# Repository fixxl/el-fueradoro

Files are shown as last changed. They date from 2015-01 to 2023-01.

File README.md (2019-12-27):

# el-fueradoro

This project contains a remotely controlled ignition system for audio-fireworks based on ATmega328P and RFM69CW.
Further information (in German) is given in [the user manual](https://cdn.jsdelivr.net/gh/fixxl/el-fueradoro@master/Manual/fueradoro.pdf).

What the system is capable of doing can be seen in our [new year's fireworks 2015](https://vimeo.com/116115628), [new year's fireworks 2016](https://vimeo.com/150594996), [new year's fireworks 2017](https://www.youtube.com/watch?v=Rc5oZRx3s50), [new year's fireworks 2018](https://www.youtube.com/watch?v=unH9tJSg1mw), and [new year's fireworks 2019](https://www.youtube.com/watch?v=GiKSdqZKpVQ).

Copyright:

All parts of the project are licensed under: https://creativecommons.org/licenses/by-nc/3.0/de/

Usage to perform commercial firework shows is explicitly granted.
Selling hard- and software derived from this project and usage within commercial systems is prohibited.

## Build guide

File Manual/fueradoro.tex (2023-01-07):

\documentclass[paper=a4, parskip, numbers=noenddot, toc=listof, headsepline]{scrbook}

\usepackage[hang]{caption}
\usepackage{subcaption}
\usepackage{microtype, textcomp}
\usepackage{longtable, xltabular}
\usepackage[intlimits]{mathtools}
\usepackage{amsfonts, amssymb, array, scrlayer-scrpage, multirow}
\usepackage{fontspec}
\usepackage{unicode-math, icomma}
\usepackage{polyglossia}
\setdefaultlanguage[spelling=new]{german}
\usepackage[autostyle]{csquotes}
\usepackage[per-mode=fraction, locale=DE, detect-all=true, binary-units=true]{siunitx}
\usepackage[scale=.73]{geometry}
\usepackage{graphicx}
\usepackage{datetime}
\usepackage[backend=biber, isbn=false, doi=false, eprint=false, url=true, safeinputenc, defernumbers=false]{biblatex}
\usepackage[unicode=true, colorlinks=false, breaklinks=true, pdfborder={0 0 0}]{hyperref}
\usepackage{bookmark}

\newcommand{\origttfamily}{}
\let\origttfamily=\ttfamily
\renewcommand{\ttfamily}{\origttfamily \hyphenchar\font=`\-}
\defaultfontfeatures{Ligatures=TeX}
\renewcommand{\dateseparator}{.}
\newcolumntype{C}{>{\centering\arraybackslash}X}

\setmainfont{Tex Gyre Termes}
\setmathfont{Tex Gyre Termes Math}
\setsansfont{Latin Modern Sans}[Scale=MatchLowercase]
\setmonofont{LMMonoLt10-Bold}[Scale=MatchLowercase]

\newfontfamily\Driftwood{Drift Wood}

\newcommand{\pic}{\emph{Pyro Ignition Control}}
\newcommand{\anlage}{\emph{El Fueradoro}}
\newcommand{\REF}{\emph{raspEasyFire}}
\newcommand{\myangle}{\ifthispageodd{angle=-90}{angle=90}}

\newdateformat{mmyyyydate}{\twodigit{\THEMONTH}-{\THEYEAR}}

%% Seitenstil-Einstellung
\renewcommand{\chapterpagestyle}{plain}
\pagestyle{scrheadings}
\renewcommand*{\partmarkformat}{}
\automark[part]{part}
\clearpairofpagestyles
\ohead[\pagemark]{\pagemark}
\lohead[]{\textnormal\headmark}
\rehead[]{\anlage}

\hyphenation{Putty-tel, Fuera-doro}

\setuptoc{toc}{totoc}

\hypersetup{pdfinfo={
		Title=\anlage + \REF,
		Author=Felix Pflaum,
		Subject={User manual for remotely controlled firework ignition system},
		Keywords={}}
}

\makeatletter
\@removefromreset{footnote}{part}
\@removefromreset{footnote}{chapter}
\makeatother

\DeclareSIUnit{\dBm}{dBm}

\begin{document}
\begin{titlepage}
	\thispagestyle{empty}
	{\sffamily\LARGE Benutzerhandbuch{\hfill}Dokumentation{\hfill}Aufbauanleitung}\\ \hrule \vspace*{\fill}
    \begin{center}
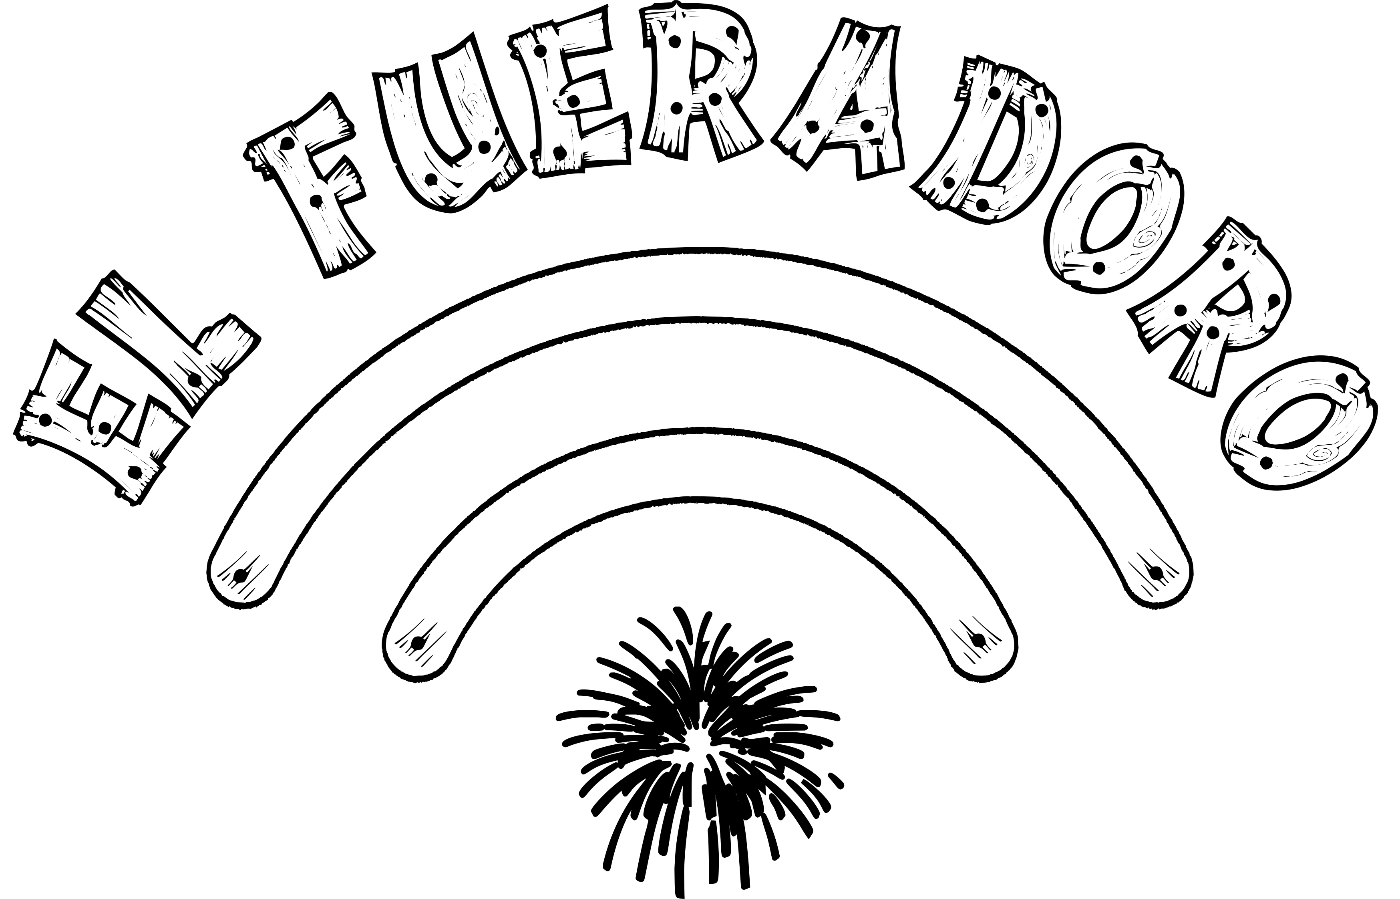
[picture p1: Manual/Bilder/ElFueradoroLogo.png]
    	 \\ \vspace*{\fill}
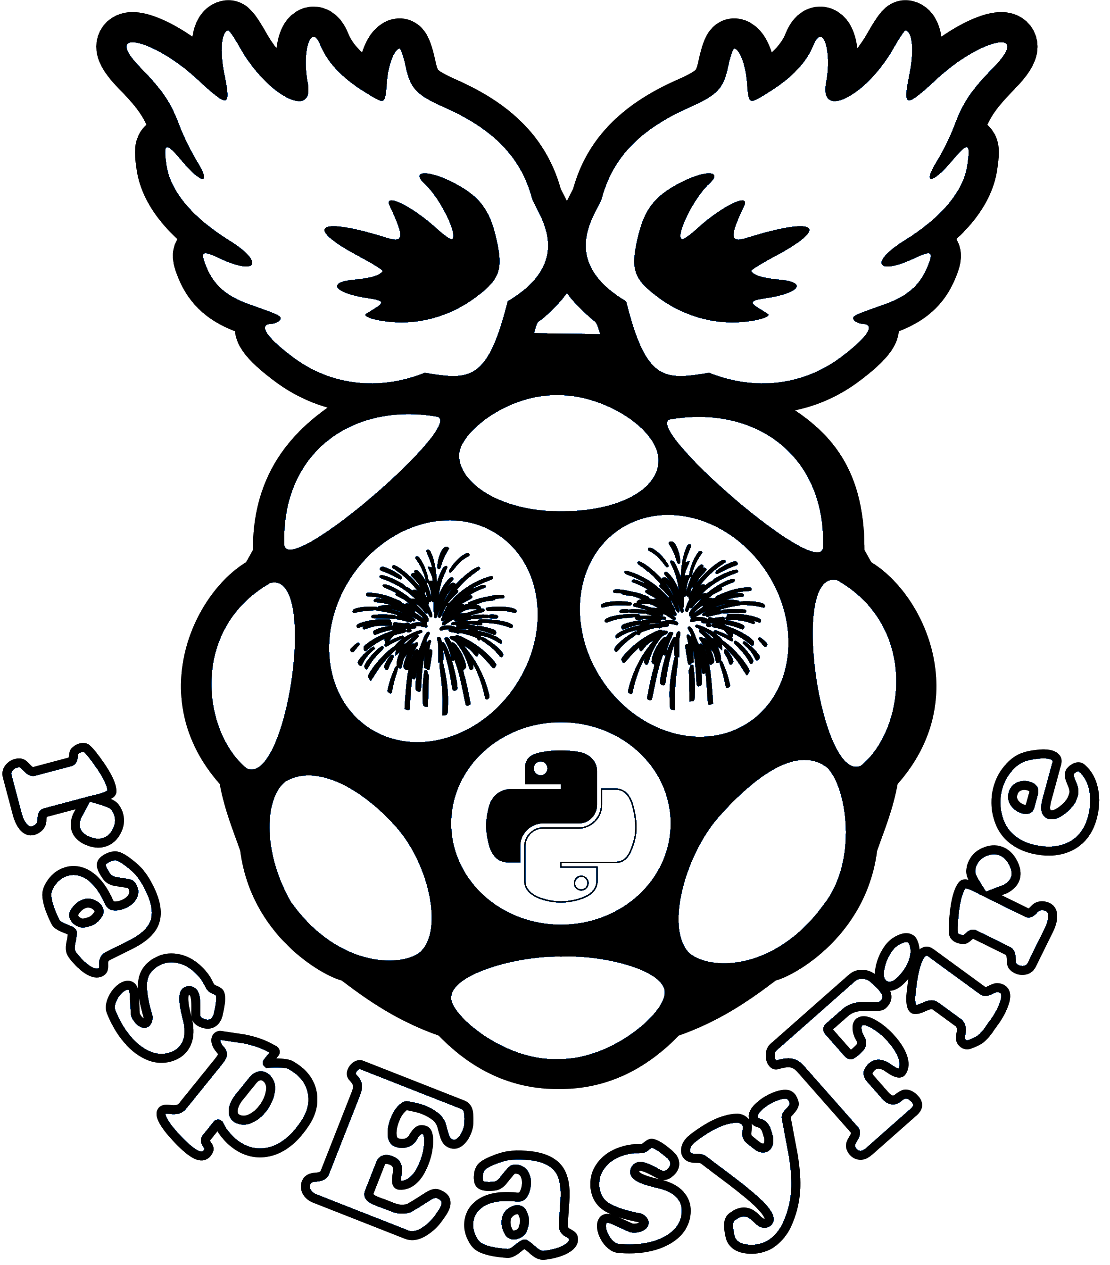
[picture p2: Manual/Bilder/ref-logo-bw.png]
		   \\ \vspace*{\fill}
		{\LARGE \sffamily Funkgesteuertes Zündsystem für Feuerwerke}
	\end{center}
	\vspace*{\fill}
	\hrule
	\begin{center}
		\sffamily\Large Felix Pflaum (\href{mailto:f.pflaum@gmail.com}{f.pflaum@gmail.com})\\
		\normalsize \ddmmyyyydate\today, \currenttime
	\end{center}
\end{titlepage}
%
\chapter*{Wichtige Hinweise}
	\addcontentsline{toc}{chapter}{Wichtige Hinweise}

	Vor Inbetriebnahme sollte in jedem Fall diese Anleitung gelesen und verstanden werden! Speziell die folgenden, weiter hinten in der Anleitung detaillierter ausgeführten Hinweise müssen beachtet werden, um Personenschäden oder Beschädigungen an den Geräten zu vermeiden:

	{\bfseries
	\begin{enumerate}
		\item
		      Bei den Zündboxen der ersten Generation liegt das Metallgehäuse des SMA-Antennen\-anschlusses an der Oberseite der Zündbox auf Massepotential, die roten Anschlussklemmen nach dem Einschalten und unter Umständen auch noch Minuten nach dem Ausschalten bei \SI{22,5}{\volt}. Ein Kurzschluss zwischen diesen beiden Punkten ist daher unbedingt zu vermeiden, um Schäden an der Schaltung und ungewollte Zündungen zu verhindern. Daher, sofern der Antennenanschluss nicht isoliert ist, beim Anschließen die Anzünder immer zuerst mit der schwarzen Klemme, danach mit der roten verbinden, beim Abklemmen zuerst das Kabel an der roten, dann das an der schwarzen Klemme lösen. Weiterhin sollte man die Zündbox erst in ihrer endgültigen Position einschalten, so dass ein unbeabsichtigtes Herausziehen der Kabel tunlichst ausgeschlossen ist. Sicherheitshalber kann auch der SMA-Stecker nach dem Anschrauben mit Klebeband isoliert werden. Bei den Zündboxen ab der zweiten Generation sind schaltungstechnische Maßnahmen getroffen, um den Strom im Kurzschlussfall zu begrenzen und ein Auslösen der Anzünder bei Verbindung zwischen roter Klemme und Antennenanschluss im nicht-scharfgeschalteten Zustand auszuschließen.
		\item
		      Devices niemals ohne angeschlossene Antenne einschalten, um Rückreflexionen an offenen Steckern/Buchsen zu vermeiden, welche die Sendeendstufe zerstören könnten.
		\item
		      Keine Softwareupdates an Zündboxen durchführen, solange Anzünder angeschlossen sind, da das Verhalten nach einem fehlgeschlagenen Update unvorhersehbar ist.
	\end{enumerate}
	}

	Trotz aller Sorgfalt bei der Entwicklung von Hard- und Software sowie ausgiebigen Tests seitens der Entwickler kann~-- auch aufgrund nicht vorhandener Kontrollmöglichkeiten über die Qualität der letztlich verbauten Komponenten und der handwerklichen Durchführung~-- keinerlei Garantie für Sicherheit und Funktionalität von {\anlage} und {\REF} sowie keine Haftung für Sach- und Personenschäden, welche sich direkt oder indirekt aus dem Einsatz von {\anlage} und {\REF} ergeben, übernommen werden.

	Es werden mit {\anlage} dem Anwender lediglich Schaltpläne, Layouts und Programmcode sowie Hinweise zu Aufbau und Verwendung einer elektronischen Funkzündanlage, welche er frei weiter verbreiten und~-- selbstverständlich auf eigene Gefahr~-- verändern darf, zur Verfügung gestellt. {\anlage} und {\REF} sind und bleiben Hobby-Bastelprojekte, keine geprüften oder in irgendeiner Form zertifizierten Produkte!

	Der Umgang mit Feuerwerkskörpern und explosivem Material unterliegt in Deutschland und der EU harmonisierten wie auch nationalen gesetzlichen Restriktionen, deren Einhaltung im Verantwortungsbereich des Anwenders liegt. Insbesondere auf Sicherheitsabstände und persönliche Schutzausrüstung ist zu achten. {\anlage} und {\REF} dürfen nicht von Personen unter 18 Jahren bedient werden.
	%

	\tableofcontents
	%
\part{Benutzerhandbuch}

	\chapter{Das System}

		\anlage{} ist eine Eigenentwicklung zur automatisierten Zündung von Feuer\-werks\-choreo\-gra\-phien per Computer und Funk, der Name {\anlage} leitet sich als Kofferwort aus den spanischen Wörtern \emph{fuego}, \emph{radio} und \emph{oro} her und bedeutet frei übersetzt daher so etwas wie \enquote{Goldenes Funkfeuer}. Sie wurde zur Verwendung mit der frei verfügbaren Software {\pic} von Yannic Wilkening (Version 1.4.5 und später) geplant.

		Das ursprüngliche System bestand aus einer mit einem PC verbundenen Transmitterbox, welche die von {\pic} generierten Zündbefehle per Funk an die Zündboxen weitergibt, und einer oder mehreren Zündboxen mit je 16 oder 32 Kanälen zur elektrischen Zündung. Dieser klassische Aufbau des Systems ist schematisch in Abbildung~\ref{fig:system} gezeigt. Die reine Transmitterbox wird nicht zwingend benötigt; es kann alternativ auch eine Zündbox per Kabel mit dem PC verbunden werden und neben ihrer originären Aufgabe auch die Transmitteraufgaben bewältigen.

		Mittlerweile hat sich als Standalone-Lösung, also als Ersatz für Transmitterbox und PC, der Raspberry-Pi-Transmitter \emph{raspEasyFire} etabliert, welcher einen deutlich größeren Funktionsumfang bietet als die ursprüngliche Variante.

		\begin{figure}
			\centering
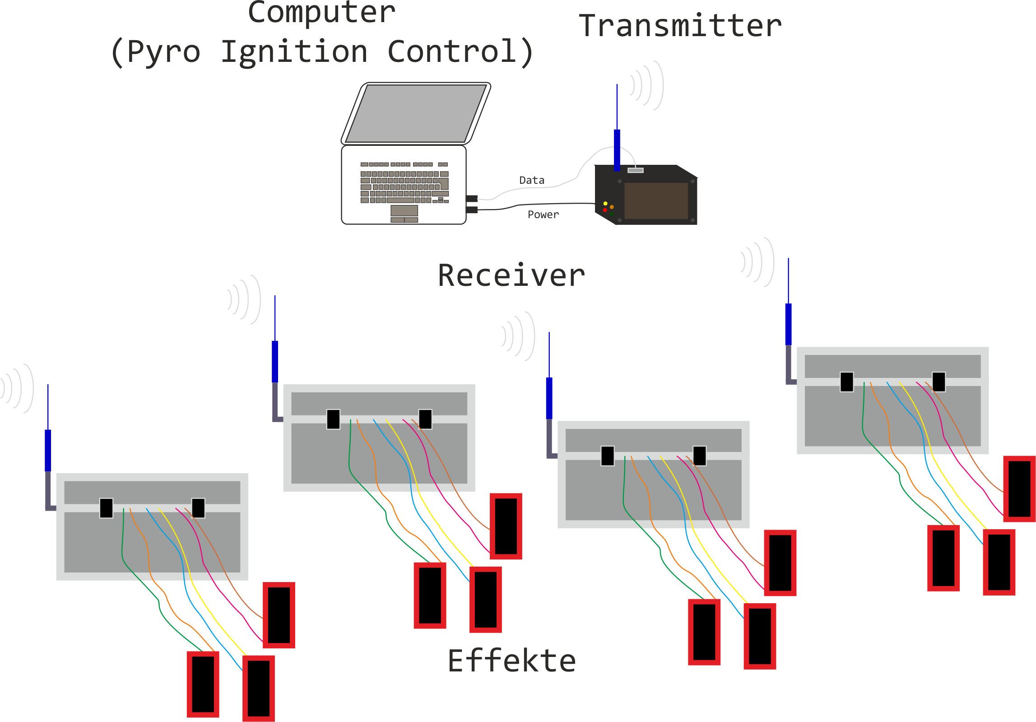
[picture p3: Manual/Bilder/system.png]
			
			\caption{Systemübersicht \anlage}
			\label{fig:system}
		\end{figure}

		Um möglichst große Flexibilität bei der Gestaltung eines Feuerwerks mit {\anlage} zu gewährleisten, was z.\,B. die Anzahl der verwendeten Zündboxen oder auch die Tatsache angeht, dass man identische Effekte gerne zeitgleich an zwei weiter voneinander entfernten Orten zünden möchte, können den Boxen per Software zwei Kennnummern (Unique-ID und Slave-ID) zugewiesen werden. Genaueres dazu findet sich im Abschnitt~\ref{ch:kommunikationpc}.

		Transmitterbox und Zündbox sind in Abbildung~\ref{fig:transmitter} bzw.~\ref{fig:zuendbox} mit ihren wesentlichen Bestandteilen gezeigt. Sie werden im weiteren Text unter dem Begriff \enquote{Devices} zusammengefasst, falls sich Aussagen auf beide Teile beziehen, und in den folgenden Kapiteln näher beschrieben.

		Um den Raspberry-Pi-basierten Transmitter \emph{raspEasyFire} geht es in Abschnitt~\ref{ch:raspeasyfire} ab Seite~\pageref{ch:raspeasyfire}.

		\section{Aufbau}

			Detailliertere Infos zum Aufbau erhalten interessierte Leser in den nächsten Teilen dieses Dokuments ab Seite~\pageref{part:dokumentation}. An dieser Stelle soll nur kurz auf die Funktionalität eingegangen werden. Herzstück aller Devices ist der 8-bit-Mikrocontroller \texttt{ATmega328P} von Atmel, welcher die verschiedenen Peripheriebausteine kontrolliert. In jedem Device befinden sich ein Funkmodul \texttt{RFM69CW} oder \texttt{RFM69HCW} von HopeRF, welches die drahtlose Kommunikation zwischen den einzelnen Devices übernimmt, ein RS232-Treiberbaustein \texttt{MAX202} mit an die Gehäuseaußenseite geführter Sub-D-Buchse bzw. ab der dritten Generation ein USB-UART-Transceiver \texttt{MCP2221} mit USB-Buchse zur Kommunikation zwischen Mikrocontroller und PC sowie vier Status-LEDs.

			Die Transmitterbox ist mit einem LC-Display mit 20 Spalten und 4 Zeilen ausgestattet.

			In den Zündboxen befinden sich zwei vom Mikrocontroller gesteuerte kaskadierte Schieberegister \texttt{74HC595}, welche mit ihren insgesamt 16 bzw. 32 Ausgängen 16 bzw. 32 Feldeffekttransistoren vom Typ \texttt{IRF3708} für die Zündung ansteuern, außerdem ist auf der Platine mit dem \texttt{MC33063} bzw. einem fertigen Modul mit dem \texttt{XL6009} ein Hochsetzsteller zur Erzeugung einer höheren Zündspannung integriert sowie ein Schlüsselschalter zum Scharfschalten der Boxen. Bei den ersten beiden Generationen liegt parallel zur Drain-Source-Strecke jedes Feldeffekttransistors eine LED mit Vorwiderstand, um zu signalisieren, an welchen Kanälen Anzünder angeschlossen sind. Ab der dritten Generation werden diese Kanal-LEDs über LED-Treiber \texttt{DM13A} angesteuert, um genauere Informationen über den Kanalzustand und weitere Funktionen darstellen zu können.

		\section{Transmitter und Zündboxen}

			\begin{figure}
				\centering
				\begin{subfigure}[t]{0.405\textwidth}
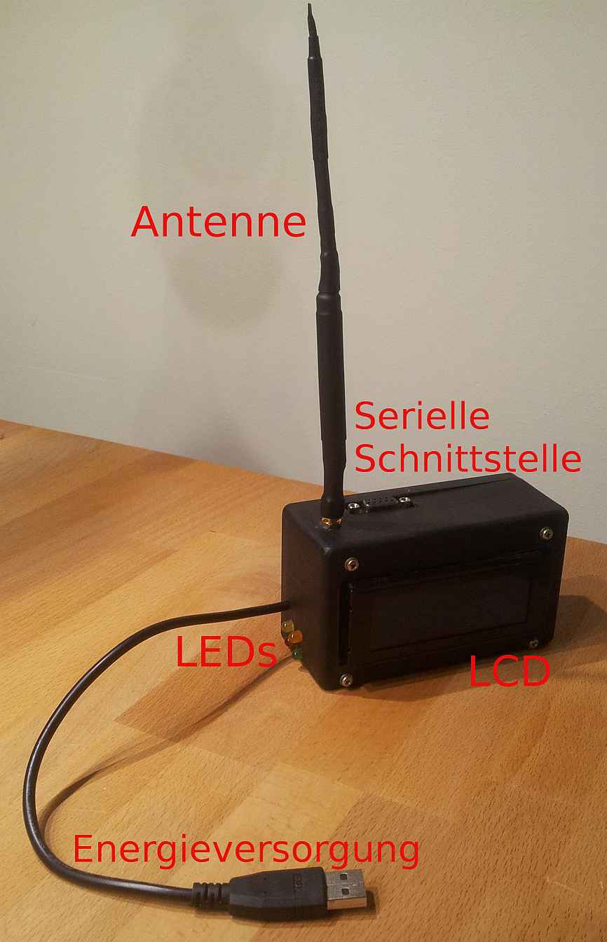
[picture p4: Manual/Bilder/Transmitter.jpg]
					
					\caption{Transmitter}
					\label{fig:transmitter}
				\end{subfigure}
				\begin{subfigure}[t]{0.55\textwidth}
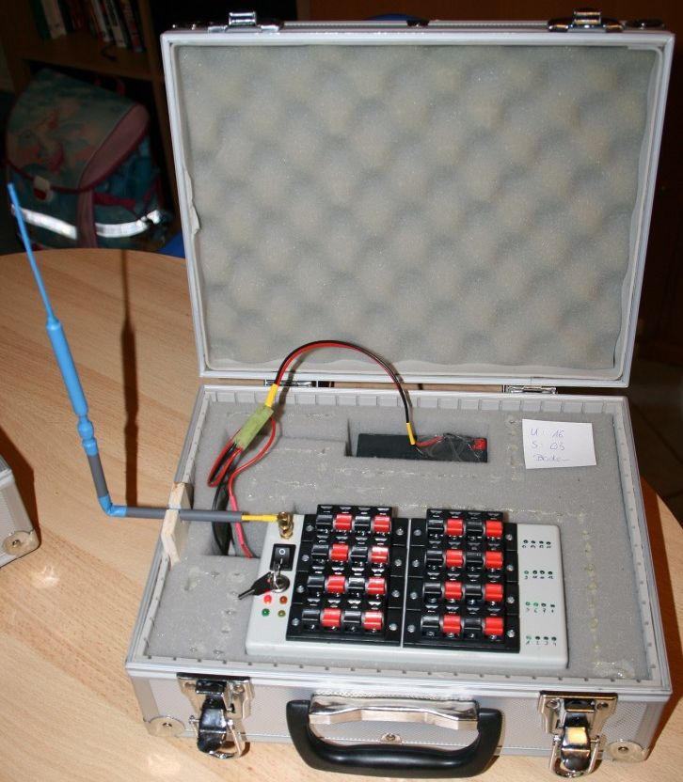
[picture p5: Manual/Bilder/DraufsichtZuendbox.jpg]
					
					\caption{Zündbox von oben, eingebettet in Koffer}
					\label{fig:zuendbox}
				\end{subfigure}
				%
				\caption{Die Devices von {\anlage}}
			\end{figure}

			Die in Abbildung~\ref{fig:transmitter} gezeigte Transmitterbox dient dazu, die Zündbefehle des PCs per Funk an die über das Gelände verteilt stehenden Zündboxen weiterzuleiten sowie das komplette Funksystem zu überwachen. Hierzu ist im Inneren der Transmitterbox sowie der Zündboxen ein Funkmodul für das~-- im Rahmen der Vorschriften der jeweiligen nationalen Aufsichtsbehörde, in Deutschland der Bundesnetzagentur~-- frei nutzbare Frequenzband um $\SI{868}{\mega\hertz}$ verbaut, das ISM-Band um $\SI{433}{\mega\hertz}$ kann ebenfalls genutzt werden. Die Datenübertragung vom PC geschieht über eine serielle Schnittstelle.

			Die Zündboxen, in Abbildung~\ref{fig:zuendbox} dargestellt, empfangen die Anweisungen und zünden die einzelnen Kanäle. Die hier gezeigte Variante der Zündbox enthält 16 einzeln ansteuerbare Zündkanäle. Jeweils eine rote und eine schwarze Klemme bilden zusammen einen Zündkanal, die Nummerierung beginnt links unten mit Kanal 1 und endet rechts oben mit Kanal 16. Alle roten Klemmen sind nach dem Einschalten unmittelbar mit einer Gleichspannung von $\SI{22,5}{\volt}$ verbunden, die schwarzen Klemmen mit dem Drain-Anschluss eines von 16~n-Kanal-MOSFETs.

			Welches der beiden Kabel an welcher Klemme des Zündkanals angeschlossen wird, spielt keine Rolle, da es sich bei den Anzündern um passive elektrische Bauelemente handelt, die in beiden Richtungen gleichermaßen von Strom durchflossen werden können. Die Verdrahtung sollte aber stets im ausgeschalteten Zustand der Boxen erfolgen und aus Sicherheitsgründen immer in folgender Reihenfolge:
			\begin{itemize}
				\item
				      Beim Anklemmen der Kabel zuerst ein Kabel an der schwarzen Klemme befestigen, anschließend das andere an der roten!
				\item
				      Beim Lösen der Kabel zuerst das Kabel von der roten Klemme lösen, anschließend das von der schwarzen!
			\end{itemize}
			Dies ist der Tatsache geschuldet, dass bei der ersten Generation der Zündboxen, wenn eine Seite des Zündkanals fest mit der Zündspannung, d.\,h. einer roten Klemme verbunden ist, ein frei baumelndes zweites Kabel durch Berührung eines Bauteils auf Massepotential, z.\,B. der Antennenbuchse oder der Überwurfmutter des gewinkelten SMA-Steckers, einen Kurzschluss und somit eine Zündung auslösen würde~-- selbst dann, wenn die Box nicht scharf geschaltet ist! Ab der zweiten Generation der Zündboxen ist dieses Manko behoben.

			Bei den Zündboxen der ersten und zweiten Generation ist parallel zur üblicherweise sperrenden Drain-Source-Strecke jedes MOSFETs ist eine grüne LED mit Vorwiderstand geschaltet, welcher den Strom durch den LED-Zweig auf unter \SI{5}{\milli\ampere} begrenzt, so dass ein Zünden über die LED ausgeschlossen ist. Sobald die zugehörige schwarze Klemme mit einer roten Klemme~-- die Zuordnung kann beliebig erfolgen, obwohl zwecks Übersichtlichkeit natürlich ratsam ist, die nebeneinander liegenden Klemmen zu nutzen~-- verbunden ist, also ein geschlossener Strompfad von $\SI{22,5}{\volt}$ zur Schaltungsmasse besteht, wird dies durch Leuchten der zur schwarzen Klemme gehörigen grünen LED signalisiert. Ein Leuchten der grünen LED ist dabei lediglich ein Indikator, dass \enquote{etwas} am jeweiligen Kanal angeschlossen ist, eine Aussage, ob der Widerstand des angeschlossenen Anzündernetzwerks gering genug ist, um eine Zündung auszulösen, wird durch die LED ausdrücklich nicht getroffen.

			Anders verhält sich dies bei den Zündboxen der dritten Generation: Hier werden die Widerstände der einzelnen Kanäle periodisch bestimmt und die zugehörige grüne LED nur dann aktiviert, wenn der Kanalwiderstand ausreichend gering ist.

		\section{Energieversorgung}

			Die in unmittelbarer Nähe des zu steuernden PCs platzierte Transmitterbox bezieht ihre nötige elektrische Energie aus dem USB-Port eines PCs. Das fest mit der Transmitterbox verbundene USB-Kabel dient ausschließlich diesem Zweck. Sie verfügt über keinen Ein/Aus-Schalter, sondern ist eingeschaltet, solange sie mit dem USB-Port verbunden und der PC eingeschaltet ist. Da der USB-Port \enquote{angezapft} wird, ohne in der sonst üblichen Weise mit dem Controller zu kommunizieren, empfiehlt sich, die USB-Verbindung erst nach komplett abgeschlossenem Bootvorgang herzustellen und vor dem Herunterfahren des Rechners wieder zu trennen.

			Aufgrund der anzunehmenden Platzierung der Zündboxen im freien Feld, abseits von Steckdosen und anderen Energiequellen werden sie über eine Batterie versorgt. \textbf{Um ordnungsgemäße Funktionalität zu garantieren und Schäden an der Schaltung zu vermeiden, muss die Batteriespannung zwischen \SI{8}{\volt} und \SI{15}{\volt} liegen!} Empfohlen wird die Verwendung eines Blei-Vlies-Akkus mit Nennspannung \SI{12}{\volt}, wie er auch in Abbildung~\ref{fig:zuendbox} über der Zündbox zu erahnen ist.

		\section{Die Status-LEDs}
			\label{ch:leds}

			Alle Devices verfügen über vier Status-LEDs. Bei den Transmitterboxen liegen sie direkt neben dem Kabel für die Energieversorgung auf der Seite, bei den Zündboxen auf der Oberseite. Diese sind mit ihrer Bedeutung in Tabelle~\ref{tab:statusleds} aufgeführt und leuchten, wenn das jeweilige Device die mit der LED verknüpfte Tätigkeit ausführt.

			\begin{table}
				\centering
				\begin{xltabular}{.8\textwidth}[c]{lXl}
					\hline\hline
					\textbf{Farbe} & \textbf{Funktion}                           & \textbf{Startup-Faktor} \\ \hline
					orange         & Funkmodul empfängt                          & 4                       \\
					grün           & Funkmodul sendet                            & 2                       \\
					gelb           & Daten kommen über serielle Schnittstelle an & 1                       \\
					rot            & Device ist scharf geschaltet                & 8                       \\ \hline\hline
				\end{xltabular}
				\caption{Farben und Funktionen der Status-LEDs}
				\label{tab:statusleds}
			\end{table}

			Während des Bootvorgangs wird durch die Status-LEDs dem Benutzer die aktuell eingestellte Slave-ID der Box in Binärdarstellung visualisiert. Hierzu gehen zunächst nacheinander schnell die gelbe, grüne, orange und rote LED an, ehe zwei Sekunden lang eine Kombination der Status-LEDs aufleuchtet. Anschließend gehen nacheinander schnell die rote, orange, grüne und gelbe LED an, bevor erneut zwei Sekunden lang eine weitere Kombination der Status-LEDs leuchtet. Der Zahlenwert, welcher durch eine Status-LED repräsentiert wird, ist in Tabelle~\ref{tab:statusleds} aufgeführt. Die eingestellte Slave-ID entspricht der Summe aus dem Wert der ersten Kombination multipliziert mit 16 und der zweiten Kombination.

			Beispiel: Leuchtet nach dem ersten Lauflicht zunächst zwei Sekunden lang nur die gelbe LED und nach der zweiten Lauflichtsequenz leuchten zwei Sekunden die orange und grüne LED zusammen, ergibt sich die Slave-ID zu $16 {\cdot} 1 + 4 + 2 = 22$.

			Ab der dritten Generation werden während dieser Sequenz auch alle Kanal-LEDs eingeschaltet, um defekte LEDs erkennen zu können.

			Das nach kurzer Pause folgende Blinken der grünen LED signalisiert dann die Statusmeldung per Funk an allen anderen Devices.

			Bei einem Zündvorgang leuchten an der Zündbox für die einstellbare Dauer der Zündung~-- näheres hierzu im Abschnitt~\ref{sec:igniter}~-- alle vier LEDs, bei Zündboxen ab der dritten Generation zusätzlich auch die zum gezündeten Kanal zugehörige Kanal-LED.

		\section{Das LCD des Transmitters}

			Aktuelle Statusanzeigen werden beim Transmitter auf dem LC-Display ausgegeben. Ein Beispiel zeigt Abbildung~\ref{fig:senderanzeige}. In Zeile 1 wird hinter der Abkürzung \enquote{Tx} (Transmitted) der letzte gesendete Befehl angezeigt, in Zeile 2~-- im Bild nicht zu sehen~-- ggf. hinter der Abkürzung \enquote{Rx} (Received) die letzte empfangene Rückmeldung (angeforderte Parameter). Die am Ende der zweiten Zeile erscheinende negative Zahl steht für den RSSI-Wert beim Empfang in dBm.

			\begin{figure}
				\centering
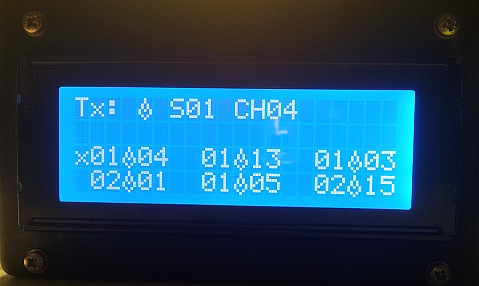
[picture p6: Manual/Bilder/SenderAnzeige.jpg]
				
				\caption{LCD während der Show}
				\label{fig:senderanzeige}
			\end{figure}

			In den Zeilen 3 und 4 werden die letzten sechs gesendeten Kommandos aufgelistet. Zwei zweistellige Zahlen getrennt durch ein Flammensymbol stehen dabei für einen Zündbefehl. Die erste Zahl gibt die Slave-ID, die zweite den zu zündenden Kanal an. Für den Fall, dass eine Aufforderung zur Identifikation gesendet wurde, erscheint \enquote{IDENT}, für eine Aufforderung zur Temperaturmessung \enquote{TEMP}. Das \enquote{x} steht immer vor dem bis dato letzten Befehl, springt also mit jedem neuen Befehl eine Stelle weiter.

			Alle Zeilen werden nach einer bestimmten Zeit automatisch gelöscht.

		\section{Schalter an den Zündboxen}

			Die Zündboxen verfügen, wie in Abbildung~\ref{fig:schalterzuend} zu erkennen, über zwei Schalter, einen schwarzen Wippschalter zum Ein- und Ausschalten der Energieversorgung sowie einen Schlüsselschalter, um die Zündbox \enquote{scharf} zu schalten.

			\begin{figure}[!b]
				\centering
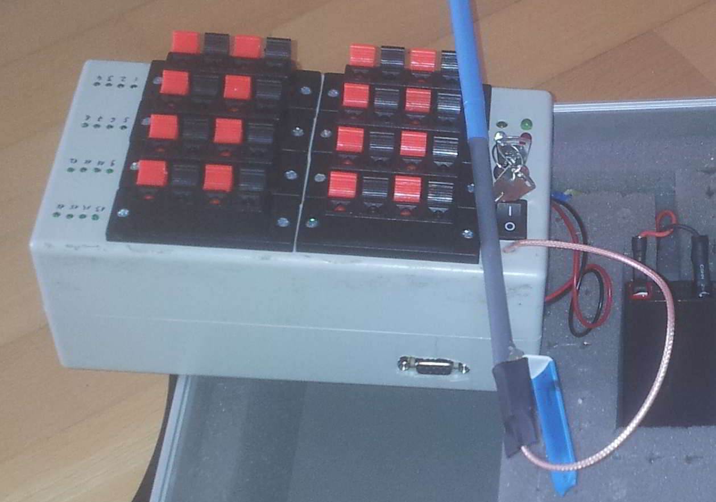
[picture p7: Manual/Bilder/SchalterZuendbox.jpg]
				
				\caption{Schalter und serielle Schnittstelle an der Zündbox}
				\label{fig:schalterzuend}
			\end{figure}

			Die Scharfschaltung durch den Schlüsselschalter geschieht auf die Weise, dass durch eine Zustandsabfrage vor der Zündung letztere nur ausgeführt wird, wenn das Schloss auf den grünen Punkt am Gehäuse zeigt. Befindet sich der Schlüssel in waagrechter Stellung und zeigt auf den roten Punkt, so ist der Schalter geöffnet und Zündbefehle werden von der Box ignoriert. Für das Scharfschalten der Box ist der Anwender selbst verantwortlich.

			Ob Boxen scharf geschaltet sind, ist an der Box~-- wie in Abschnitt~\ref{ch:leds} ausgeführt~-- durch das Dauerleuchten der roten Status-LED erkennbar, kann aber auch durch eine Identifizierungsabfrage ausgelesen werden (siehe Abschnitt~\ref{sec:config}).

	\chapter{Vorbereitung des PCs}

		Zur Kommunikation mit einem Computer verfügen alle Devices über eine serielle Schnittstelle bzw. ab der dritten Generation über einen USB-Anschluss. {\pic} sollte ohnehin auf dem Rechner installiert sein, für die serielle Kommunikation gibt es für Windows zudem zahlreiche Terminalprogramme.

		\section{Installation eines USB-RS232-Adapters}
			\label{sec:usbadapter}

			Zunächst steht man allerdings in der Regel vor dem Problem, dass zwar die Devices eine serielle Schnittstelle besitzen, moderne Rechner aber nicht mehr mit dem früher standardmäßig verbauten 9-poligen Sub-D-Stecker der RS232-Schnittstelle ausgestattet sind. Diese wurden seit dem Ende der 1990er-Jahre von den USB-Schnittstellen verdrängt. Sollte wider Erwarten am einzusetzenden Rechner ein derartiger Anschluss vorhanden sein, können die nächsten Absätze übersprungen und der COM-Port direkt im Gerätemanager anhand von Tabelle~\ref{tab:seriell} konfiguriert werden. Wer nur über USB-Ports verfügt, lese unmittelbar weiter.

			Weil in vielen Bereichen noch immer auf RS232 zurückgegriffen wird, existieren Adapterkabel wie in Abbildung~\ref{fig:transmitter} mit USB-Anschluss für den Rechner und einem 9-poligen RS232-Stecker für den Anschluss an der Peripherie, also die Devices von {\anlage}. In diesen Adapterkabeln ist ein Chip verbaut, um die Signalumsetzung von USB auf RS232 und umgekehrt zu bewerkstelligen. Übliche verwendete Chips sind der CH340\footnote{Treiber CH340/341: \url{http://wch.cn/download/list.asp?id=5}}, welcher sich in vielen über eBay aus China angebotenen Modellen befindet, der Prolific PL2303\footnote{Falls die automatische Treiberinstallation unter Windows fehlschlägt, funktioniert~-- mit zeitweiligen Aussetzern~-- oft der Treiber unter: \url{http://www.cartft.com/support/drivers/TFT/tftdrivers/GPS/PL2303_Prolific_GPS_1013_20090319.zip}} in verschiedenen Versionen oder~-- bei edleren und somit auch teureren Varianten~-- der uneingeschränkt zu empfehlende FTDI232, mit welchem die in den folgenden Abschnitten beschriebenen Probleme nicht auftreten sollten.

			Das Plug-and-Play-Traum\-szenario, dass sich der Adapter bei der Verbindung des USB-Steckers mit dem Rechner automatisch korrekt installiert, tritt gerade bei den günstigen Adaptern leider nur sehr selten ein. Die in den Fußnoten verlinkten Treiber sollten, sofern die automatische Treiberinstallation von Windows versagt, ihren Dienst tun, müssen allerdings teilweise mit sanfter Gewalt installiert werden. Hat man die Installation erfolgreich absolviert, sollte bei angeschlossenem Adapterkabel ein neuer Eintrag in der Art von Abbildung~\ref{fig:geraetemanager} im Gerätemanager auftauchen.

			Weil viele Chips dazu tendieren, sich beim Anschluss an immer wieder andere USB-Ports neu zu installieren bzw. eine andere COM-Port-Nummer anzunehmen, wird empfohlen, für den USB-RS232-Adapter stets denselben USB-Steckplatz zu nutzen.

			\begin{figure}
				\centering
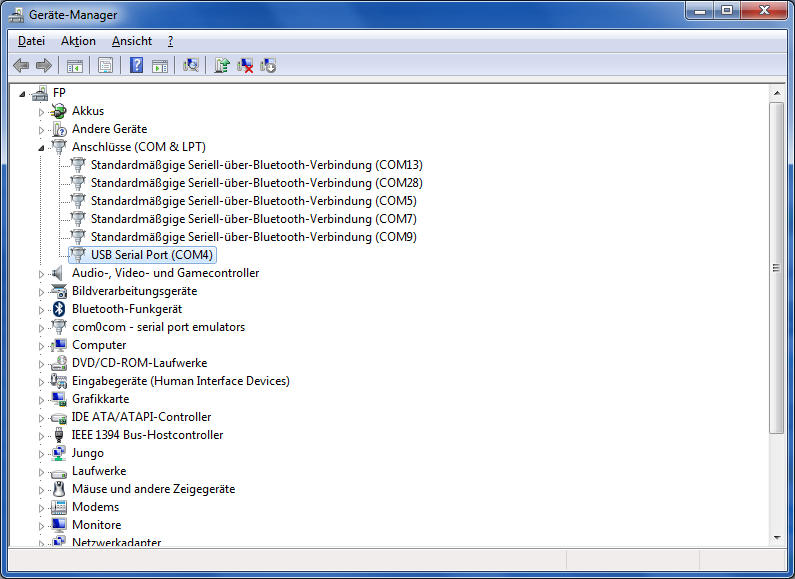
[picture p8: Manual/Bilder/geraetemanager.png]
				
				\caption{Eintrag des USB-RS232-Adapters im Gerätemanager}
				\label{fig:geraetemanager}
			\end{figure}

			Durch Doppelklick auf den Eintrag und den Reiter Anschlusseinstellungen kann die nun vorhandene serielle Schnittstelle unter Windows konfiguriert werden. Um Kompatibilität mit {\pic} zu gewährleisten, ist das Hauptfenster nach Tabelle~\ref{tab:seriell} zu konfigurieren.

			\begin{table}[b]
				\begin{center}
					\begin{xltabular}
						{7cm}[c]{Xl}
						\hline\hline
						Bits pro Sekunde & 9600  \\
						Datenbits        & 8     \\
						Parität          & keine \\
						Stoppbits        & 1     \\
						Flusssteuerung   & keine \\ \hline\hline
					\end{xltabular}
					\caption{Konfiguration der seriellen Schnittstelle}
					\label{tab:seriell}
				\end{center}
			\end{table}

			Unter der Schaltfläche \enquote{Erweitert} kann man zudem die Puffer ausschalten, was aber nicht zwingend notwendig ist und die Funktionsweise normalerweise weder positiv noch negativ beeinflusst, sowie die Portnummer für den neu geschaffenen COM-Port einstellen.

		\section{Einrichtung des Terminalprogramms}

			Hardware- und treiberseitig steht einer erfolgreichen Kommunikation von Rechner und Devices nun nichts mehr im Wege, für eine komfortable Unterhaltung außerhalb von {\pic} fehlt aber noch die entsprechende Software. Empfohlen wird die Verwendung des kostenlosen Programms \emph{Puttytel}\footnote{Herunterzuladen unter: \url{http://www.chiark.greenend.org.uk/~sgtatham/putty/download.html}}, mit welchem auch die im Rahmen dieser Anleitung gezeigten Beispiele durchgeführt werden. Es besteht nur aus einer einzigen ausführbaren Datei.

			\begin{figure}
				\centering
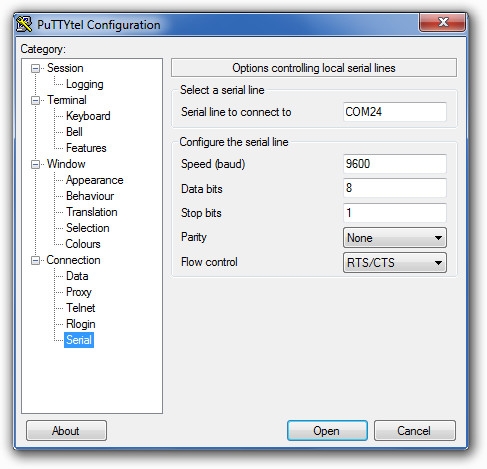
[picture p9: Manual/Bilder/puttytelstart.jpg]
				
				\caption{Einstellungen für \texttt{Puttytel}}
				\label{fig:puttytelstart}
			\end{figure}

			\texttt{Puttytel} kann per Doppelklick gestartet werden, woraufhin man zu einem Startbildschirm, der Kategorie \enquote{Session} gelangt. Man wählt in der linken Spalte unten links \enquote{Serial} und stellt die Parameter~-- analog zur Konfiguration des COM-Ports nach Tabelle~\ref{tab:seriell}~-- wie in Abbildung~\ref{fig:puttytelstart} ein. Anschließend muss man in der linken Spalte zurück auf \enquote{Session} gehen und dort im rechten Teil des Fensters \enquote{Serial} als \enquote{Connection Type} wählen, ehe man die serielle Verbindung per Klick auf \enquote{Open} starten kann. Vor dem Start der Verbindung sollte man zudem das verbundene Device mit Strom versorgen, damit dieses seine Kommunikationsschnittstelle vor Beginn des Datenaustauschs initialisieren kann.

			Um bei \texttt{Puttytel} nicht immer alle Einstellungen per Hand vornehmen zu müssen, bietet sich an, unter Windows eine Verknüpfung auf \texttt{puttytel.exe} zu erstellen und in den Ver\-knüpfungs\-eigen\-schaften als Ziel anzugeben:
			\begin{center}
				\verb|"c:\programme\puttytel\puttytel.exe" -serial com24 -sercfg 9600,8,1,n,R|
			\end{center}

			Die ohne Leerzeichen auf \enquote{com} folgende Zahl ist natürlich entsprechend dem verwendeten seriellen Anschluss (COM5, COM37, \dots) anzupassen.

		\section{Einrichtung von \pic}
			\label{sec:piceinrichtung}

			Um eine reibungslose Kommunikation zwischen {\pic} und {\anlage} sicherzustellen, muss in {\pic} als wesentliche Einstellung unter dem Menüpunkt \enquote{Einstellungen $\rightarrow$ Optionen} im Reiter \enquote{Output}~-- gezeigt in Abbildung~\ref{fig:pic-comport}~-- der richtige COM-Port eingestellt werden. Über \enquote{Einstellungen $\rightarrow$ Connect} wird die serielle Verbindung aufgebaut und in der untersten Leiste anzeigt, ob der Verbindungsaufbau erfolgreich war.

			Zudem sollte im Reiter \enquote{Allgemein} die globale Verzögerung erfahrungsgemäß, wie Abbildung~\ref{fig:pic-delay} zeigt, auf etwa 0,07\,s eingestellt werden. Dies ist die Zeit, die aufgrund von Datenübertragungen und Rechenvorgängen zwischen dem Beginn des Sendens des Befehls vom PC zum Transmitter und dem Zünden des Kanals an der Zündbox vergeht.

			Als minimale Zeitdauer zwischen zwei Zündungen sollte \SI{100}{\milli\second} nicht unterschritten werden, das Scharfschalten vor Beginn der Show ist ebenso nicht zu vergessen wie das Scharfschalten des Transmitters und sämtlicher Zündboxen!

			\textbf{Anmerkung: Eine serielle Verbindung zu einem Device kann immer nur durch einen einzigen Client (\texttt{Putty\-tel}, \texttt{GUI}, \texttt{\pic}, \texttt{Firware-Updater}) bestehen. Man muss also immer die bestehende Verbindung trennen, bevor man mit einem anderen Programm eine neue aufbauen kann.}

			\begin{figure}
				\begin{subfigure}[t]{\textwidth}
					\centering
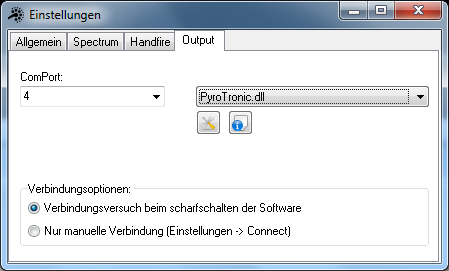
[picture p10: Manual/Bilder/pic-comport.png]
					
					\caption{Einstellung des COM-Ports in {\pic}}
					\label{fig:pic-comport}
				\end{subfigure}
				\\[50pt]
				\begin{subfigure}[t]{\textwidth}
					\centering
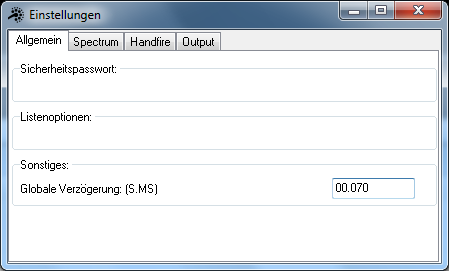
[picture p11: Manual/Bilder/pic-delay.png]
					
					\caption{Einstellung des Global Delay in \pic}
					\label{fig:pic-delay}
				\end{subfigure}
				\caption{Einstellungen in {\pic}}
			\end{figure}

	\chapter{Kommunikation zwischen PC und Devices}
		\label{ch:kommunikationpc}

		In diesem Abschnitt wird die Systemüberwachung bzw. -konfiguration über die serielle Schnittstelle mittels \texttt{Puttytel} oder die {\anlage}-GUI behandelt.

		Auf die Kommunikation zwischen {\pic} und der Transmitterbox wird an dieser Stelle nicht detailliert eingegangen, da hier~-- wenn alle Einstellungen wie in Abschnitt~\ref{sec:piceinrichtung} erläutert getroffen wurden~-- alles quasi-automatisch und ohne Zutun des Benutzers stattfindet. Es muss dafür aber unbedingt sichergestellt sein, dass das von {\pic} angesprochene Device scharfgeschaltet sein muss. Dies geschieht bei Zündboxen via Schlüsselschalter, bei Transmittern über den Terminalbefehl \enquote{arm}.

		Im Abschnitt \ref{ch:firmwareupdate} ab Seite \pageref{ch:firmwareupdate} wird das Aktualisieren der Firmware mittels Firmware-Updater erklärt.

		\section{Puttytel}

			\subsection{Befehlsübersicht}

				Hat man mittels \texttt{Puttytel} eine Verbindung zwischen einem Device und dem PC aufbauen können, sieht man vor sich zunächst nur einen schwarzen Bildschirm. Um nun mit dem Device kommunizieren zu können, existieren einige Befehle gemäß Tabelle~\ref{tab:commands}.

				\begin{table}[bt]
					\begin{center}
						\begin{xltabular}
							{.9\textwidth}{lX}
							\hline\hline
							\textbf{Befehl}                       & \textbf{Wirkung}                                                                                                                                                                                                                   \\ \hline
							arm                                   & Schaltet den Transmitter scharf, um Zündbefehle senden zu können                                                                                                                                                                   \\
							disarm                                & Schaltet den Transmitter unscharf, Zündbefehle werden nicht mehr gesendet                                                                                                                                                          \\ \hline
							\hyperref[subsec:localconf]{conf}     & Startet das Konfigurationsprogramm zur lokalen Zuweisung von Unique- und Slave-ID                                                                                                                                                  \\
							\hyperref[subsec:remoteconf]{remote}  & Startet das Konfigurationsprogramm zur ferngesteuerten Zuweisung von Unique- und Slave-ID                                                                                                                                          \\
							\hyperref[sec:list]{list}             & Zeigt die Systemübersicht (Zuweisung Unique- und Slave-ID, Batteriespannung jeder Box, Scharfschaltungsstatus Temperatur, RSSI, Anzahl Boxen je Slave-ID)                                                                          \\ \hline
							\hyperref[sec:manuellessenden]{send}  & Startet das Menü zur manuellen Eingabe einer Anweisung ans Funkmodul (Zündbefehl, Identifizierungsaufforderung oder Temperaturmessung)                                                                                             \\
							\hyperref[sec:manuellessenden]{fire}  & Führt zu einer Eingabemaske, in die Slave-ID und Kanal für die Zündung einzugeben sind                                                                                                                                             \\
							\hyperref[sec:manuellessenden]{ident} & Sendet eine Identifizierungsaufforderung an alle anderen Devices                                                                                                                                                                   \\
							\hyperref[sec:manuellessenden]{temp}  & Gibt über die serielle Schnittstelle die Temperatur aus und fordert alle anderen Devices ebenfalls zur Temperaturmessung auf. Zum Auslesen der neu gemessenen Temperaturen muss dann eine Identifizierungsanfrage geschickt werden \\ \hline
							\hyperref[sec:rfmzugriff]{rfm}        & Erlaubt unmittelbaren Zugriff auf das Funkmodul durch Eingabe einer 16-Bit-Hexadezimalzahl, um Registerwerte auszulesen oder neu zu setzen                                                                                         \\
							\hyperref[sec:encryption]{aeskey}     & Schlüssel für die Funkübertragung auslesen und neu setzen                                                                                                                                                                          \\ \hline
							\hyperref[sec:igniter]{igniter}       & Verwendeten Anzündertyp und somit Öffnungszeit der Zündkanäle setzen                                                                                                                                                               \\ \hline
							orders                                & Gibt letztes gesendetes und empfangenes Pattern auf LCD aus                                                                                                                                                                        \\ \hline
							cls                                   & Löscht den Terminal-Bildschirm                                                                                                                                                                                                     \\
							kill                                  & Löst einen Neustart des Device aus                                                                                                                                                                                                 \\ \hline\hline
						\end{xltabular}
						\caption{Kommandos zur Konfiguration über die serielle Schnittstelle}
						\label{tab:commands}
					\end{center}
				\end{table}

				Diese können, sofern \texttt{Puttytel} die aktive Anwendung ist, direkt über die PC-Tastatur eingegeben werden und sollten zur unmittelbaren Ausführung mit Druck auf die Taste \emph{ENTER} abgeschlossen werden. Sobald das erste Zeichen eingegeben wurde, leuchtet die gelbe Status-LED am Device. Unbekannte Befehle werden ignoriert, sämtliche Buchstaben als Kleinbuchstaben interpretiert. Korrekturen sind unter Verwendung der \emph{BACKSPACE}-Taste möglich.

				Aufgrund der eingebauten Timeout-Funktion, welche ein Hängenbleiben des Programms während einer Show verhindern soll, bricht die Firmware die Eingabe ab, wenn zwischen der Eingabe der einzelnen Buchstaben mehr als $\SI{3}{\second}$ vergehen. Lässt man diese Zeit verstreichen, wird automatisch ein Drücken der \emph{ENTER}-Taste übermittelt, die Befehlseingabe also abgeschlossen und das Device ist unmittelbar bereit, einen neuen Befehl aufzunehmen. Wird also nach Eingabe eines gültigen Befehls die \emph{ENTER}-Taste nicht gedrückt, wird der Befehl durch den Timeout dennoch ausgelöst. Möchte man dies vermeiden, sollte man den Befehl vor Ausführung durch Eingabe weiterer Zeichen ungültig machen oder durch Entfernen aller Zeichen mittels \emph{BACKSPACE} löschen.

				Von den in Tabelle~\ref{tab:commands} aufgeführten Befehlen funktioniert lediglich \enquote{orders} nicht bei allen Devices, sondern setzt voraus, dass das angeschlossene Device ein Transmitter ist.

			\subsection{Konfiguration}
				\label{sec:config}

				\subsubsection{Lokal}
					\label{subsec:localconf}

					Mit \enquote{conf} gelangt man ins Konfigurationsmenü für die lokale Konfiguration der IDs, dessen Ablauf beispielhaft in Abbildung~\ref{fig:conf} gezeigt ist. Hier sind die beiden wichtigsten Parameter jeder Zündbox, die Unique-ID und die Slave-ID, aufgeführt, die der Benutzer nach eigenen Bedürfnissen vergeben kann.

					Die \textbf{Unique-ID} dient der Identifikation jeder einzelnen Zündbox im Funksystem. Jeder verwendeten Zündbox muss daher, um die Funktion von {\anlage} gewährleisten zu können, eine andere Unique-ID im Bereich von 01-30 (zweistellige Eingabe!) eineindeutig zugeteilt werden, d.\,h. jede Box hat eine unterschiedliche Unique-ID bzw. jede Unique-ID gehört zu genau einer Zündbox.

					Die \textbf{Slave-ID} entscheidet, auf welche Zündbefehle eine Zündbox reagiert. Sollen also zwei oder mehr Boxen stets zur selben Zeit denselben Kanal zünden, kann ihnen einfach die gleiche Slave-ID zugewiesen werden.

					Die Null als Unique- und Slave-ID identifiziert ein Device als Transmitterbox. Die Software für Transmitter und die ersten beiden Zündboxgenerationen erkennt dabei automatisch, ob es sich beim angeschlossenen Device um einen Transmitter oder eine Zündbox handelt\footnote{Wie diese automatische Erkennung funktioniert, ist im Abschnitt \ref{ch:pinbelegung} ab Seite \pageref{ch:pinbelegung} beschrieben} und weist Transmittern unmittelbar beim Hochfahren \enquote{0} als Unique- und Slave-ID zu. Ein vom Aufbau her als Zündbox ausgeführtes Device muss immer von Null verschiedene IDs besitzen.

					Die Zuweisung von Unique- und Slave-ID vom Startbildschirm des Konfigurationsprogramms aus geschieht, indem man den Anweisungen auf dem Bildschirm folgt. Die Eingabe von \enquote{I} bzw. \enquote{i} (Groß- oder Kleinschreibung spielt keine Rolle) erlaubt eine Änderung von Unique- und Slave-ID einer Zündbox. Die neue Unique- bzw. Slave-ID muss stets zweistellig ohne Bestätigung durch \emph{ENTER} oder eine andere Taste eingegeben werden. Beide IDs können im Bereich von 01-30 liegen.

					\begin{figure}
						\centering
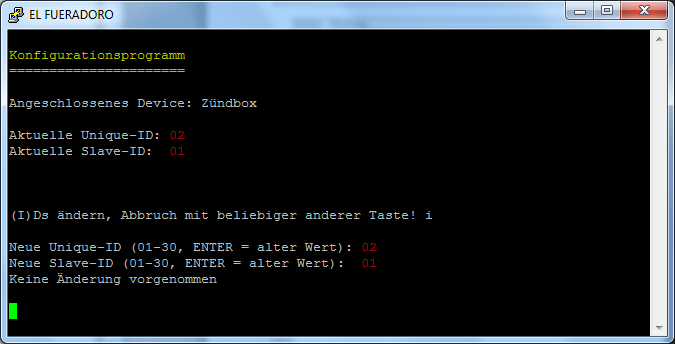
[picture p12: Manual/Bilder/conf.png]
						
						\caption{Ablauf des Konfigurationsprogramms bei Verbindung mit einer Zündbox}
						\label{fig:conf}
					\end{figure}

					Möchte man beispielsweise die Unique-ID 5 und die Slave-ID 12 zuweisen, muss man nach Anzeige des Startbildschirms zunächst \enquote{i} und anschließend \enquote{05} und \enquote{12} eingeben. Will man eine der beiden IDs beibehalten und nur die andere ändern, kann die Änderung durch Drücken von \emph{ENTER} übersprungen werden. Die zugewiesenen IDs werden an drei Stellen im internen Speicher mit Prüfsummen hinterlegt und bleiben sowohl nach dem Ausschalten als auch nach einem Firmwareupdate erhalten. Eine Änderung mindestens einer der IDs führt zu einem sofortigen Neustart der Zündbox.

					Unabhängig davon, dass eine Zündbox nicht als Transmitter konfiguriert werden, also nicht Unique- und Slave-ID  besitzen kann, kann sie theoretisch trotzdem zur Steuerung und Koordinierung eines Netzes und einer Show eingesetzt werden, indem man sie über die serielle Schnittstelle mit dem PC verbindet. Bis auf die Darstellung am LCD erfüllt sie dieselben Aufgaben wie ein Transmitter und kann auch parallel noch als Zündbox fungieren. Auf entsprechenden Sicherheitsabstand zu Lebewesen und sensibler Technik ist dabei selbstverständlich zu achten!

				\subsubsection{Ferngesteuert}
					\label{subsec:remoteconf}

					\begin{figure}
						\centering
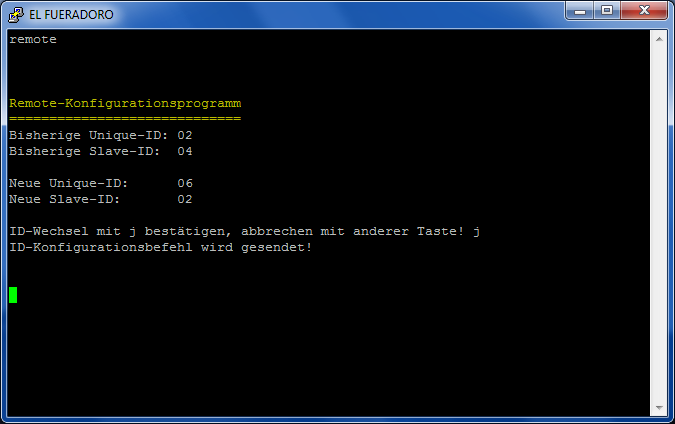
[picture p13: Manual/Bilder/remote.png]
						
						\caption{Beispiel einer ferngesteuerten ID-Zuweisung}
						\label{fig:remote}
					\end{figure}

					Über den Befehl \enquote{remote} gelangt man ins Konfigurationsprogramm zur ferngesteuerten Vergabe von Unique- und Slave-ID. Der Programmablauf ist beispielhaft in Abbildung~\ref{fig:remote} gezeigt: Die Eingabe der alten und neuen IDs erfolgt analog zur Eingabe bei lokaler Konfiguration, am Ende muss die Änderung noch bestätigt werden. Werden als alte Unique- und Slave-ID die Daten der verbundenen Box eingegeben, so werden deren Kennzahlen wie bei einer lokalen Konfiguration geändert und kein weiterer Befehl gesendet.

					Durch \enquote{remote} und die Eingabe von Unique- und Slave-ID einer nicht per Kabel verbundenen Box ist es möglich, die IDs einer eingeschalteten Zündbox per Funk zu ändern. Voraussetzung ist dabei, dass die angesprochene Zündbox nicht scharf geschaltet ist.

					Der Anwender hat selbst darauf zu achten, durch ein ferngesteuertes Update nicht einem Device eine bereits vergebene Unique-ID zuzuweisen! Falls dies dennoch geschieht, ist das weitere Vorgehen davon abhängig, ob die Devices auch die gleiche Slave-ID besitzen oder nicht. Sind die Slave-IDs nicht identisch, so kann durch einen weiteren \enquote{remote}-Befehl die Unique-ID-Zuweisung geändert werden. Bei identischen Slave-IDs funktioniert dies nicht, da stets alle Devices auf den Änderungsbefehl in gleicher Weise reagieren würden. Hier müssen daher alle Devices mit identischen IDs bis auf eines ausgeschaltet werden, dem man dann neue IDs zuweisen kann. Nun kann dann jeweils ein weiteres Device eingeschaltet und seine IDs neu gesetzt werden, bis wieder alle unterschiedliche Unique-IDs besitzen.

			\subsection{Systemübersicht}
				\label{sec:list}

				Mit \enquote{list} ist es möglich, sich die Systemübersicht entsprechend Abbildung~\ref{fig:list} anzeigen zu lassen. Es werden zwei Tabellen ausgegeben, wobei die obere nach Unique-ID geordnet anzeigt:
				\begin{enumerate}
					\item
					      Slave-ID, welcher der Unique-ID zugewiesen ist.
					\item
					      Spannung, welche die Batterie der Box mit der entsprechenden Unique-ID liefert.
					\item
					      Scharfschaltungsstatus der Box mit der jeweiligen Unique-ID: (j)a (=scharf) oder (n)ein (=nicht scharf).
					\item
					      Temperatur im Inneren der Box, sofern die Box über einen eingebauten Temperatursensor verfügt, ansonsten wird \enquote{n.a.}~(not available) angezeigt.
					\item
					      Stärke des von der Box empfangenen Antwortsignals (RSSI = Received Signal Strength Indicator) in dBm. Je größer der Wert ist~-- bei negativen Werten also umso näher er bei 0 liegt, umso besser und umso weniger störanfällig ist die Verbindung zwischen den Devices. Die theoretische Empfangsgrenze liegt bei etwa $\SI{-96}{\dBm}$.
				\end{enumerate}

				Die untere Tabelle listet auf, wie viele Boxen mit der entsprechenden Slave-ID derzeit aktiv sind.

				Zwischen den beiden Tabellen wird die Anzahl der fehlerhaften IDs aufgelistet. Dies kann entweder auf doppelte Zuweisung von Unique-IDs oder Fehler beim Auslesen der IDs (fehlerhafte Prüfsummen) zurückzuführen sein. Für normalen Betrieb sollte dieser Wert stets 0 betragen.

				\begin{figure}
					\centering
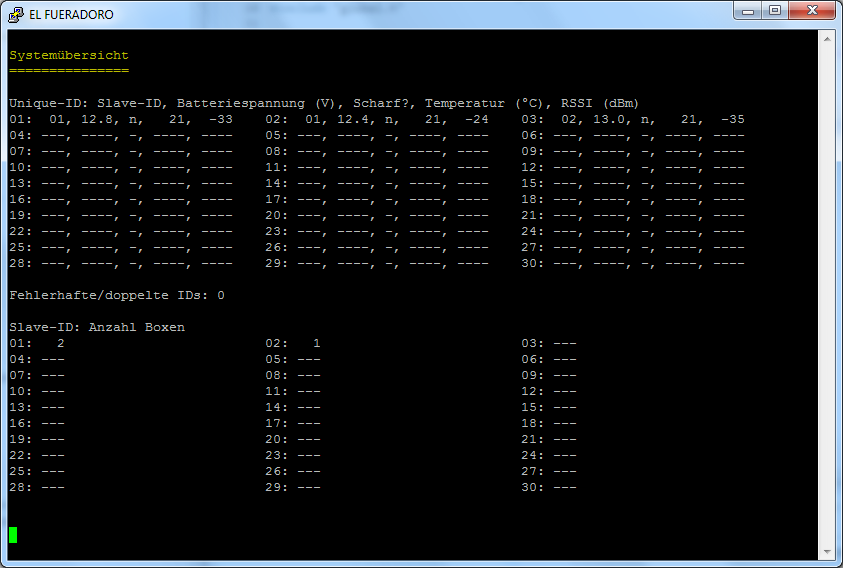
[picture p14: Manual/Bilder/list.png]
					
					\caption{Systemübersicht}
					\label{fig:list}
				\end{figure}

				Der dargestellte Zustand entspricht den empfangenen Parametern nach der letzten Identifikationsaufforderung bzw. nach dem Einschalten der Zündbox. Für eine möglichst aktuelle Liste sollte also vor dem Aufruf von \enquote{list}, wie im Abschnitt~\ref{sec:manuellessenden} beschrieben, eine Identifikationsaufforderung gesendet werden.

			\subsection{Manuelles Senden}
				\label{sec:manuellessenden}

				Zu Testzwecken oder um die Systemübersicht zu aktualisieren, können mittels \enquote{send} Zündbefehle und die Aufforderung zur Identifizierung oder Temperaturmessung manuell versendet werden. Nach Eingabe von \enquote{send} muss dies mit \enquote{f} (=fire), \enquote{i} (=identify) oder \enquote{t} (=temperature) ausgewählt werden. Wählt man \enquote{i} oder \enquote{t} ist keine weitere Eingabe nötig, bei \enquote{f} müssen anschließend noch Slave-ID und Kanal jeweils zweistellig eingegeben werden. Statt \enquote{send} und den entsprechenden Buchstaben anzugeben, können auch die direkten Befehle \mbox{\enquote{fire}}, \mbox{\enquote{ident}} und \mbox{\enquote{temp}} verwendet werden.

				Jede andere Angabe als \enquote{f}, \enquote{i} oder \enquote{t} beendet den Modus ohne irgendetwas zu senden. Denselben Effekt hat die Eingabe einer Slave-ID oder Kanalnummer außerhalb der jeweils zulässigen Zahlenbereiche.

			\subsection{Funkmodul-Zugriff}
				\label{sec:rfmzugriff}

				Die zwingend für den Betrieb von {\anlage} notwendigen Zugriffe auf das Funkmodul werden von der Software automatisch getätigt, so dass diese Funktion in der Regel nicht gebraucht wird. Dennoch ist es möglich das verwendete Funkmodul \texttt{RFM69CW} bzw. \texttt{RFM69HCW\footnote{Link zum Datenblatt auf Seite~\pageref{sec:datasheets}}} unmittelbar über das Terminalprogramm anzusprechen, um Werte aus den Registern zu lesen oder die Register für die aktuelle Sitzung neu zu beschreiben. Beim nächsten Neustart des Devices werden stets die Standardeinstellungen wiederhergestellt.

				Nach Eingabe von \enquote{rfm} und Bestätigung mit \emph{ENTER} erscheint eine Aufforderung zur Befehls\-eingabe. Diese hat im Hexadezimalformat als 16-Bit-Wert zu erfolgen, d.\,h. vierstellig mit den zulässigen Zeichen 0-9 und A-F bzw. a-f. Jedes eingegebene Zeichen symbolisiert dabei vier Bits, die Umrechnung ist in Tabelle~\ref{tab:zahlensysteme} gezeigt.

				\begin{table}
					\begin{center}
						\begin{xltabular}
							{.8\textwidth}{X*{16}c}
							\hline\hline
							Hexadezimal & 0    & 1    & 2    & 3    & 4    & 5    & 6    & 7    \\
							Dezimal     & 0    & 1    & 2    & 3    & 4    & 5    & 6    & 7    \\
							Binär       & 0000 & 0001 & 0010 & 0011 & 0100 & 0101 & 0110 & 0111 \\
							\\
							Hexadezimal & 8    & 9    & A    & B    & C    & D    & E    & F    \\
							Dezimal     & 8    & 9    & 10   & 11   & 12   & 13   & 14   & 15   \\
							Binär       & 1000 & 1001 & 1010 & 1011 & 1100 & 1101 & 1110 & 1111 \\ \hline\hline
						\end{xltabular}
					\end{center}
					\caption{Umrechnung Hexadezimal-, Dezimal- und Binärwerte}
					\label{tab:zahlensysteme}
				\end{table}

				Die Bedeutung der Eingabe für das Funkmodul ist in Tabelle~\ref{tab:rfmcommand} illustriert. Hierbei sollte auch klar werden, wie sich die Werte für die Zeichen 1-4 zusammensetzen. Ist ein Bit gesetzt, muss die entsprechende Zahl (8, 4, 2, 1) zum Zeichenwert addiert werden, so dass sich bei vier gesetzten Bits als Maximalwert 15 ergibt, ist nur das oberste Bit gesetzt, lautet der Wert 8, ist nur das unterste gesetzt 1, sind die beiden mittleren Bits gesetzt 6, usw.

				Es ist zu erkennen, dass das erste einzugebende Zeichen sowohl das Schreiben/Lesen-Bit enthält als auch die obersten drei Bit der Registeradresse. Die acht Datenbits sind lediglich für einen Schreibbefehl relevant, bei einem Lesezugriff kann als drittes und viertes Zeichen ohne Konsequenzen ein beliebiger Hexadezimalwert im Bereich von 0x00 bis 0xFF übertragen werden.

				\begin{table}
					\begin{center}
						\begin{xltabular}
							{.95\textwidth}{Xc|*{7}c|*{8}c}
							\hline\hline
							Bit     & w/$\overline{\mbox{r}}$ & r6 & r5 & r4                      & r3 & r2 & r1 & r0                      & d7 & d6 & d5 & d4                      & d3 & d2 & d1 & d0                    \\
							Wert    & 8                       & 4  & 2  & \multicolumn{1}{c||}{1} & 8  & 4  & 2  & \multicolumn{1}{c||}{1} & 8  & 4  & 2  & \multicolumn{1}{c||}{1} & 8  & 4  & 2  & \multicolumn{1}{c}{1} \\
							Zeichen & \multicolumn{4}{c||}{Zeichen 1}                             & \multicolumn{4}{c||}{Zeichen 2}        & \multicolumn{4}{c||}{Zeichen 3}        & \multicolumn{4}{c}{Zeichen 4}        \\ ~ \\ \hline
						\end{xltabular}
						\begin{xltabular}
							{.95\textwidth}{p{2cm}cXp{2cm}}
							~                                                                                                      \\
							 & w/$\overline{\mbox{r}}$ & Schreib- oder Lesezugriff (0 = lesen, 1 = schreiben)                      \\
							 & r6 {\dots} r0           & Registeradresse                                                           \\
							 & d7 {\dots} d0           & Zu schreibender Registerwert (beliebig falls w/$\overline{\mbox{r}} = 0$) \\ \hline\hline
						\end{xltabular}
					\end{center}
					\caption{Struktur des \texttt{RFM69}-Befehls}
					\label{tab:rfmcommand}
				\end{table}

				\subsubsection{Auslesen der eingestellten Sendeleistung}
					\label{subsec:readpower}

					Zur Veranschaulichung soll hier die Abfrage der aktuell eingestellten Sendeleistung und eine anschließende Änderung derselben mit dem Funkmodul \texttt{RFM69CW} simuliert werden: Aus dem Datenblatt, dem die Bedeutungen aller Registeradressen und ihrer acht Registerbits zu entnehmen sind, kann die Registeradresse 0x11 als diejenige identifiziert werden, in der die Informationen zur Sendeleistung hinterlegt sind. Um nun den aktuellen Wert auszulesen, gibt man~-- wie in Abbildung~\ref{fig:rfmread} gezeigt~-- im Terminalprogramm \enquote{rfm} gefolgt von \emph{ENTER} ein und anschließend die Zeichenfolge \enquote{11FF}, wobei die beiden hinteren Stellen wie erwähnt keine Rolle spielen.

					\begin{figure}
						\centering
						
						\caption{Auslesen der gesetzten Sendeleistung}
						\label{fig:rfmread}
					\end{figure}

					Das Modul antwortet nun mit einem 8-Bit-Wert, z.\,B. mit dem Wert 0x9A, welcher dem Binärwert 10011010 entspricht, dessen Bedeutung dem Datenblatt entnommen werden kann: Das oberste Bit signalisiert, dass die Verstärkerstufe PA0 aktiv ist, die beiden folgenden Bits sind 0, da PA1 und PA2 in der Variante \texttt{RFM69CW} nicht genutzt werden können. Die unteren fünf Bits schließlich stehen für die eingestellte Sendeleistung, wobei man vom aus den fünf Bits berechneten Wert noch 18 abziehen muss, um die Sendeleistung in dBm zu erhalten. Gesetzt sind die Bits 4, 3 und 1, was dem Wert 26 ($= 2^4 + 2^3 + 2^1$) entspricht, daraus resultiert eine eingestellte Sendeleistung von $\SI{8}{\dBm}$.

				\subsubsection{Setzen der Sendeleistung}

					Will man die Sendeleistung nun auf $\SI{6}{\dBm}$ anpassen, muss also ein Wert von 24 für die Aus\-gangs\-lei\-stungs-Bits gesetzt werden, dazu natürlich auch das oberste Bit für den PA0. Als Wert für die Registerbits ergibt sich damit $2^7 + 2^4 + 2^3 = 0x98$. Die Registeradresse bleibt gleich, jedoch muss dem Modul mitgeteilt werden, dass es sich um einen Schreibzugriff handelt, weshalb die erste Stelle um den Wert 8 erhöht werden muss. Um nun den neuen Wert von $\SI{6}{\dBm}$ einzuschreiben, gibt man im Terminalprogramm~-- wie in Abbildung~\ref{fig:rfmwrite} gezeigt~-- \enquote{rfm} gefolgt von \emph{ENTER} ein und anschließend die Zeichenfolge \enquote{9198}.

					\begin{figure}
						\centering
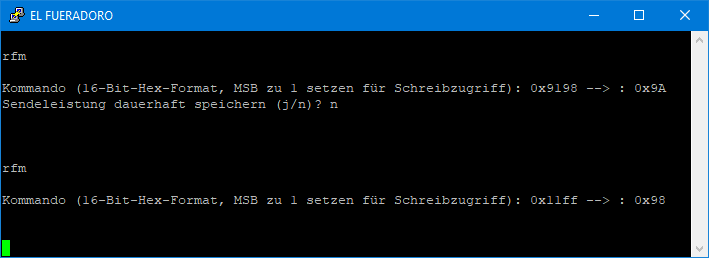
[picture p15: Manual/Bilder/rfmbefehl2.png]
						
						\caption{Setzen der Sendeleistung mit anschließendem Auslesen}
						\label{fig:rfmwrite}
					\end{figure}

					Als Antwort erhält man vom Modul den Registerwert von VOR dem Schreibzugriff, im Beispiel also den Wert 0x9A. Ein nochmaliges Auslesen des Registers, wie im Abschnitt~\ref{subsec:readpower} beschrieben, sollte nun den eben eingeschriebenen Wert 0x98 zurückgeben. Beim nächsten Neustart des Device wird der Standardwert wiederhergestellt.

			\subsection{AES-Verschlüsselung}
				\label{sec:encryption}

				Zum sicheren Betrieb von {\anlage} werden die drahtlos zu übermittelnden Daten zwischen Sender und Empfänger verschlüsselt. Hierfür muss in den am Funkverkehr beteiligten Modulen ein Schlüssel mit einer Länge von 16~Bytes (128~Bit) hinterlegt werden, der für die Ver- und Entschlüsselung der Datenpakete genutzt wird. Dieser Schlüssel ist im internen Speicher des Mikrocontrollers hinterlegt und bleibt auch beim Trennen der Stromversorgung erhalten. Selbstredend muss in allen Controllern derselbe Schlüssel hinterlegt sein, damit diese miteinander kommunizieren können.

				Nach Eingabe von \enquote{aeskey} im Terminalfenster kann der aktuell eingestellte Schlüssel eingesehen werden. Hierzu wird der Schlüssel einmal aus dem Speicher des Controllers ausgelesen und einmal aus den Einstellungen des Funkmoduls. Diese beiden Zeilen sollten identische Werte anzeigen.

				Jede Taste außer \enquote{s} bringt den Benutzer anschließend ins Hauptmenü zurück.

				Möchte man den Schlüssel ändern, muss die Taste \enquote{s} gedrückt und anschließend der komplette neue Schlüssel im hexadezimalen Zahlenformat eingegeben werden, wie beim Funkmodul-Zugriff sind also nur die Zeichen 0-9 und A-F bzw. a-f zulässig. Wurde ein gültiger Schlüssel eingegeben, erfolgt noch eine finale Nachfrage, ob dieser neue Schlüssel gespeichert werden soll, welche man mit \enquote{j} oder \enquote{n} beantworten kann. Abbildung~\ref{fig:aeskey} zeigt das Prozedere im Terminalfenster.

				\begin{figure}[!h]
					\centering
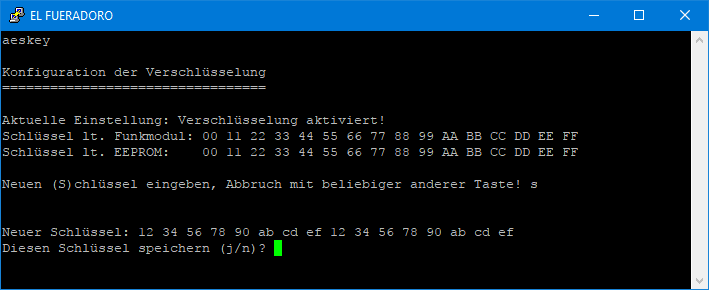
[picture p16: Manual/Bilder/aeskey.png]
					
					\caption{Auslesen und Neusetzen des AES-Schlüssels}
					\label{fig:aeskey}
				\end{figure}

			\subsection{Anzündertyp}
				\label{sec:igniter}

				Um {\anlage} auch mit anderen Anzündertypen als den Standard E-Anzündern wie Talon-Anzündern nutzen zu können oder einen Zündkanal als Trigger für Geräte wie Flamer nutzen zu können, kann die Zünddauer angepasst werden. Es stehen dabei die Optionen:
				\begin{itemize}
					\item E-Anzünder: \SI{20}{\milli\second}
					\item Flamer: \SI{350}{\milli\second}
					\item Talon: \SI{2450}{\milli\second}
				\end{itemize}
				zur Auswahl.

				Nach Eingabe von \enquote{igniter} im Terminalfenster kann die aktuelle Einstellung eingesehen werden, durch Eingabe eines Buchstabens, der den entsprechenden Optionen zugeordnet ist, kann diese Einstellung geändert werden. Eine nicht zugeordnete Taste beendet das Einstellungsmenü ohne Änderung. Die Einstellung bezieht sich dabei immer auf alle Kanäle der Zündbox und bleibt auch nach Neustart und Firmware-Update erhalten.
				\clearpage

		\section{GUI}

			\begin{figure}[!h]%
				\centering
				\begin{subfigure}[t]{0.45\textwidth}
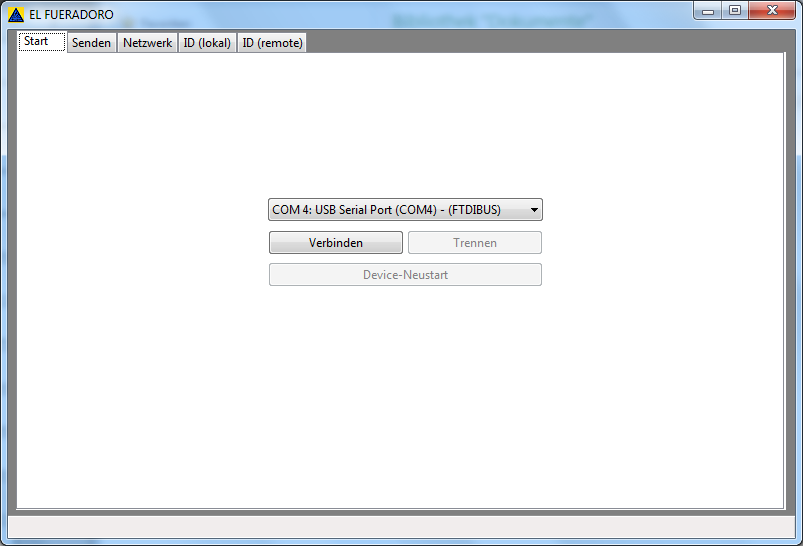
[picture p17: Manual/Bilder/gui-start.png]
					
					\caption{Keine serielle Verbindung}
					\label{fig:gui-unconnected}
				\end{subfigure}
				%
				\begin{subfigure}[t]{0.45\textwidth}
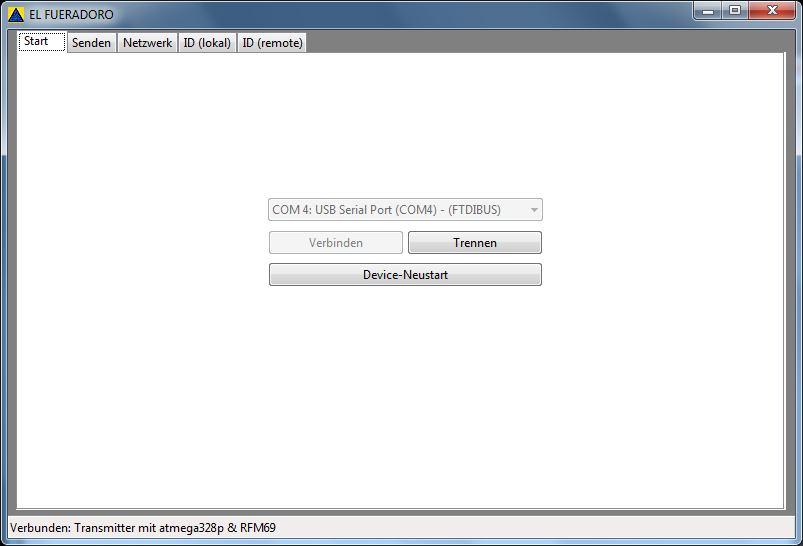
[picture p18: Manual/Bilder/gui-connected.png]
					
					\caption{Verbindung erfolgreich hergestellt}
					\label{fig:gui-connected}
				\end{subfigure}
				%
				\caption{Startbildschirm der GUI}
				\label{fig:gui-start}
			\end{figure}
			%

			Die GUI stellt eine graphische Oberfläche zur Implementierung der \texttt{Puttytel}-Funktionen dar, indem über die serielle Schnittstelle ein- und ausgehende Daten geparst und an den entsprechenden Stellen innerhalb der Oberfläche dargestellt werden. Die Software ist in die fünf Reiter \enquote{Start}, \enquote{Senden}, \enquote{Netzwerk}, \enquote{ID~(lokal)} und \enquote{ID~(remote)} unterteilt, in denen die entsprechenden Funktionen ausgeführt werden können.

			Nach dem Start der Software sind alle Schaltflächen in allen Reitern mit Ausnahme der Auswahl der zur Verfügung stehenden COM-Ports und der Schaltfläche \enquote{Verbinden} im Reiter \enquote{Start} ausgegraut und deaktiviert, was in Abbildung~\ref{fig:gui-unconnected} dargestellt ist. Nach Auswahl des entsprechenden Ports und Klick auf \enquote{Verbinden}, werden diese beiden Schaltflächen ausgegraut und deaktiviert. Im Gegenzug erscheint in der Fußleiste der Devicetyp mit verwendetem Controller und Funkmodul und die Schaltflächen \enquote{Trennen} sowie \enquote{Device-Neustart} werden im aktuellen Reiter aktiv (Abbildung~\ref{fig:gui-connected}).%
			%
			\begin{figure}[!b]
				\centering
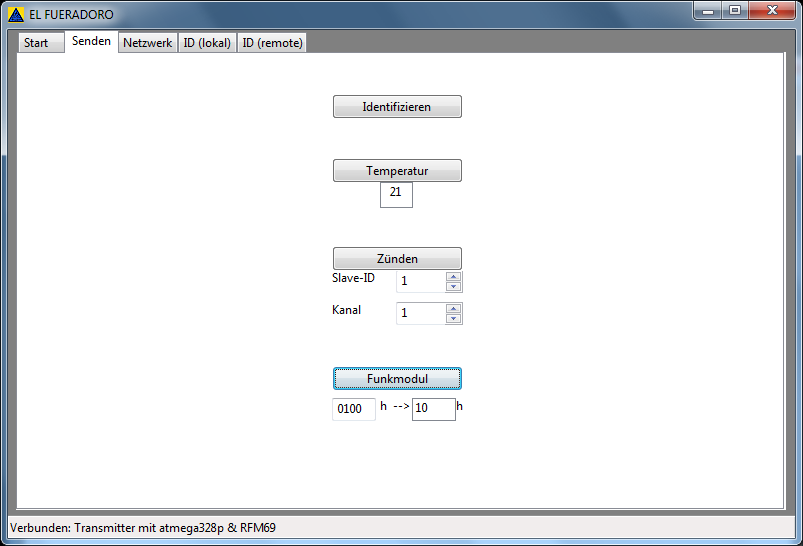
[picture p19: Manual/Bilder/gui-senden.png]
				
				\caption{Sendebildschirm der GUI}
				\label{fig:gui-senden}
			\end{figure}

			Nach Herstellung der Verbindung sind auch die sonstigen Schaltflächen aktiv, Abbildung~\ref{fig:gui-senden} zeigt den Reiter \enquote{Senden} im aktiven Zustand. Hier kann per Klick eine Identifizierungsaufforderung verschickt, eine Temperaturmessung getriggert, ein Zündvorgang ausgelöst oder ein Befehl ans Funkmodul geschickt werden. Bei \enquote{Zünden} und \enquote{Funkmodul} ist darauf zu achten, dass beim Klick auf die Schaltfläche unmittelbar die aktuell in den Eingabefeldern stehenden Werte übertragen werden, man diese also vor dem Klicken anpassen muss. Bei Temperaturanfrage und Funkmodulzugriff wird im entsprechenden Anzeigefeld die Antwort des angeschlossenen Devices~-- also die Temperatur in Grad Celsius oder die Antwort des Funkmoduls auf den aktuellen Registerzugriff als 8-bit-Hexadezimalwert~-- ausgegeben. Das permanente Ändern der Sendeleistung ist in der GUI noch nicht implementiert.

			Der Reiter \enquote{Netzwerk} (Abbildung~\ref{fig:gui-netzwerk}) dient einzig und allein der Darstellung der aktuell im System befindlichen Zündboxen mit ihren Parametern Unique-ID, Slave-ID, Batteriespannung, Scharf\-schaltungs-Status, Temperatur und gemessenem RSSI-Wert beim Empfang der Parameter.

			\begin{figure}[!t]
				\centering
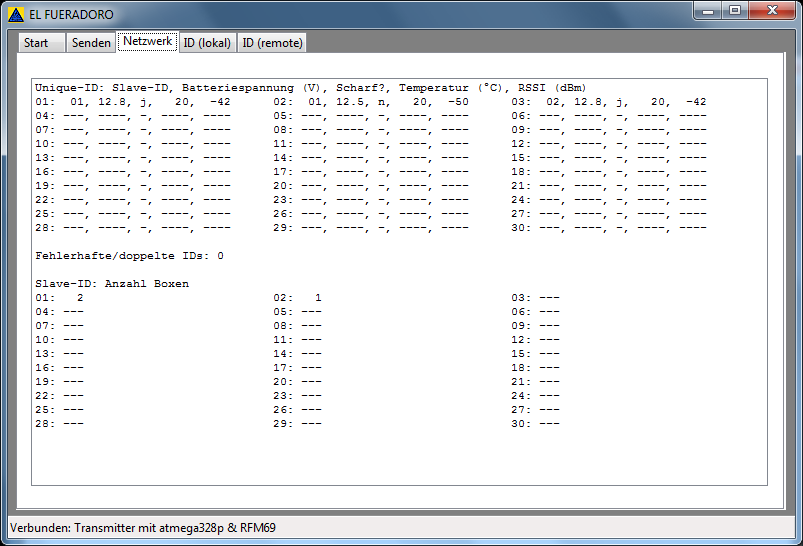
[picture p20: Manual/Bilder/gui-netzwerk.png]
				
				\caption{Netzwerkanzeige der GUI}
				\label{fig:gui-netzwerk}
			\end{figure}

			Die Ansicht des Reiters \enquote{ID~(lokal)} ist, wie Abbildung~\ref{fig:gui-local} zeigt, abhängig vom angeschlossenen Devicetyp. Bei Transmittern sind die Schaltflächen deaktiviert, da hier keine Änderungen an den IDs vorgenommen werden können (Abbildung~\ref{fig:gui-local-trans}). Bei Zündboxen werden bei Aufruf des Reiters die aktuellen IDs in die entsprechenden Felder kopiert, können verändert und die Änderungen dann durch Klick auf \enquote{Werte übernehmen} übernommen werden (Abbildung~\ref{fig:gui-local-ig}).

			\begin{figure}[!b]
				\centering
				\begin{subfigure}[t]{0.45\textwidth}
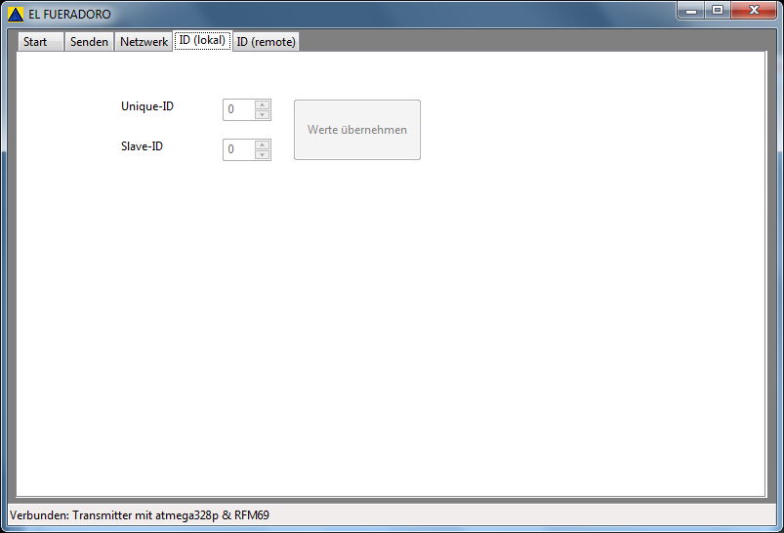
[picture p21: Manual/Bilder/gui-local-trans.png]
					
					\caption{Transmitter}
					\label{fig:gui-local-trans}
				\end{subfigure}
				%
				\begin{subfigure}[t]{0.45\textwidth}
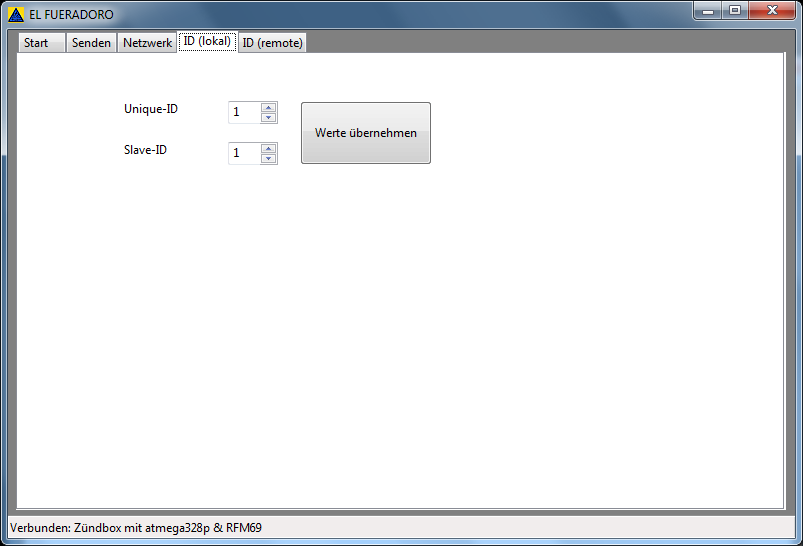
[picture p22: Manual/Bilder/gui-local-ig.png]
					
					\caption{Zündbox}
					\label{fig:gui-local-ig}
				\end{subfigure}
				\caption{Lokale ID-Konfiguration}
				\label{fig:gui-local}
			\end{figure}

			Im Reiter \enquote{ID~(remote)} können alte und neue ID-Kombination eingestellt werden. Durch Klick auf \enquote{Ausführen} wird der Befehl zur ID-Änderung gesendet.

			\begin{figure}[!t]
				\centering
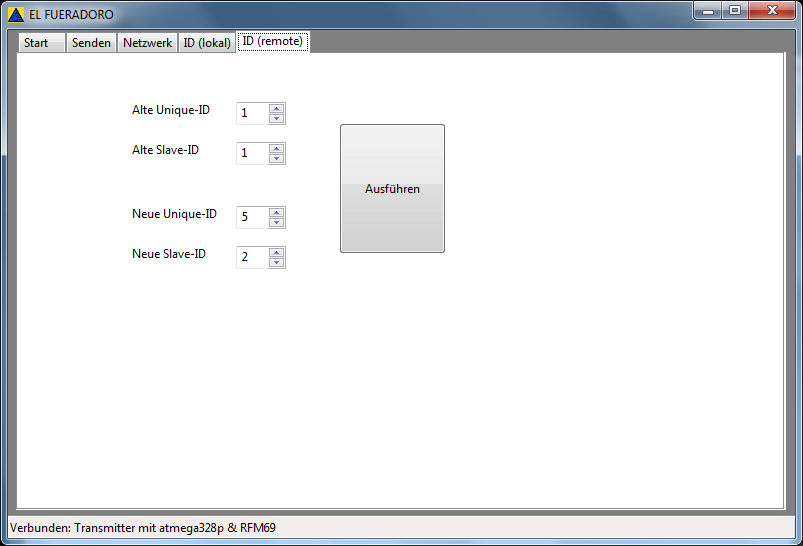
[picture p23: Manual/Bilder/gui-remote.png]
				
				\caption{Remote-ID-Einstellung}
				\label{fig:gui-remote}
			\end{figure}

		\section{Firmwareupdate}
			\label{ch:firmwareupdate}

			\textbf{WICHTIG: Aus Sicherheitsgründen darf kein Update durchgeführt werden, solange Anzünder mit dem Device verbunden sind, da sich die Devices im Falle eines Übertragungsfehlers völlig unvorhersehbar verhalten können.}

			\subsection{Herunterladen}

				Die aktuelle Firmware kann aus dem Git-Repository
				\begin{center}
					\url{https://github.com/fixxl/el-fueradoro}
				\end{center}
				mittels Git-Client oder direkt über den Link
				\begin{center}
					\url{https://github.com/fixxl/el-fueradoro/archive/master.zip}
				\end{center}
				heruntergeladen werden.

				Im Repository enthalten sind der komplette C-Quellcode, das AVR-Eclipse-Projekt, die kom\-pilierten iHex-Dateien für Firmware und Bootloader, die nötigen Software-Tools zur Übertragung zwischen PC und Mikrocontroller sowie die vorliegende Anleitung.

			\subsection{Aktualisierung}

					{\anlage} bietet die Möglichkeit, die Firmware via serielle Schnittstelle vom PC aus zu aktualisieren. Hierfür stehen das Kommandozeilentool \emph{fwupdate.exe} oder eine Windows-Oberfläche namens \texttt{UpdateLoader}, welche beide zunächst einen Reset auslösen, um den Bootloader des Devices zu aktivieren, und anschließend die im iHex-Format vorliegende Firmware überträgen.

				Es existieren für jede Kombination von Platinenversion (v1/v2, v3 mit 16 Kanälen und v3 mit 32 Kanälen sowie das Minimodul mit 4 Kanälen) und Funkmodul (RFM69CW und RFM69HCW) Firmwareversionen. Tabelle~\ref{tab:firmwareversions} gibt einen Überblick über die Versionen, welche sich im gleichen Ordner wie \emph{fwupdate.exe} und \emph{UpdateLoader.exe} befinden.

				\begin{table}
					\centering
					\begin{xltabular}
						{\textwidth}{lccC}
						\hline\hline
						Firmware                                     & Platine & Kanäle & Funkmodul (Sendeleistung)   \\ \hline
						Pyro\_atmega328p\_RFM69CW\_16ch.hex          & v1/v2   & 16     & RFM69CW   $(\SI{13}{\dBm})$ \\
						Pyro\_atmega328p\_RFM69HCW\_16ch.hex         & v1/v2   & 16     & RFM69HCW  $(\SI{20}{\dBm})$ \\
						Pyro\_v3\_atmega328p\_RFM69CW\_16ch.hex      & v3      & 16     & RFM69CW   $(\SI{13}{\dBm})$ \\
						Pyro\_v3\_atmega328p\_RFM69CW\_32ch.hex      & v3      & 32     & RFM69CW   $(\SI{13}{\dBm})$ \\
						Pyro\_v3\_atmega328p\_RFM69HCW\_16ch.hex     & v3      & 16     & RFM69HCW  $(\SI{20}{\dBm})$ \\
						Pyro\_v3\_atmega328p\_RFM69HCW\_32ch.hex     & v3      & 32     & RFM69HCW  $(\SI{20}{\dBm})$ \\
						Pyro\_Mini\_atmega328p\_RFM69CW\_4ch.hex     & Mini    & 4      & RFM69CW   $(\SI{13}{\dBm})$ \\
						Pyro\_Mini\_atmega328p\_RFM69HCW\_4ch.hex    & Mini    & 4      & RFM69HCW  $(\SI{20}{\dBm})$ \\
					\end{xltabular}
					\caption{Verfügbare Firmware-Versionen}
					\label{tab:firmwareversions}
				\end{table}

				\subsubsection{Kommandozeile}

					\emph{fwupdate.exe} muss über die Kommandozeile mit zwei Parametern gestartet werden, nämlich der Angabe der seriellen Schnittstelle und dem Namen der zu übertragenden Firmware-Datei. Um nun die neue Firmware zu übertragen, lautet das Kommando für ein Device am \emph{COM4} mit dem \emph{ATmega328P} (und dem Funkmodul \emph{RFM69CW}):

					\begin{center}
						\emph{fwupdate.exe /c4 /fm:Pyro\_atmega328p\_RFM69.hex}
					\end{center}

					oder für die Firmware mit höherer Sendeleistung

					\begin{center}
						\emph{fwupdate.exe /c4 /fm:Pyro\_atmega328p\_RFM69\_HP.hex}
					\end{center}

					Die Angabe der Dateiendung \emph{.hex} kann hierbei~-- ebenso wie das \emph{.exe} hinter \emph{fwupdate}~-- auch weggelassen werden, die Firmware-Datei muss jedoch zwingend auf \emph{.hex} enden.

					\emph{fwupdate.exe} ist, sofern bereits eine korrekt funktionierende Firmware auf dem Device vorhanden ist, in der Lage, automatisiert zu ermitteln, welche Firmwaredatei die benötigte ist, das Kommando für ein Update über \emph{COM4} lautet dann nur noch:

					\begin{center}
						\emph{fwupdate.exe /c4 /fa}
					\end{center}

					Der Updater führt nach Übertragung der Daten einen CRC-Check durch. Sollte dieser fehlschlagen, wurde die Firmware nicht korrekt übertragen. Dies kann zufällig passieren oder auf ein Hardwareproblem, welches in der Regel beim USB-RS232-Adapter liegt, zurückzuführen sein. Für den Fall eines CRC-Fehlers sollte die Firmware erneut übertragen werden. Bleibt das Update beim Punkt \enquote{COMx at 9600 baud:} stehen, sollte die Stromversorgung des Device kurz unterbrochen und wieder aktiviert werden. Das Kabel für die serielle Verbindung bleibt währenddessen mit Device und PC verbunden.

				\subsubsection{Windows-Oberfläche}

					Dank der Arbeit von Leo-Andres Hofmann\footnote{Seine Homepage findet sich unter: \url{https://luani.de}} existiert die in Abbildung~\ref{fig:updateloader} dargestellte Windows-Oberfläche zur einfachen Übertragung der Firmware via serielle Schnittstelle, der \texttt{UpdateLoader}. Hier kann man aus der Liste der verfügbaren COM-Ports den entsprechenden wählen sowie die zu übertragende Datei einstellen (hier auf korrekte Version achten!) und die Dateiübertragung per Klick auf \enquote{Update starten} durchführen.

					\begin{figure}[!h]
						\centering
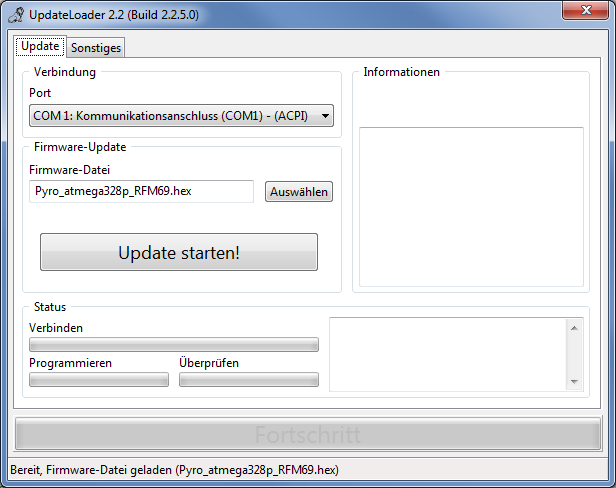
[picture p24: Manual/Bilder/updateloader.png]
						
						\caption{Benutzeroberfläche \texttt{UpdateLoader}}
						\label{fig:updateloader}
					\end{figure}

	\chapter{raspEasyFire}
		\label{ch:raspeasyfire}

		Als Alternative zur Kombination aus Laptop/PC und dem in den vorangegangenen Abschnitten beschriebenen Transmitter wurde in Zusammenarbeit mit einem Softwareentwickler ein Audio-Funksystem auf Basis des bekannten Einplatinencomputers \enquote{Raspberry Pi} entwickelt. Dieser übernimmt die Kontrolle der Show inklusive der Musikwiedergabe.

		Neben einem Raspberry Pi (unterstützt werden Stand {\mmyyyydate\today} Modelle bis 3B+) werden für den Aufbau eine speziell für die Verwendung mit {\anlage} entwickelte Aufsteckplatine sowie ein Touchdisplay, eine USB-Soundkarte, zwei Taster (FIRE und ON-OFF), welche interne oder externe LEDs besitzen können, ein Schlüsselschalter und zwei weitere LEDs für die Signalisierung von Senden (TX) und Empfangen (RX) benötigt. Eine Einkaufsliste findet sich in Tabelle~\ref{tab:raspibom} ab Seite \pageref{tab:raspibom}.
		
		Alternativ zur Verwendung einer USB-Soundkarte kann für die Soundwiedergabe auch ein Hifiberry\footnote{Nähere Infos unter \url{https://www.hifiberry.com/}} verwendet werden. Hierzu existiert eine in diesem Handbuch noch nicht näher behandelte Platinenversion für {\REF}, welche die von Hifiberry benötigten Anschlüsse am \enquote{Raspberry Pi} nicht nutzt. Ob es sich um die Hifiberry- oder die klassische Variante handelt, muss softwareseitig festgelegt werden, als Standard wird die klassische Variante angenommen.

		Ausgangspunkt für die Arbeiten mit {\REF} ist ein komplett aufgebautes System mit beschriebener SD-Karte, die notwendigen Schritte hierzu werden in den Abschnitten~\ref{sec:raspipcb}, \ref{subsec:raspicase} und \ref{ch:raspisd} dargelegt. Eine mögliche Außenansicht mit den notwendigen Funktionseinheiten ist in Abbildung~\ref{fig:raspEasyFireDescription} gezeigt.

		\begin{figure}
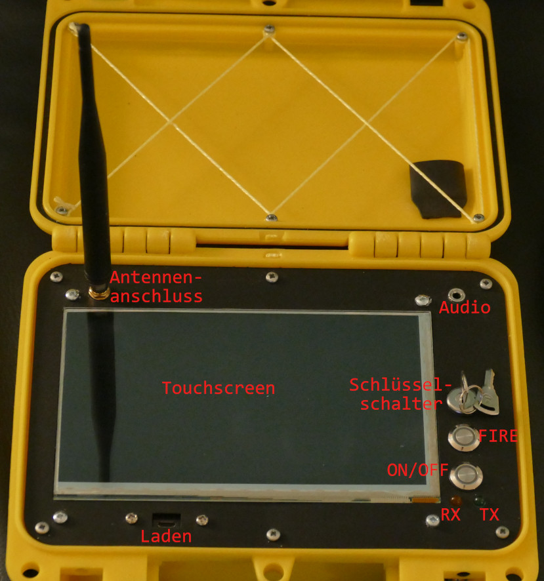
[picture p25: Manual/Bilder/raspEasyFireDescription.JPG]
			\centering
			\caption{Aufgebautes System \REF}
			\label{fig:raspEasyFireDescription}
		\end{figure}

		\section{Erster Start}
		\label{sec:reffirststart}

			Beim ersten Hochfahren passt sich das System an die tatsächlichen lokalen Gegebenheiten an, insbesondere wird die komplette Größe der verwendeten Speicherkarte nutzbar gemacht.
			
			Zusätzlich muss der Anwender mitteilen, welche Auflösung das von ihm verwendete Display besitzt: Der FIRE-Taster setzt die Auflösung auf 800x480 Pixel, der ON-OFF-Taster auf 1024x600 Pixel. Ebenso wird die Art des verbauten Funkmoduls abgefragt: Der FIRE-Taster setzt das RFM69HCW, der ON-OFF-Taster das RFM69CW.
			
			Die manuelle Eingabe von Auflösung und Funkmodul kann vermieden werden, indem im Hauptverzeichnis der SD-Karte eine Datei \enquote{sysinfo.txt} abgelegt wird, die für ein \enquote{klassisches} System mit HCW-Modul und großem Display im Band um \SI{868}{\mega\hertz} folgendermaßen aussehen sollte:
			
			\fbox{\parbox{.6\textwidth}{screen800: 0\\
					hcw: 1\\
					f433: 0\\
					hifi: 0}}

			Anschließend erfolgt ein automatischer Neustart des Systems, der im Auswahlbildschirm mündet, ob man das Programm starten (FIRE-Button) oder das System herunterfahren (ON-OFF-Button) möchte. Ein gleichzeitiges Drücken beider Taster beendet das Startup-Skript und bringt den Nutzer zur \enquote{Bash}, wie die Kommandozeile unter Linux genannt wird.

		\section{Konfiguration und Zugriff}

			Die meisten Konfigurationseinstellungen sind mittlerweile im Programm via Touchscreen verfügbar, dennoch kann es nötig oder gewünscht sein, unmittelbar auf das Dateisystem oder die Ordnerstruktur des Raspberry Pi zuzugreifen.

			Die einfachste Möglichkeit ist der Anschluss einer USB-Tastatur an den Raspberry Pi und Beenden des Startup-Skripts zur Kommandozeile. Alternativ kann auch per SSH über den stationären Rechner auf {\REF} zugegriffen werden.

			Hierzu muss sichergestellt sein, dass sich {\REF} mit dem Drahtlosnetzwerk verbunden hat, um die lokale IP-Adresse (beispielsweise: 192.168.0.5) ermitteln zu können. Als SSH-Client kann das bereits als Terminalprogramm bekannte \texttt{Putty} verwendet werden, welches man mit folgenden Parametern startet:
			\begin{center}
				\emph{putty.exe -ssh pi@192.168.0.5}
			\end{center}

			Nun muss man beim ersten Verbindungsaufbau den SSH-Schlüssel bestätigen und wird dann nach dem Passwort gefragt. Das Standardpasswort für den Nutzer \enquote{pi} lautet \emph{raspberry}. Ab diesem Punkt ist das Vorgehen mit direkt angeschlossener Tastatur oder SSH-Zugang identisch.

		\section{Anpassung und Umbenennung von AES-Schlüsseln}

			Ist der Zugriff eingerichtet, wird eine der ersten Tätigkeiten die Einstellung des passenden AES-Schlüssels sein, damit {\REF} und die Zündboxen von {\anlage} dieselbe Sprache sprechen.

			Ausgangspunkt auf der Bash ist das Home-Verzeichnis des Users \enquote{pi}, von dort kann man mit der Eingabe
			\begin{center}
				\emph{cd raspEasyFire3/config}
			\end{center}
			ins Verzeichnis der Konfigurationsdateien wechseln. Auch wenn an dieser Stelle keine ausführliche Linux-Einführung gegeben werden soll, sei kurz darauf hingewiesen, dass Linux im Gegensatz zu Windows bei Datei- und Verzeichnisnamen \enquote{case sensitive} ist, also genau auf Groß- und Kleinschreibung achtet.

			In diesem Verzeichnis befinden sich von Haus aus drei Dateien, namentlich
			\begin{description}
				\item[raspEasyFire.conf] Die Konfigurationsdatei mit grundlegenden Programmeinstellungen. Mit einer Raute (\#) beginnende Zeilen stellen dabei Kommentare dar, welche die Bedeutung der nachfolgenden Einstellungen demonstrieren, Einstellungen selbst werden in der Form \enquote{Variable: Wert} angegeben. Typischerweise sollte es nicht notwendig sein, hier Einstellungen zu ändern, der derzeit ausgewählte Zündplan wird beispielsweise immer automatisch durch das eigentliche Programm aktualisiert, andere Einstellungen können in der {\REF}-Oberfläche geändert werden.
				\item[aesvalues\_default.txt] Diese Datei enthält den Standard-AES-Schlüssel, der zur Kommunikation mit den Zündboxen verwendet wird. Die Werte heißen \enquote{value\_01, \dots, value\_16} und müssen im Hexadezimalformat, d.h. mit vorangestelltem \enquote{0x} angegeben werden, der Wertebereich für jeden einzelnen \enquote{value} geht von \enquote{0x00} bis \enquote{0xFF}.
				\item[aesvalues.txt] Diese Datei enthält den derzeit im Programm verwendeten AES-Schlüssel. Im Auslieferungszustand ist sie mit \emph{aesvalues\_default.txt} identisch.
			\end{description}

			Um einen eigenen AES-Schlüssel, welcher beispielsweise den Namen \enquote{mykey} tragen könnte, anzulegen, empfiehlt es sich, die Datei \emph{aesvalues\_default.txt} zunächst mit dem Kopierbefehl \emph{cp} zu duplizieren:
			\begin{center}
				\emph{sudo cp aesvalues\_default.txt aesvalues\_mykey.txt}
			\end{center}
			Das Voranstellen von \emph{sudo} führt dazu, dass der Befehl mit Administratorrechten ausgeführt wird, so dass man sich keine Gedanken um eingeschränkte Schreibrechte machen muss.

			Zum Anpassen des Dateiinhalts steht der simple Texteditor \enquote{nano} zur Verfügung, per
			\begin{center}
				\emph{sudo nano aesvalues\_mykey.txt}
			\end{center}
			startet man die Bearbeitung.

			In \enquote{nano} werden dann die entsprechenden Einstellungen vorgenommen, beendet wird das Programm durch die Tastenkombination \enquote{STRG + X}, anschließend bestätigt man die Nachfrage, ob die Änderungen gespeichert werden sollen.

			Um die Daten aus \emph{aesvalues\_mykey.txt} zu verwenden, kann man sie entweder später im Programm per Touchscreen auswählen oder direkt via
			\begin{center}
				\emph{sudo cp aesvalues\_mykey.txt aesvalues.txt}
			\end{center}
			zur neuen Standardeinstellung machen.
			
			Ebenso ist es möglich, eine Textdatei im passenden Format nach dem Vorbild der \emph{aesvalues\_default.txt} mit einem Namen, der mit \emph{aesvalues\_} beginnen und auf \emph{.txt} enden muss~-- beispielsweise \emph{aesvalues\_customized.txt}, ins Hauptverzeichnis eines USB-Sticks zu kopieren und diesen beim Starten in den Raspberry Pi zu stecken. Genau wie bei Zündplänen und Musikdateien~(siehe hierzu Abschnitt~\ref{sec:zplusbstick}) werden diese Dateien dann automatisch ins korrekte Verzeichnis kopiert und ersetzen eventuell bereits vorhandene Dateien mit gleichem Namen.
			
			Auch die im Abschnitt~\ref{sec:reffirststart} angesprochene Datei \enquote{sysinfo.txt} kann über einen USB-Stick zum {\REF} übertragen werden. Um eine Dauerschleife zu vermeiden, wird die Datei auf dem Stick im Anschluss automatisch in \enquote{sysinfo.txt.applied} umbenannt.

		\section{Passwort ändern}
			Um den Zugriff für unbefugte Personen auf den Raspberry Pi zu verhindern, sollte unbedingt das Passwort des Users \enquote{pi} geändert werden. Möglich ist dies über ein Menü, welches man aus der Bash über
			\begin{center}
				\emph{sudo raspi-config}
			\end{center}
			erreicht.

		\section{Zündpläne und Musikdateien übertragen}
			\REF{} verarbeitet unmittelbar in {\pic} erzeugte zpl-Dateien, so dass die Shows bequem am eigenen Rechner konzipiert werden können. Für die Übertragung der Dateien existieren grundsätzlich zwei Möglichkeiten, entweder über einen USB-Stick oder via Netzwerk über das SFTP-Protokoll. Bei Musikdateien muss es sich um mp3-Dateien handeln, welche auch die Endung \enquote{.mp3} besitzen, Zündpläne müssen auf \enquote{.zpl} enden und Dateien, die zusammen gehören, müssen denselben Namen tragen: Eine Show \enquote{Feuerwerk.zpl} verlangt demnach nach einer Musikdatei \enquote{Feuerwerk.mp3}.

			\subsection{USB-Stick}
			\label{sec:zplusbstick}

				Um Zündpläne und Musikdateien via USB-Stick zu übertragen, müssen die Dateien im Hauptverzeichnis eines USB-Sticks abgelegt werden und dieser Stick vor dem Hochfahren des Systems mit dem Raspberry Pi verbunden werden. Der Stick wird dann automatisch erkannt und die zpl- bzw. mp3-Dateien in die Verzeichnisse \url{/home/pi/raspEasyFire3/showfiles/zpl} bzw. \url{/home/pi/raspEasyFire3/showfiles/mp3} kopiert. Bereits dort existierende Dateien gleichen Namens werden ohne Nachfrage überschrieben.

			\subsection{SFTP}

				Unmittelbar übers Netzwerk können Dateien durch ein Programm wie den \enquote{FileZilla FTP Client} verschoben werden. Dort muss dann im Servermanager eine SFTP-Verbindung erstellt werden, wobei der Server der internen IP-Adresse von {\REF} entspricht und die Zugangsdaten mit Nutzername \enquote{pi} und dem entsprechend gewählten Passwort anzugeben sind. Auch hier wird bei erstmaliger Verbindung typischerweise eine Bestätigung gefordert, anschließend kann man durch das Dateisystem navigieren und die Show- und Musikdateien in den entsprechenden Verzeichnissen \url{/home/pi/raspEasyFire3/showfiles/zpl} bzw. \url{/home/pi/raspEasyFire3/showfiles/mp3} ablegen.

		\section{Die Benutzeroberfläche}

			Durch Drücken des FIRE-Buttons nach dem Hochfahren, startet die Benutzeroberfläche von {\REF}, sie ist in Abbildung~\ref{fig:REFstartscreen} gezeigt.

			\begin{figure}
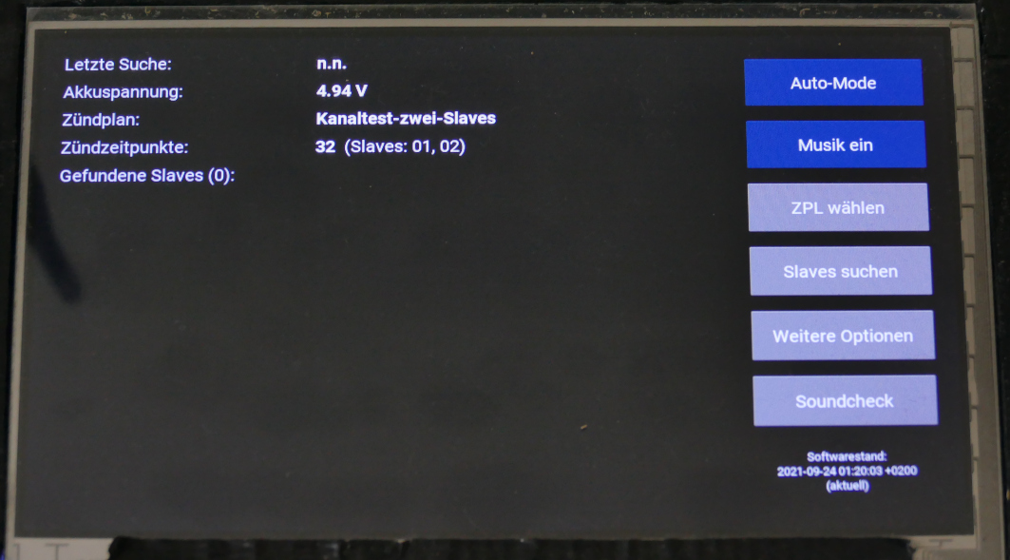
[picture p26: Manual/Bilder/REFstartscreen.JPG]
				\centering
				\caption{Startbildschirm nach dem Aufruf von \REF}
				\label{fig:REFstartscreen}
			\end{figure}

			Im linken Teil des Bildschirms werden einige Informationen wie der aktuelle Zündplan oder die gemessene Batteriespannung angezeigt, am rechten Rand des Bildschirms sind die Schaltflächen zur Bedienung via Touchscreen zu sehen:
			\begin{enumerate}
				\item
				      Modusauswahl
				      \begin{description}
					      \item [Auto-Mode]
					            Vollautomatisches Zünden nach Zeitplan
					      \item [Semi-Auto-Mode]
					            Manuelle Zündung per Knopfdruck mit vorgegebener Reihenfolge
					      \item [Manual Mode]
					            Vollständig manuelle Zündung
				      \end{description}
				\item
				      Musikbegleitung an/aus
				\item
				      Zündplanauswahl
				\item
				      Slavesuche
				\item
				      Weitere Optionen
				\item
				      Soundcheck
			\end{enumerate}
		
			Zusätzlich wird das Datum der Erstellung der aktuell verwendeten Software angezeigt, bei aktiver Internetverbindung kommt dazu der Hinweis, ob die Software dem aktuellen Stand auf dem Server entspricht oder älter ist. Updates können über den in Abschnitt~\ref{sec:onlineupdate} beschriebenen Bereich durchgeführt werden.

			\subsection{Zündplanauswahl}

				Anwählen des Punktes \enquote{ZPL wählen} führt zum in Abbildung~\ref{fig:REFzplwahl} gezeigten Bildschirm. Hier kann aus den im Programmunterverzeichnis \enquote{showfiles/zpl} vorhandenen Zündplänen gewählt werden. Die Auswahl ist abschließend zu bestätigen, um den gewählten Zündplan zu laden.

				Analog verhält es sich im manuellen Modus mit Musik mit der Auswahl der MP3-Datei, sofern die Musikbegleitung aktiviert ist.

				\begin{figure}
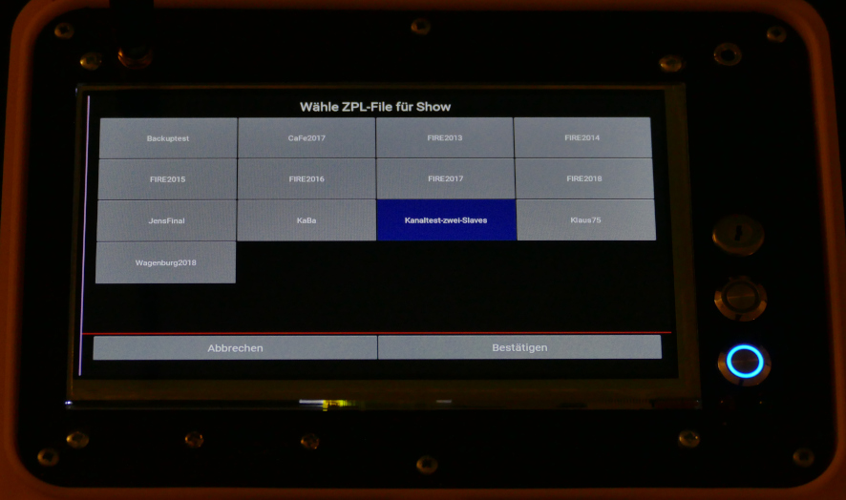
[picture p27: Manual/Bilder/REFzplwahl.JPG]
					\centering
					\caption{Auswahl des Zündplans}
					\label{fig:REFzplwahl}
				\end{figure}

				Die Auswahl von Zündplan bzw. Musikstück wird jeweils gespeichert und ist dann auch beim nächsten Programmstart aktiv.

			\subsection{Slavesuche}

				Mit einem Druck auf die Schaltfläche \enquote{Slaves suchen} wird eine Suche nach verfügbaren Zündboxen gestartet. Deren Dauer ist von der maximalen Slaveanzahl abhängig, anschließend werden die Parameter der in Reichweite befindlichen Boxen wie in Abbildung~\ref{fig:REFslavesfound} zu sehen auf dem Startbildschirm angezeigt.

				Die Anzeige der gefundenen Boxen erfolgt farblich kodiert. Wird eine Box gefunden, deren Slave-ID im aktuell ausgewählten Zündplan Verwendung findet, so werden ihre Daten in weißer Schrift ausgegeben, Boxen mit nicht verwendeter Slave-ID werden in einem Goldton gelistet. Dies dient als Hinweis an den User.
				
				Die gezeigten Parameter jeder einzelnen Box sind:
				\begin{itemize}
					\item Unique-ID
					\item Slave-ID
					\item Kanalanzahl
					\item Batteriespannung
					\item Scharfschaltungsstatus
					\item Temperatur
					\item Empfangsleistung beim Empfang der Identifizierungsaufforderung
					\item Aktueller Squelch-Wert des Funkmoduls
					\item Farbliche Markierung für die Größe der Differenz zwischen Empfangsleistung und Squelch als Indikator für die Ausfallwahrscheinlichkeit
				\end{itemize}

				In Klammern hinter \enquote{Gefundene Slaves} taucht zudem die Gesamtanzahl gefundener Zündboxen auf. Werden weniger Boxen als erwartet gefunden, sollten~--sofern mehrmaliges erneutes Suchen keinen Erfolg gebracht hat~-- folgende Ursachen und Lösungsversuche in Erwägung gezogen werden:
				\begin{enumerate}
					\item
					      Box nicht eingeschaltet oder Batterie leer $\Rightarrow$ Einschalten, Batterie laden/tauschen
					\item
					      Unterschiedliche AES-Schlüssel $\Rightarrow$ AES-Schlüssel abgleichen
					\item
					      Fehlende Funkverbindung durch Hindernisse, Abschattung, schlecht angebundene Antenne $\Rightarrow$ Boxposition anpassen für direkte Sichtlinie, Schraubverbindung der Antenne fest (aber nicht zu fest) anziehen, Abstand zwischen Box und {\REF} verringern
					\item
					      Datenkollision durch gleiche Unique-IDs $\Rightarrow$ Zuteilung einer anderen Unique-ID
				\end{enumerate}

				Erscheint unter dem Punkt \enquote{Letzte Suche} der Hinweis \enquote{SQUELCH-WARNUNG}, so bedeutet dies, dass das Funkmodul während der Suche häufig durch Signale, welche nicht von einer Zündbox kamen, abgelenkt wurde. In einem solchen Fall sollte die RSSI-Schwelle des Senders neu kalibriert werden, weil sie zu sensibel eingestellt ist, siehe hierzu Abschnitt~\ref{sec:weitereoptionen}. Dasselbe gilt, wenn keine \enquote{SQUELCH-WARNUNG} ausgegeben wurde, aber möglicherweise nicht alle Zündboxen gefunden wurden. Dann liegt die eingestellte Schwelle möglicherweise zu hoch.

				\begin{figure}
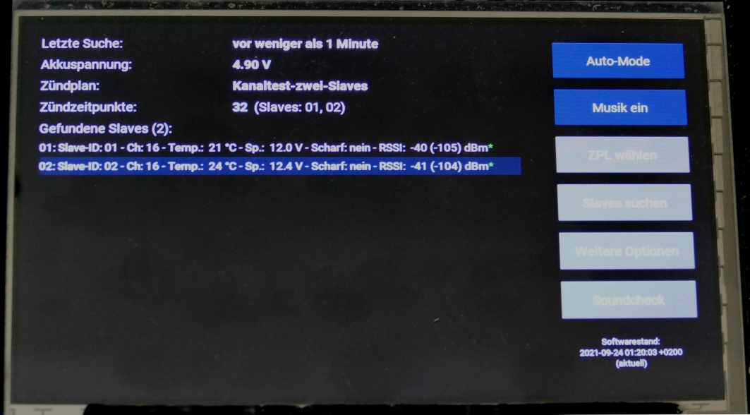
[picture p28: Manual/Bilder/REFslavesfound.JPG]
					\centering
					\caption{Anzeige der gefundenen Boxen}
					\label{fig:REFslavesfound}
				\end{figure}

			\subsection{Weitere Optionen}
			\label{sec:weitereoptionen}
				Über diesen Menüpunkt erhält man Zugang zu weiteren Untermenüs und Funktionen.

				\subsubsection{Einstellungen anpassen}
					Unter diesem Punkt können einige Grundeinstellungen des Programms verändert werden:
					\begin{description}
						\item [Showmodus beim Start]
						      Welche Art der Show soll beim Programmstart standardmäßig eingestellt sein? Diese Einstellung wird erst nach Neustart von {\REF} aktiv und hat keine Auswirkung auf die aktuelle Einstellung im Programm.
						\item [Ton standardmäßig aus?]
						      Soll die Standardeinstellung \enquote{Musik an} oder \enquote{Musik aus} lauten? Auch diese Einstellung wird erst nach Neustart von {\REF} aktiv und hat keine Auswirkung auf die aktuelle Einstellung im Programm.
						\item [Eingebautes Funkmodul]
						      Wird mit dem Funkmodul RFM69CW gearbeitet oder mit der Variante RFM69HCW mit höherer Sendeleistung? Eine nicht zur tatsächlich verbauten Hardware passende Einstellung führt dazu, dass die Funkverbindung mit den Zündboxen schon bei geringen Distanzen nicht aufgebaut werden kann.
						\item [Herunterfahren beim Beenden]
						      Soll nach dem Beenden von {\REF} das System komplett heruntergefahren oder in den Commandprompt gesprungen werden?
						\item [Fehlende Slaves ignorieren]
						      Soll beim Überprüfen der automatischen oder semiautomatischen Show darauf bestanden werden, dass jede im Zündplan genannten Slave-ID (außer Slave 999) auch tatsächlich mindestens einmal vorhanden, die verfügbare Kanalzahl größer oder gleich der maximal bei dieser Slave-ID adressierten Kanalnummer ist und alle Slaves scharf geschaltet sind oder nicht? Für den manuellen Modus hat diese Einstellung keine Bedeutung.
						\item [Soundcheck mit Showmusik]
						      Soll die aktuell ausgewählte Musik für den Soundcheck verwendet werden? Bei \enquote{Nein} wird das Standard-Teststück (showfiles/mp3/test.mp3) verwendet.
						\item [Lautstärke]
						      Lautstärkeeinstellung der Soundkarte für die Wiedergabe der Musik in Prozent.
						\item [Maximale Anzahl Slaves]
						      Wie viele Slaves sind zulässig? Dieser Wert ist gleichzeitig auch der Maximalwert für Unique-ID und Slave-ID einer einzelnen Box. Je größer dieser Wert gewählt wird, umso länger dauert auch die Slavesuche, weil das Programm jeder Unique-ID einen Zeitschlitz fester Länge zuweist, um auf eine Identifizierungsanfrage zu antworten.
						\item [RSSI-Schwellwert (dBm) -- Sender]
							  Minimale Empfangsleistung (Squelch-Wert) für {\REF}. Ab welcher Leistung soll das Funkmodul versuchen, ein ankommendes Signal zu detektieren. Diese Einstellung ist wichtig für korrekt funktionierenden Funkverkehr. Ein zu hoher Wert verringert die Funkreichweite, ein zu geringer Wert führt zu Fehltriggerungen durch Rauschen und blockiert die Empfangseinheit für tatsächliche Nachrichten. Der Wert kann manuell eingestellt werden oder durch einen Druck auf \enquote{Cal.} durch einen Suchalgorithmus ermittelt werden. Bei erfolgreicher Kalibrierung wechselt der Buttontext auf \enquote{Cal. ok} und schlägt einen Wert vor, der jedoch noch zu bestätigen ist.
						\item [RSSI-Schwellwert (dBm) -- Boxen]
						      Squelch-Wert für Zündboxen; durch einen Druck auf \enquote{Send} kann ein gemeinsamer Squelch-Wert für alle Zündboxen in Reichweite eingestellt werden. Ausgehend von diesem Wert führen die Zündboxen jedoch individuell und kontinuierlich eine weitere Squelch-Anpassung durch, um ihren minimalen Empfangspegel möglichst optimal an die bestehenden örtlichen Gegebenheiten anzupassen. 
					\end{description}

					Diese Einstellungen können durch \enquote{Bestätigen} dauerhaft übernommen oder durch \enquote{Abbrechen} wieder verworfen werden. Squelch-Einstellungen für die Zündboxen werden nicht automatisch gesendet, sondern nur per Druck auf den \enquote{Send}-Button.

				\subsubsection{Updates durchführen}
				\label{sec:onlineupdate}
					Bei bestehender Internetverbindung kann hier die Software von \REF{} auf den letzten Stand gebracht werden. Ein Neustart ist nötig, um die Änderungen wirksam zu machen, der ausgewählte Zündplan wird auf die Standardeinstellung zurückgesetzt, AES-Key und Funkmoduleinstellung bleiben nach einem Update erhalten. Zudem werden die Veröffentlichungszeiten der lokalen und auf dem Server liegenden Software angezeigt.

				\subsubsection{Verwendeten AES-Key wählen}
					In diesem Fenster kann gewählt werden, mit welcher der im Unterverzeichnis \emph{config} vorhandenen AES-Schlüssel-Dateien, welche einen Dateinamen der Form \emph{aesvalues\_NAME.txt} tragen müssen, gearbeitet werden soll. Die jeweils aktuell gewählte Datei ist blau markiert.

					Sofern keins der Auswahlfelder markiert ist, entspricht der Inhalt der \emph{aesvalues.txt} keiner der vorhandenen Dateien des Namensschemas \emph{aesvalues\_NAME.txt}. Dies sollte man durch Auswahl eines Feldes und anschließendes Bestätigen beheben, um wieder einen definierten Zustand zu erreichen.
					
					Es besteht in diesem Feld auch die Möglichkeit, einen eigenen \enquote{Custom}-Key zu erzeugen. Dies geschieht auf Basis der Seriennummer des verwendeten Raspberry Pi sowie weiterer Zufallszahlen. Wurde dieser Key bereits erzeugt und seitdem nicht gelöscht, kann kein neuer erzeugt werden.

				\subsubsection{AES-Key mit Box abgleichen}
					Wird eine eingeschaltete Zündbox über USB-Kabel (v3) bzw. einen RS232-USB-Konverter (v1/v2) an den Raspberry Pi angeschlossen, kann unter diesem Punkt ihr AES-Schlüssel ausgelesen werden. Unterscheidet er sich vom aktuell in {\REF} eingestellten Schlüssel, kann der Nutzer entscheiden, wessen Schlüssel auf das andere Device übertragen werden soll.

				\subsubsection{El Fueradoro flashen}
					In diesem Untermenü ist es möglich, die aktuellen Bootloader- und Firmwaredateien für \anlage{} herunterzuladen sowie über einen geeigneten Programmer den Bootloader auf ein El-Fueradoro-Device zu schreiben und bei vorhandenem Bootloader die Firmware zu übertragen. Zu diesem Zweck muss das Device von {\anlage} per Programmer (Bootloader) oder USB-Kabel (Firmware v3) bzw. USB-RS232-Adapter (Firmware früherer Generationen) mit \emph{raspEasyFire} verbunden werden. Standardmäßig sind im Image keine Firmwaredateien enthalten, vor dem ersten Flashen müssen diese also zwingend heruntergeladen werden. Den korrekten Bootloader und die korrekte Firmware für das angeschlossene Device (Generation/Funkmodul/Kanalzahl) auszuwählen, ist zunächst Aufgabe des Benutzers, mit Firmwareversionen ab September 2021 ist es jedoch auch möglich, das angeschlossene Device zu identifizieren, woraufhin direkt die passende Firmware zum Flashen ausgewählt wird.

				\subsubsection{Slave ID ändern}
					Zündboxen können neue IDs zugewiesen werden, den Bildschirm dazu zeigt Abbildung~\ref{fig:REFids}. Hierzu müssen per \enquote{+} und \enquote{-} die alten und neuen IDs eingestellt werden, durch Druck auf \enquote{Bestätigen} wird der Befehl zur Änderung der IDs dann abgeschickt. Es ist zu beachten, dass diese Änderung nur wirksam werden kann, wenn die entsprechende Zündbox nicht scharf geschaltet ist.

					\begin{figure}
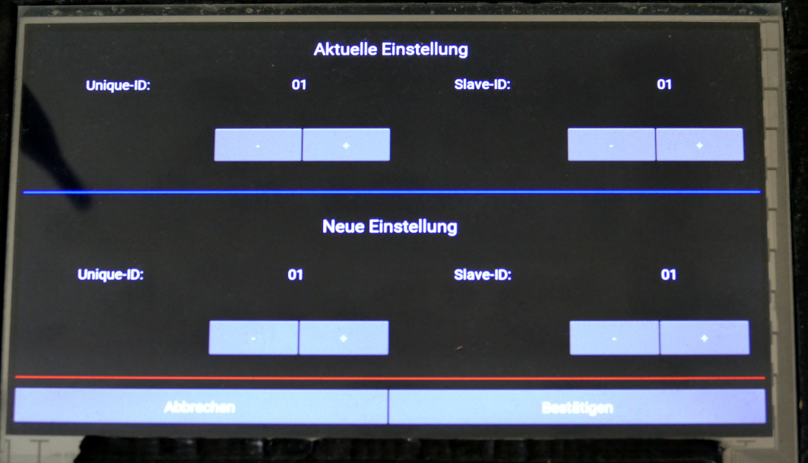
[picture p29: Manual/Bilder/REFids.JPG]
						\centering
						\caption{Ändern der IDs}
						\label{fig:REFids}
					\end{figure}

				\subsubsection{Fuoco Step flashen}
					In diesem Untermenü ist es möglich, die aktuellen Bootloader- und Firmwaredateien für den Stepper \emph{Fuoco Step} herunterzuladen sowie über einen geeigneten Programmer den Bootloader auf den \emph{Fuoco Step} zu schreiben und bei vorhandenem Bootloader die Firmware zu übertragen. Zu diesem Zweck muss der Stepper per Programmer (Bootloader) oder USB-Kabel (Firmware) mit \emph{raspEasyFire} verbunden werden.

				\subsubsection{Fuoco Step konfigurieren}
					Über diesen Menüpunkt können Stepsequenzen im \emph{Fuoco Step} programmiert werden. Auch hierfür ist eine Kabelverbindung nötig, da \emph{Fuoco Step} nicht in der Lage ist, Funksignale zu senden oder zu empfangen.

			\subsection{Dateien löschen}
				Hier können zpl- und mp3-Dateien sowie AES-Schlüssel und Logs gelöscht werden. Nicht löschbar sind Dateien, welche aktuell für die Show oder den Soundcheck ausgewählt sind, der Standard-AES-Schlüssel, der derzeit aktive AES-Schlüssel sowie der Log der aktiven Sitzung.

			\subsection{Soundcheck}

				Durch einen Druck auf den Button \enquote{Soundcheck} wird die in der Konfigurationsdatei eingestellte Soundcheckdatei wiedergegeben, möglich ist dies nur im nicht scharfgeschalteten Zustand. Beendet wird der Soundcheck durch Drücken des FIRE-Buttons oder Drehen des Schlüsselschalters in die \enquote{scharfe} Position.

			\subsection{Widerstandsmessung}

				Durch Anklicken der entsprechenden Zeile in Abbildung~\ref{fig:REFslavesfound} fordert man eine {\anlage}-Zündbox dazu auf, die Widerstände ihrer 4, 16 oder 32 Kanäle zu messen und an {\REF} zu senden. Diese werden dann in tabellarischer Form angezeigt wie in Abbildung~\ref{fig:REFimpedances} gezeigt. Am unteren Rand des Bildschirms kann zur jeweils nächsten und vorherigen Box oder zurück zum Startbildschirm gesprungen werden.

				\begin{figure}
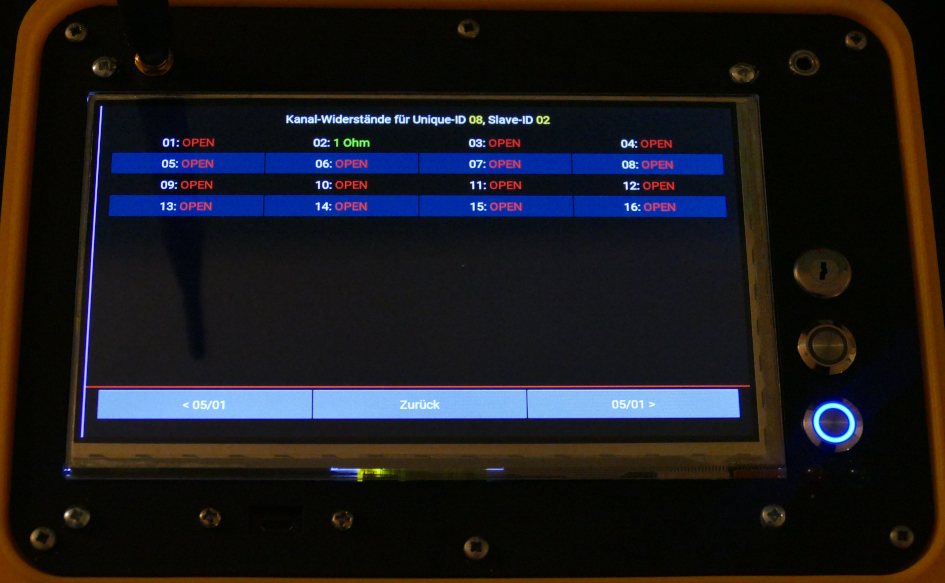
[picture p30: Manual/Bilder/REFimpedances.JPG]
					\centering
					\caption{Widerstandsmessung}
					\label{fig:REFimpedances}
				\end{figure}

				Frühere Generationen der Zündboxen (vor v3) können keine Widerstandsmessung durchführen, sie geben daher für alle Kanäle den Wert \enquote{n.a.} (not available) zurück.

			\subsection{Besonderheiten in Zündplänen}

				Um die Funktionalität der zpl-Dateien zu erweitern, die Kompatibilität mit \pic{} aber zu erhalten, existieren einige Schlüsselwörter und -zahlen, die für \pic{} keine Bedeutung haben, in \REF{} aber entsprechend interpretiert werden:
				\begin{description}
					\item [STEPPER]
					      Findet sich die Zeichenfolge \enquote{STEPPER} in einer Effektbeschreibung, so signalisiert dies \REF{}, dass der entsprechende Slave an diesem Kanal einen Stepper angeschlossen hat und der Kanal deshalb unter Umständen mehrfach gezündet werden darf, um den nächsten Effekt am Stepper zu triggern.
					\item [NOBUTTON]
					      Diese Zeichenfolge in der Effektbeschreibung verhindert, dass für den jeweiligen Effekt in der Liste der Showcues, siehe hierzu Abschnitt~\ref{sec:REFshowstart}, ein Button erstellt wird.
					\item [EXTEND]
						  Vereint die beiden Optionen STEPPER und NOBUTTON. Dies kann dazu dienen, Zündkanäle für eine bestimmte Zeit offenzuhalten, beispielsweise für den Betrieb eines Flamers.
					\item [BACKUP]
					      Findet sich die Zeichenfolge \enquote{BACKUP} in einer Effektbeschreibung, wird der Effekt nicht in die automatische Zündliste eingefügt, sondern als Schaltfläche auf dem Touchscreen hinterlegt, von wo aus er dann manuell während der Show ausgelöst werden kann. Es spielt dabei keine Rolle, ob die Slave-Kanal-Kombination woanders im Feuerwerk verwendet wird oder nicht, man kann also sowohl zur händischen \enquote{Nachzündung} als auch für zusätzliche Pausen- oder Lückenfüller Backups hinterlegen. Die Option BACKUP sticht die ihr teils widersprechenden Optionen STEPPER, NOBUTTON und EXTEND aus.
					\item [Slave 999]
					      Durch Verwendung der Slave-ID 999 wird \REF{} mitgeteilt, dass es sich hierbei nicht um einen tatsächlich zu schießenden Cue handelt, sondern nur um etwas, was auf dem Bildschirm angezeigt werden soll, beispielsweise durch einen zeitgesteuerten Stepper gezündete Cues oder Erinnerungen an eine bestimmte Aktion.
				\end{description}

				Seit April 2021 ist es mit \REF{} möglich, mehrere Slave-Kanal-Kombinationen (maximal 7 verschiedene) gleichzeitig zu zünden. Hierbei ist bei der Erstellung des Zündplans darauf zu achten, dass die Werte in der Spalte \enquote{Zündzeitpunkt} bzw. \enquote{Ignition Time} für die gleichzeitig zu feuernden Kombinationen identisch sind. Nur dann fasst \REF{} sie zu einem gemeinsamen Zündbefehl zusammen. Die Einschränkung, dass zwischen zwei Zündbefehlen mit nicht identischem Zündzeitpunkt mindestens \SI{100}{\milli\second} liegen müssen, bleibt weiterhin bestehen. In gleicher Weise wie Showcues können auch Backupcues zu Multicues zusammengefasst werden.

			\subsection{Showstart}
			\label{sec:REFshowstart}

				Gestartet wird die Show im aktuell eingestellten Modus durch Drücken des FIRE-Buttons, es müssen allerdings bestimmte Voraussetzungen erfüllt sein, damit es wirklich losgehen kann.

				Damit die Show reibungslos verläuft, kontrolliert {\REF}, ob Zündpläne und sonstige Gegebenheiten korrekt sind. Folgende Bedingungen müssen dabei für eine automatische Show erfüllt sein:
				\begin{itemize}
					\item
					      Verwendete Slave-IDs müssen im Bereich von 1 bis zum in den Einstellungen festgelegten Maximum liegen, Slave-ID 999 ist zulässig für \enquote{Dummy-Cues}, die zwar auf dem Display angezeigt werden, aber keine Zündung auslösen.
					\item
					      Ansprechbare Kanalnummern liegen im Bereich von 1 bis 32.
					\item
					      Jede Kombination aus Slave-ID und Kanalnummer darf im Zündplan lediglich einmal vorkommen. Dient der Kanal der Triggerung eines weiteren Geräts, soll also wirklich mehrfach ausgelöst werden, so ist in die Effektbeschreibung bei jedem Aufruf \enquote{STEPPER} (Großschreibung beachten) mit einzutragen, auch das Hinzufügen von \enquote{BACKUP}, falls man bei Versagen der Zündung noch einmal manuell nachzünden möchte, unterbindet die Fehlermeldung.
					\item
					      Der Abstand zwischen zwei \enquote{echten} Zündungen muss mindestens \SI{100}{\milli\second} betragen, für Dummy-Cues gilt diese Beschränkung demnach nicht.
					\item
					      Für jede angesprochene Slave-ID (Ausnahme ist die Dummy-Slave-ID 999) muss mindestens eine Zündbox mit der entsprechenden Slave-ID gefunden worden sein. Zusätzlich wird geprüft, ob der maximale auf dieser Slave-ID angesprochene Kanalwert von den vorhandenen Boxen erreicht werden kann. Um diese Überprüfung abzuschalten, kann über \enquote{Weitere Optionen} und \enquote{Einstellungen anpassen} die Option \enquote{Fehlende Slaves ignorieren} auf \enquote{Ja} gesetzt werden.
					\item
					      Alle gefundenen Zündboxen, deren IDs im Feuerwerk verwendet werden, müssen scharf geschaltet sein. Auch diese Überprüfung wird übersprungen, wenn die Option \enquote{Fehlende Slaves ignorieren} auf \enquote{Ja} gesetzt ist.
					\item
					      Ist eine Musikshow vorgesehen, muss eine zum Zündplan passende Musikdatei im korrekten Verzeichnis vorhanden sein. Ebenso muss die in der Konfigurationsdatei benannte Soundcheckdatei existieren.
					\item
					      Bei einer Musikshow müssen alle Zündzeitpunkte innerhalb der Dauer des Musikstücks liegen, da die Zündzeiten mit dem Zeitstempel des Audioplayers abgeglichen werden. Möchte man Zündungen nach dem Ende des Musikstücks setzen, muss die mp3-Datei durch das Hinzufügen von Stille am Ende verlängert werden.
					\item
					      {\REF} muss durch den Schlüsselschalter scharf geschaltet sein.
				\end{itemize}

				Wird der FIRE-Button gedrückt, ohne dass die nötigen Voraussetzungen erfüllt sind, erscheint ein Info-Popup, welches die zu behebenden Probleme auflistet. Es empfiehlt sich, mit großem Zeitpuffer vor Beginn der Show einen Trockenlauf zu machen, um auf Fehler, die vor Ort nicht mehr allzu leicht zu beheben sind, aufmerksam zu werden.
				
				Sind alle Bedingungen erfüllt, beginnt die FIRE-Button-LED nach dem Drehen des Schlüsselschalters in die \enquote{scharfe} Position zu blinken und ein Druck auf den FIRE-Button startet die Show.

				Beispiele für die Ansicht im automatischen (mit Backup-Cues) und manuellen Modus sind in Abbildung~\ref{fig:REFauto} bzw. Abbildung~\ref{fig:REFmanual} gezeigt.

				Im automatischen Modus befinden sich in der unteren Bildschirmhälfte zwei Listen: Einerseits die horizontal scrollbare Liste (das automatische Scrollen zum aktuellen Showzeitpunkt kann durch Drücken auf die angezeigte Einstellung deaktiviert oder aktiviert werden) der automatischen Zündungen, darunter die Liste der explizit festgelegten Backup-Cues. Durch Drücken des FIRE-Buttons und anschließendes Betätigen der entsprechenden Schaltfläche bei noch gedrücktem FIRE-Button können ein Backup-Cue oder ein Show-Cue erneut bzw. auch vorzeitig ausgelöst werden.

				\begin{figure}[b]
					\begin{subfigure}{\textwidth}
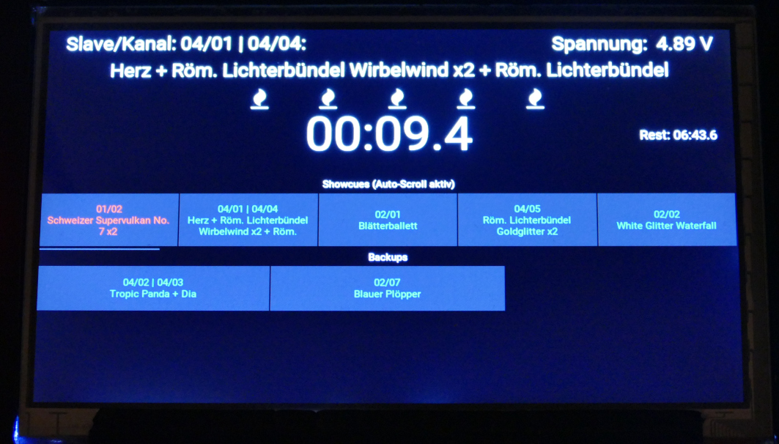
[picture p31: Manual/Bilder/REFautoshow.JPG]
						\centering
						\caption{Automatischer Modus}
						\label{fig:REFauto}
					\end{subfigure}
					\newline
					\begin{subfigure}{\textwidth}
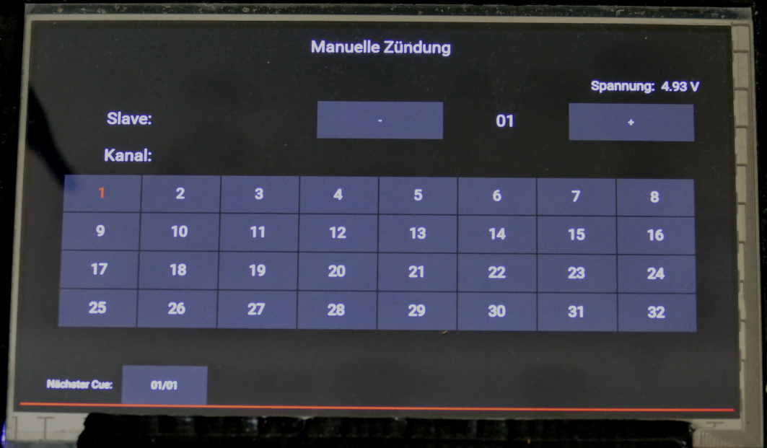
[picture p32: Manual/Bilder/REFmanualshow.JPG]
						\centering
						\caption{Manueller Modus}
						\label{fig:REFmanual}
					\end{subfigure}
					\caption{Bildschirme während der Show}
				\end{figure}

	\chapter{Show}
		In diesem Kapitel gibt es einige Hinweise zur Planung und Umsetzung eines choreographierten Feuerwerks.
		\section{Vorbereitung}

			\subsection{Beidseitiges Zünden}
				Gerade in Musikfeuerwerken steht man häufig vor der Herausforderung, ein durch die Dramaturgie des Musikstücks sehr genau abgestecktes Zeitintervall mit Effekten füllen zu müssen. Ist die Laufzeit einer Cakebox länger als dieses Intervall und besitzt der Effekt eine Reservezündschnur, kann die Laufzeit durch eine weitere Zündung an der Reservezündschnur entsprechend verkürzt werden.

				Ab dem Zeitpunkt der zweiten Zündung wird die Restlaufzeit der Batterie halbiert, da die Anzündlitze dann von beiden Seiten abbrennt. Bezeichnet man das Zeitintervall zwischen erster und zweiter Zündung mit ${\Delta}t$ und die ursprüngliche Laufzeit als $T_\text{original}$, ergibt sich die neue Laufzeit $T_\text{neu}$, die zwischen der halben und der ganzen ursprünglichen Laufzeit liegen kann, aus
				\begin{equation}
					T_\text{neu} = \frac{T_\text{original} + {\Delta}t}{2}.
					\label{eq:gegenzuendung}
				\end{equation}

				Durch Umstellen der Formel \eqref{eq:gegenzuendung} kann der Abstand zwischen den beiden Zündzeitpunkten bei festgelegter neuer Laufzeit bestimmt werden:
				\begin{equation}
					{\Delta}t = 2 {\cdot} T_\text{neu} - T_\text{original}
				\end{equation}

				Soll also eine Batterie mit einer Laufzeit von $\SI{60}{\second}$ in $\SI{40}{\second}$ abgebrannt werden, muss die zweite Zündung $\SI{20}{\second}$ nach der ersten ausgelöst werden. Hierbei kommt es natürlich auch zu einer Verdichtung der Effekte.

			\subsection{Zündkreisauslegung}

				An dieser Stelle soll kurz auf die Grenzen und Limits von {\anlage} hinsichtlich der Zündkreise eingegangen werden, die bei der Planung einer Show zu berücksichtigen sind. Die Charakteristika und Kennwerte der einzelnen Anzündertypen sind Anlage 2 der 1.\,SprengV zu entnehmen.

					{\anlage} ist für die Verwendung mit den Anzündertypen A (Auslösestrom $\SI{0,6}{\ampere}$) und U (Auslösestrom $\SI{1,3}{\ampere}$) ausgelegt. Der nötige Strom zum Auslösen eines HU-Anzünders (Auslösestrom $\SI{25}{\ampere}$) kann nicht geliefert werden. Es ist zu berücksichtigen, dass in der Anlage ein Strombegrenzungswiderstand von $\SI{2,2}{\ohm}$ verbaut ist, der in Reihe zum angeschlossenen Anzünder-Netzwerk liegt. Mittels Formel~\eqref{eq:zuendkreisrmax} kann der maximal zulässige Widerstand (inklusive der $\SI{2,2}{\ohm}$) für einen gegebenen mittleren Strom $I$ ermittelt werden.

				\begin{equation}
					R_\text{max} = \frac{50}{47 {\cdot} \ln\left(\frac{\SI{423}{\ampere}}{\SI{423}{\ampere} - 20 {\cdot} I}\right)}\si{\ohm}
					\label{eq:zuendkreisrmax}
				\end{equation}

				Entsprechend resultiert für einen gegebenen Widerstand der mittlere Strom über eine Zeit von $\SI{10}{\milli\second}$ aus Gleichung~\eqref{eq:zuendkreisi}.
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

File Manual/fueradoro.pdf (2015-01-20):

Benutzerhandbuch | Dokumentation | Aufbauanleitung

El

# Fueradoro

## Funkgesteuertes Zündsystem für Feuerwerke

## Felix Pflaum (f.pflaum@gmail.com)

20.01.2015, 10:45

3

# Wichtige Hinweise

Vor Inbetriebnahme sollte in jedem Fall diese Anleitung gelesen und verstanden werden! Speziell die folgenden, weiter hinten in der Anleitung detaillierter ausgeführten Hinweise müssen beachtet werden, um Personenschäden oder Beschädigungen an den Geräten zu vermeiden:

### 1. Das Metallgehäuse des SMA-Antennenanschlusses an der Oberseite der Zünd-

box liegt auf Massepotential, die roten Anschlussklemmen nach dem Einschalten und unter Umständen auch noch Minuten nach dem Ausschalten bei 22,5 V. Ein Kurzschluss zwischen diesen beiden Punkten ist daher unbedingt zu vermeiden, um Schäden an der Schaltung und ungewollte Zündungen zu verhindern. Daher, sofern der Antennenanschluss nicht isoliert ist, beim Anschließen die Zünder immer zuerst mit der schwarzen Klemme, danach mit der roten verbinden, beim Abklemmen zuerst das Kabel an der roten, dann das an der schwarzen Klemme lösen. Weiterhin sollte man die Zündbox erst in ihrer endgültigen Position einschalten, so dass ein unbeabsichtigtes Herausziehen der Kabel tunlichst ausgeschlossen ist. Sicherheitshalber kann auch der SMA-Stecker nach dem Anschrauben mit Klebeband isoliert werden.

### 2. Devices nie ohne angeschlossene Antenne einschalten, um Rückreflexionen an

offenen Steckern/Buchsen zu vermeiden, welche die Sendeendstufe zerstören könnten.

### 3. Keine Softwareupdates an Zündboxen durchführen, solange Zünder angeschlos-

sen sind, da das Verhalten nach einem fehlgeschlagenen Update unvorhersehbar ist.

Trotz aller Sorgfalt bei der Entwicklung von Hard- und Software sowie ausgiebigen Tests seitens der Entwickler kann keinerlei Garantie für Sicherheit und Funktionalität von El Fueradoro sowie keine Haftung für Sach- und Personenschäden, welche sich direkt oder indirekt aus dem Einsatz von El Fueradoro ergeben, übernommen werden. Es werden mit El Fueradoro dem Anwender lediglich Schaltpläne, Layouts und Programmcode sowie Hinweise zu Aufbau und Verwendung einer elektronischen Funkzündanlage, welche er frei weiter verbreiten und verändern darf, zur Verfügung gestellt. El Fueradoro ist und bleibt ein Hobby-Bastelprojekt, kein geprüftes oder in irgendeiner Form zertifiziertes Produkt!

Der Umgang mit Feuerwerkskörpern und explosivem Material unterliegt in Deutschland gesetzlichen Restriktionen, deren Einhaltung im Verantwortungsbereich des Anwenders liegt. El Fueradoro darf nicht von Personen unter 18 Jahren bedient werden.

5

# Credits

Vielen Dank an alle, die in irgendeiner Form zur Entwicklung von El Fueradoro beigetragen haben!

Ein ganz spezielles Dankeschön an:

- Das gesamte private Umfeld, das die Arbeit am Projekt stets mit Fassung getragen hat
- mikrocontroller.net für Hilfe in Sachen Hardware und Programmierung
- feuerwerk-forum.de für Steuersoftware und Erklärungen zum Thema elektrische Zündung
- Saleae (http://www.saleae.com) für den grandiosen Logic 8, der wertvolle Dienste zur Erschließung des RFM69 geleistet hat
- Die vielen tollen Open-Source- und Freeware-Lösungen, welche die Softwareentwicklung erst möglich gemacht haben:

– Die GCC-Community für die AVR-GCC-Toolchain zum Programmieren des Mikrocontrollers

– Die Eclipse-Foundation für die Programmierumgebung Eclipse

– Kees Bakker und Thomas Holland für die Eclipse-Erweiterung AVREclipse

– Peter Dannegger für den robusten, aber dennoch schlanken Bootloader FastBoot

– Subversion und TortoiseSVN

– LATEXzur Erstellung des Handbuchs

7

# Inhaltsverzeichnis

I | Benutzerhandbuch | 13
1 Das System | 15
2 Vorbereitung des PCs | 21
3 Kommunikation zwischen PC und Devices | 25
4 Firmwareupdate | 33
II | Dokumentation | 35
5 Schaltpläne & Layouts | 37
6 Software | 43
III Aufbauanleitung | 45
7 Materialliste | 47

8 | El Fueradoro
8 Platinenherstellung | 53
9 Bohrschablone | 57
10 Antennenbau | 59
11 Pinbelegung | 63
12 Aufspielen des Bootloaders | 65
13 Kompilieren der Firmware | 67

9

# Abbildungsverzeichnis

1.1 Systemübersicht El Fueradoro | | 16
1.2 Transmitter | | 17
1.3 Zündbox von oben, eingebettet in Koffer | | 18
1.4 LCD während der Show | | 19
1.5 Schalter und serielle Schnittstelle an der Zündbox | | 20
2.1 Eintrag des USB-RS232-Adapters im Gerätemanager | | 22
2.2 Einstellungen für Puttytel | | 23
3.1 Startbildschirm des Konfigurationsprogramms | | 27
3.2 Beispiel einer ferngesteuerten ID-Zuweisung | | 29
3.3 Systemübersicht | | 30
5.1 Schaltplan des Transmitters | | 38
5.2 Schaltplan der Zündbox | | 39
5.3 Layout des Transmitters (keine Originalgröße!) | | 40
5.4 Layout der Zündbox (keine Originalgröße!) | | 41
8.1 Ober- und Unterseite des Transmitters für Toner-Transfer-Verfahren/Belichtung | 54
8.2 Ober- und Unterseite der Zündbox für Toner-Transfer-Verfahren/Belichtung . . . | 55
8.3 Adapterplatine für Funkmodule (8 Stück) für Toner-Transfer-Verfahren/Belichtung 56
9.1 Bohrschablone für Zündboxoberseite | | 58
10.1 Antenne ohne Schrumpfschlauch (links) und komplett fertig (rechts) | | 60
10.2 VSWR-Messung der gefertigten Antenne am Netzwerkanalysator | | 61
11.1 Pinbelegung des Mikrocontrollers bei Transmitter und Zündbox | | 63

12.1 Pinbelegung des ISP-Platinensteckers: Ansicht von oben, Aussparung an Pin 5.
Quelle: mikrocontroller.net | 65

11

# Tabellenverzeichnis

1.1 Farben und Funktionen der Status-LEDs | | 19
2.1 Konfiguration der seriellen Schnittstelle | | 22
3.1 Kommandos zur Konfiguration über die serielle Schnittstelle | | 26
3.2 Umrechnung Hexadezimal-, Dezimal- und Binärwerte | | 31
3.3 Struktur des RFM69CW-Befehls | | 31
6.1 Quellcodedateien und ihre Funktionen | | 43
7.1 Materialliste für den Transmitter | | 48
7.2 Materialliste für die Zündbox | | 52

13

# Teil I

# Benutzerhandbuch

15

# 1 Das System

El Fueradoro ist eine Eigenentwicklung zur automatisierten Zündung von Feuerwerkschoreographien per Computer und Funk, der Name El Fueradoro leitet sich aus den spanischen Wörtern fuego, radio und oro her und bedeutet frei übersetzt daher so etwas wie „Goldenes Funkfeuer“. Sie wurde zur Verwendung mit der frei verfügbaren Software Pyro Ignition Control von Yannic Wilkening (Version 1.4.5) geplant.

Es besteht aus einer mit dem PC verbundene Transmitterbox, welche die von Pyro Ignition Control generierten Zündbefehle per Funk an die Zündboxen weitergibt und einer oder mehreren Zündboxen mit je 16 Kanälen zur elektrischen Zündung. Der klassische Aufbau des Systems ist schematisch in Abbildung 1.1 gezeigt. Die reine Transmitterbox wird nicht zwingend benötigt; es kann alternativ auch eine Zündbox per Kabel mit dem PC verbunden werden und neben ihrer originären Aufgabe auch die Transmitteraufgaben bewältigen.

Um möglichst große Flexibilität bei der Gestaltung eines Feuerwerks mit El Fueradoro zu gewährleisten, was z.B. die Anzahl der verwendeten Zündboxen oder auch die Tatsache angeht, dass man identische Effekte gerne zeitgleich an zwei weiter voneinander entfernten Orten zünden möchte, können den Boxen per Software zwei Kennnummern (Slave-ID und Unique-ID) zugewiesen werden. Genaueres dazu findet sich im Abschnitt 3.

Transmitterbox und Zündbox sind in Abbildung 1.2 bzw. 1.3 mit ihren wesentlichen Bestandteilen gezeigt. Sie werden im weiteren Text unter dem Begriff „Devices“ zusammengefasst, falls sich Aussagen auf beide Teile beziehen, und in den folgenden Kapiteln näher beschrieben.

## 1.1 Aufbau

Detailliertere Infos zum Aufbau erhalten interessierte Leser im nächsten Teil dieses Dokuments. An dieser Stelle soll nur kurz auf die Funktionalität eingegangen werden. Herzstück aller Devices ist der 8-bit-Mikrocontroller ATmega328P von Atmel, welcher die verschiedenen Peripheriebausteine kontrolliert. In jedem Device befinden sich ein Funkmodul RFM69CW von HopeRF, welches die drahtlose Kommunikation zwischen den einzelnen Devices übernimmt, ein RS232-Treiberbaustein MAX202 mit an die Gehäuseaußenseite geführter Sub-D-Buchse zur Kommunikation zwischen Mikrocontroller und PC sowie vier Status-LEDs.

Die Transmitterbox ist mit einem LC-Display mit 20 Spalten und 4 Zeilen ausgestattet.

In den Zündboxen befinden sich zwei vom Mikrocontroller gesteuerte kaskadierte Schieberegister

16 | El Fueradoro

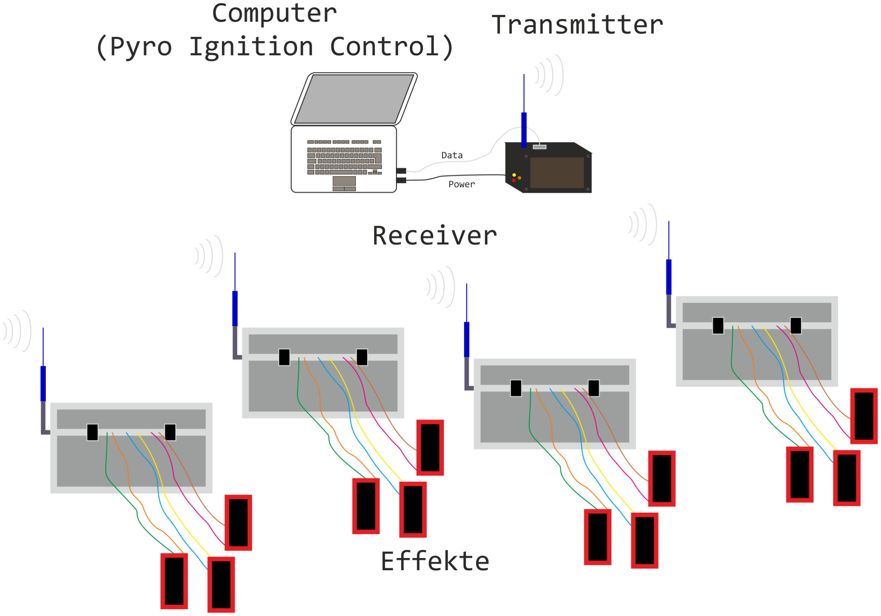
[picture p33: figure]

Abbildung 1.1: Systemübersicht El Fueradoro

74HC595, welche mit ihren insgesamt 16 Ausgängen 16 Feldeffekttransistoren vom Typ IRF3708 für die Zündung ansteuern, außerdem ist auf der Platine mit dem MC33063 ein Hochsetzsteller zur Erzeugung einer höheren Zündspannung integriert sowie ein Schlüsselschalter zum Scharfschalten der Boxen. Parallel zur Drain-Source-Strecke jedes Feldeffekttransistors ist eine LED mit Vorwiderstand geschaltet, um zu signalisieren, an welchen Kanälen Zünder angeschlossen sind.

## 1.2 Transmitterbox und Zündboxen

Die in Abbildung 1.2 gezeigte Transmitterbox dient dazu, die Zündbefehle des PCs per Funk an die über das Gelände verteilt stehenden Zündboxen weiterzuleiten sowie das komplette Funksystem zu überwachen. Hierzu ist im Inneren der Transmitterbox sowie der Zündboxen ein Funkmodul für das – im Rahmen der Vorschriften der jeweiligen nationalen Aufsichtsbehörde, in Deutschland der Bundesnetzagentur – frei nutzbare Frequenzband um 868 MHz verbaut. Die Datenübertragung vom PC geschieht über eine serielle Schnittstelle.

Die Zündboxen, in Abbildung 1.3 dargestellt, empfangen die Anweisungen und zünden die einzelnen Kanäle. Jede Zündbox verfügt über 16 einzeln ansteuerbare Zündkanäle. Jeweils eine rote und eine schwarze Klemme bilden einen Zündkanal, die Nummerierung beginnt links unten mit Kanal 1 und endet rechts oben mit Kanal 16. Alle roten Klemmen sind nach dem Einschalten unmittelbar mit einer Gleichspannung von 22,5 V verbunden, die schwarzen Klemmen mit dem Drain-Anschluss eines von 16 n-Kanal-MOSFETs. Parallel zur üblicherweise sperrenden Drain-Source-Strecke jedes MOSFETs ist eine grüne LED mit Vorwiderstand geschaltet, welcher den

El Fueradoro | 17


Abbildung 1.2: Transmitter

Strom über den LED-Zweig auf unter 5 mA begrenzt, so dass ein Zünden über die LED ausgeschlossen ist. Sobald die zugehörige schwarze Klemme mit einer roten Klemme – die Zuordnung kann beliebig erfolgen, obwohl zwecks Übersichtlichkeit natürlich ratsam ist, die nebeneinander liegenden Klemmen zu nutzen – verbunden ist, also ein geschlossener Strompfad von 22,5 V zur Schaltungsmasse besteht, wird dies durch Leuchten der zur schwarzen Klemme gehörigen LED signalisiert.

## 1.3 Energieversorgung

Die in unmittelbarer Nähe des zu steuernden PCs platzierte Transmitterbox bezieht ihre nötige elektrische Energie aus dem USB-Port eines PCs. Das fest mit der Transmitterbox verbundene USB-Kabel dient ausschließlich diesem Zweck. Sie verfügt über keinen Ein/Aus-Schalter, sondern ist eingeschaltet, solange sie mit dem USB-Port verbunden und der PC eingeschaltet ist. Da der USB-Port „angezapft“ wird, ohne in der sonst üblichen Weise mit dem Controller zu kommunizieren, empfiehlt sich, die USB-Verbindung erst nach komplett abgeschlossenem Bootvorgang herzustellen und vor dem Herunterfahren des Rechners wieder zu trennen.

Aufgrund der anzunehmenden Platzierung der Zündboxen im freien Feld, abseits von Steckdosen und anderen Energiequellen werden sie über eine Batterie versorgt. Um ordnungsgemäße Funktionalität zu garantieren und Schäden an der Schaltung zu vermeiden, muss die Batteriespannung zwischen 8 V und 15 V liegen! Empfohlen wird die Verwendung

18 | El Fueradoro

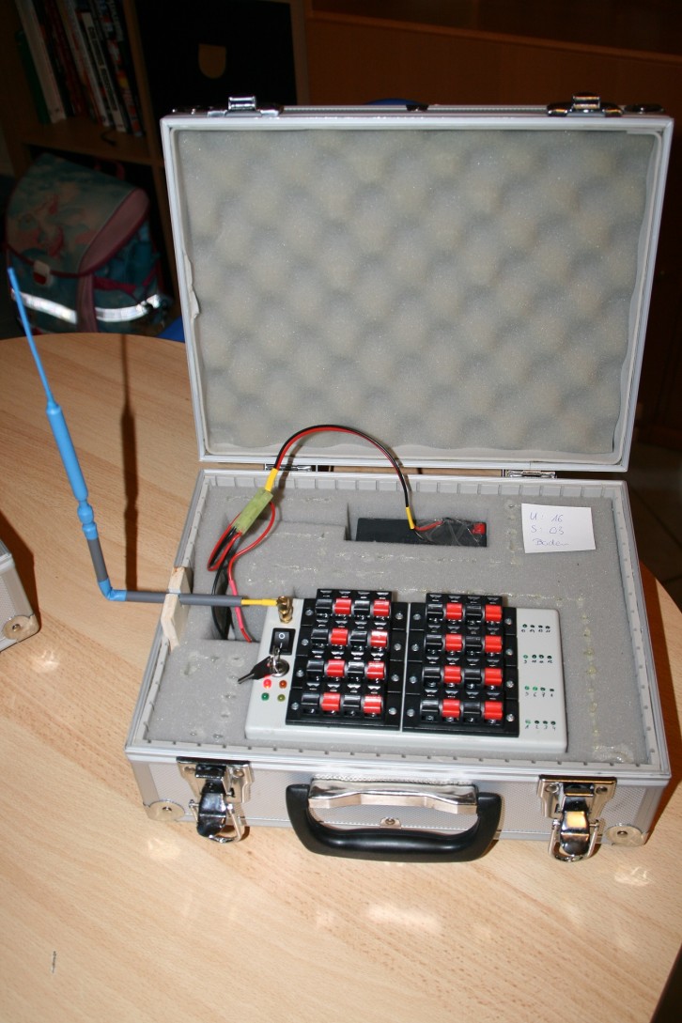
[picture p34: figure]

Abbildung 1.3: Zündbox von oben, eingebettet in Koffer

El Fueradoro | 19
Farbe | Funktion
orange | Funkmodul empfängt
grün | Funkmodul sendet
gelb | Daten kommen über serielle Schnitt-
| stelle an
rot | Zündbox ist scharf geschaltet

Tabelle 1.1: Farben und Funktionen der Status-LEDs


Abbildung 1.4: LCD während der Show

eines Blei-Vlies-Akkus mit Nennspannung 12 V, wie er auch in Abbildung 1.3 über der Zündbox zu erahnen ist.

## 1.4 Die Status-LEDs

Alle Devices verfügen über vier Status-LEDs. Bei den Transmitterboxen liegen sie direkt neben dem Kabel für die Energieversorgung auf der Seite, bei den Zündboxen auf der Oberseite. Diese sind mit ihrer Bedeutung in Tabelle 1.1 aufgeführt und leuchten, wenn das jeweilige Device die mit der LED verknüpfte Tätigkeit ausführt. Das Blinken der grünen LED während des Initialisierungsvorgangs jedes Devices ist von der sonstigen Funktion unabhängig.

Bei einem Zündvorgang leuchten für die Dauer der Zündung (11 ms) alle vier LEDs.

## 1.5 Das LCD der Transmitterbox

Aktuelle Statusanzeigen werden bei der Transmitterbox auf dem LC-Display ausgegeben. Ein Beispiel zeigt Abbildung 1.4. In Zeile 1 wird hinter der Abkürzung „Tx“ (Transmitted) der letzte

20 | El Fueradoro


Abbildung 1.5: Schalter und serielle Schnittstelle an der Zündbox

gesendete Befehl (Zündbefehl oder Identifizierungsaufforderung) angezeigt, in Zeile 2 – im Bild nicht zu sehen – ggf. hinter der Abkürzung „Rx“ (Received) die letzte empfangene Rückmeldung (angeforderte Parameter).

In den Zeilen 3 und 4 werden die letzten sechs gesendeten Kommandos aufgelistet. Zwei zweistellige Zahlen getrennt durch ein Flammensymbol stehen dabei für einen Zündbefehl. Die erste Zahl gibt die Slave-ID, die zweite den zu zündenden Kanal an. Für den Fall, dass eine Aufforderung zur Identifikation gesendet wurde, erscheint „IDENT“, für eine Aufforderung zur Temperaturmessung „TEMP“. Das „x“ steht immer vor dem bis dato letzten Befehl, springt also mit jedem neuen Befehl eine Stelle weiter.

Alle Zeilen werden nach einer bestimmten Zeit automatisch gelöscht.

## 1.6 Schalter an den Zündboxen

Die Zündboxen verfügen, wie in Abbildung 1.5 zu erkennen, über zwei Schalter, einen schwarzen Wippschalter zum Ein- und Ausschalten der Energieversorgung sowie einen Schlüsselschalter, um die Zündbox „scharf“ zu schalten.

Die Scharfschaltung durch den Schlüsselschalter geschieht auf die Weise, dass durch eine Zustandsabfrage vor der Zündung letztere nur ausgeführt wird, wenn das Schloss auf den grünen Punkt am Gehäuse zeigt. Befindet sich der Schlüssel in waagrechter Stellung und zeigt auf den roten Punkt, so ist der Schalter geöffnet und Zündbefehle werden von der Box ignoriert. Für das Scharfschalten der Box ist der Anwender selbst verantwortlich.

Ob Boxen scharf geschaltet sind, ist an der Box – wie in Abschnitt 1.4 ausgeführt – durch das Dauerleuchten der roten Status-LED erkennbar, kann aber auch durch eine Identifizierungsabfrage ausgelesen werden (siehe Abschnitt 3.2).

21

# 2 Vorbereitung des PCs

Zur Kommunikation mit einem Computer verfügen alle Devices über eine serielle Schnittstelle. Pyro Ignition Control sollte ohnehin auf dem Rechner installiert sein, für die serielle Kommunikation gibt es für Windows zudem zahlreiche Terminalprogramme.

## 2.1 Installation eines USB-RS232-Adapters

Zunächst steht man allerdings in der Regel vor dem Problem, dass zwar die Devices eine serielle Schnittstelle besitzen, moderne Rechner aber nicht mehr mit dem früher standardmäßig verbauten 9-poligen Sub-D-Stecker der RS232-Schnittstelle ausgestattet sind. Diese wurden seit dem Ende der 1990er-Jahre von den USB-Schnittstellen verdrängt. Sollte wider Erwarten am einzusetzenden Rechner ein derartiger Anschluss vorhanden sein, können die nächsten Absätze übersprungen und der COM-Port direkt im Gerätemanager anhand von Tabelle 2.1 konfiguriert werden. Wer nur über USB-Ports verfügt, lese unmittelbar weiter.

Weil in vielen Bereichen noch immer auf RS232 zurückgegriffen wird, existieren Adapterkabel wie in Abbildung 1.2 mit USB-Anschluss für den Rechner und einem 9-poligen RS232-Stecker für den Anschluss an der Peripherie, also die Devices von El Fueradoro. In diesen Adapterkabeln ist ein Chip verbaut, um die Signalumsetzung von USB auf RS232 und umgekehrt zu bewerkstelligen. Übliche verwendete Chips sind der CH340¹
, welcher sich in vielen über eBay aus China angebotenen Modellen befindet, der Prolific PL2303²
in verschiedenen Versionen oder – bei edleren und somit auch teureren Varianten – der uneingeschränkt zu empfehlende FTDI232, mit welchem die in den folgenden Abschnitten beschriebenen Probleme nicht auftreten sollten.

Das Plug-and-Play-Traumszenario, dass sich der Adapter bei der Verbindung des USB-Steckers mit dem Rechner automatisch korrekt installiert, tritt gerade bei den günstigen Adaptern leider nur sehr selten ein. Die in den Fußnoten verlinkten Treiber sollten, sofern die automatische Treiberinstallation von Windows versagt, ihren Dienst tun, müssen allerdings teilweise mit sanfter Gewalt installiert werden. Hat man die Installation erfolgreich absolviert, sollte bei angeschlossenem Adapterkabel ein neuer Eintrag in der Art von Abbildung 2.1 im Gerätemanager auftauchen.

Weil viele Chips dazu tendieren, sich beim Anschluss an immer wieder andere USB-Ports neu zu

1Treiber CH340/341: http://wch.cn/download/list.asp?id=5
2Falls die automatische Treiberinstallation unter Windows fehlschlägt, funktioniert – mit zeitweiligen Aussetzern – oft der Treiber unter: http://www.cartft.com/support/drivers/TFT/tftdrivers/GPS/PL2303_Prolific_GPS_1013_20090319.zip (http://www.cartft.com/support/drivers/TFT/tftdrivers/GPS/PL2303_Prolific_GPS_1013_20090319.zip)

22 | El Fueradoro


Abbildung 2.1: Eintrag des USB-RS232-Adapters im Gerätemanager

installieren bzw. eine andere COM-Port-Nummer anzunehmen, wird empfohlen, für den USB-RS232-Adapter stets denselben USB-Steckplatz zu nutzen.

Durch Doppelklick auf den Eintrag und den Reiter Anschlusseinstellungen kann die nun vorhandene serielle Schnittstelle unter Windows konfiguriert werden. Um Kompatibilität mit Pyro Ignition Control zu gewährleisten, ist das Hauptfenster nach Tabelle 2.1 zu konfigurieren.

Unter der Schaltfläche erweitert kann man zudem die Puffer ausschalten, was aber nicht zwingend notwendig ist und die Funktionsweise normalerweise weder positiv noch negativ beeinflusst, sowie die Portnummer für den neu geschaffenen COM-Port einstellen.

## 2.2 Einrichtung des Terminalprogramms

Hardware- und treiberseitig steht einer erfolgreichen Kommunikation von Rechner und Devices nun nichts mehr im Wege, für eine komfortable Unterhaltung außerhalb von Pyro Ignition Control fehlt aber noch die entsprechende Software. Empfohlen wird die Verwendung des kostenlosen

Bits pro Sekunde | 9600
Datenbits | 8
Parität | keine
Stoppbits | 1
Flusssteuerung | Hardware

Tabelle 2.1: Konfiguration der seriellen Schnittstelle

El Fueradoro | 23


Abbildung 2.2: Einstellungen für Puttytel

Programms Puttytel³
, mit welchem auch die im Rahmen dieser Anleitung gezeigten Beispiele durchgeführt werden. Es besteht nur aus einer einzigen ausführbaren Datei.

Puttytel kann per Doppelklick gestartet werden, woraufhin man zu einem Startbildschirm gelangt. Man wählt in der linken Spalte unten links „Serial“ und stellt die Parameter – analog zur Konfiguration des COM-Ports nach Tabelle 2.1 – wie in Abbildung 2.2 ein, ehe man die serielle Verbindung per Klick auf „Open“ startet. Vor dem Start der Verbindung sollte man das verbundene Device mit Strom versorgen.

Um bei Puttytel nicht immer all diese Einstellungen per Hand vornehmen zu müssen, bietet sich an, unter Windows eine Verknüpfung auf puttytel.exe zu erstellen und in den Verknüpfungseigenschaften als Ziel anzugeben:

"c:\programme\puttytel\puttytel.exe" -serial com24 -sercfg 9600,8,1,n,R

Die ohne Leerzeichen auf „com“ folgende Zahl ist natürlich entsprechend dem verwendeten seriellen Anschluss (COM5, COM37, . . . ) anzupassen.

## 2.3 Einrichtung von Pyro Ignition Control

Um eine reibungslose Kommunikation zwischen Pyro Ignition Control und El Fueradoro sicherzustellen, muss in Pyro Ignition Control als wesentliche Einstellung unter dem Menüpunkt „Einstellungen → Optionen“ im Reiter „Output“ der richtige COM-Port eingestellt werden.

3Herunterzuladen unter: http://www.chiark.greenend.org.uk/~sgtatham/putty/download.html

24 | El Fueradoro

Über „Einstellungen → Connect“ wird die serielle Verbindung aufgebaut und in der untersten Leiste anzeigt, ob der Verbindungsaufbau erfolgreich war.

Zudem sollte im Reiter „Allgemein“ die globale Verzögerung erfahrungsgemäß auf etwa 0,07 s eingestellt werden. Dies ist die Zeit, die aufgrund von Datenübertragungen und Rechenvorgängen zwischen dem Beginn des Sendens des Befehls vom PC zum Transmitter und dem Zünden des Kanals an der Zündbox vergehen.

Als minimale Zeitdauer zwischen zwei Zündungen sollte 100 ms nicht unterschritten werden, das Scharfschalten vor Beginn der Show ist ebenfalls nicht zu vergessen!

Anmerkung: Eine serielle Verbindung kann immer nur ENTWEDER zwischen Puttytel ODER Pyro Ignition Control ODER dem Firware-Updater und dem Device bestehen. Man muss also immer die bestehende Verbindung trennen, bevor man mit einem anderen Programm eine neue aufbauen kann.

25

# 3 Kommunikation zwischen PC und Devices

In diesem Abschnitt wird die Systemüberwachung bzw. -konfiguration über die serielle Schnittstelle mittels Puttytel behandelt. Auf die Kommunikation zwischen Pyro Ignition Control und der Transmitterbox wird an dieser Stelle nicht eingegangen, da hier – wenn alle Einstellungen wie in Abschnitt 2.3 erläutert getroffen wurden – alles quasi-automatisch und ohne Zutun des Benutzers stattfindet.

## 3.1 Befehlsübersicht

Hat man mittels Puttytel eine Verbindung zwischen einem Device und dem PC aufbauen können, sieht man vor sich zunächst nur einen schwarzen Bildschirm. Um nun mit dem Device kommunizieren zu können, existieren einige Befehle gemäß Tabelle 3.1.

Diese können, sofern Puttytel die aktive Anwendung ist, direkt über die PC-Tastatur eingegeben werden und sollten zur unmittelbaren Ausführung mit Druck auf die Taste ENTER abgeschlossen werden. Sobald das erste Zeichen eingegeben wurde, leuchtet die gelbe Status-LED am Device. Unbekannte Befehle werden ignoriert, sämtliche Buchstaben als Kleinbuchstaben interpretiert. Korrekturen sind unter Verwendung der BACKSPACE-Taste möglich.

Aufgrund der eingebauten Timeout-Funktion, welche ein Hängenbleiben des Programms während einer Show verhindern soll, bricht die Firmware die Eingabe ab, wenn zwischen der Eingabe der einzelnen Buchstaben mehr als 3 s vergehen. Lässt man diese Zeit verstreichen, wird automatisch ein Drücken der ENTER-Taste übermittelt, die Befehlseingabe also abgeschlossen und das Device ist unmittelbar bereit, einen neuen Befehl aufzunehmen. Wird also nach Eingabe eines gültigen Befehls die ENTER-Taste nicht gedrückt, wird der Befehl durch den Timeout dennoch ausgelöst. Möchte man dies vermeiden, sollte man den Befehl vor Ausführung durch Eingabe weiterer Zeichen ungültig machen oder durch Entfernen aller Zeichen mittels BACKSPACE löschen.

Von den in Tabelle 3.1 aufgeführten Befehlen funktionieren lediglich zwei nicht bei allen Devices. „orders“ setzt voraus, dass das angeschlossene Device zuvor – über das durch „conf“ zu erreichende Menü – als Transmitterbox konfiguriert wurde bzw. im Fall von „zero“ nicht als Transmitterbox.

26 | El Fueradoro
Befehl | Wirkung
conf | Startet das Konfigurationsprogramm zur lokalen Zuweisung von Slave-
| und Unique-ID
remote | Startet das Konfigurationsprogramm zur ferngesteuerten Zuweisung von
| Slave- und Unique-ID
list | Zeigt die Systemübersicht (Zuweisung Unique- und Slave-ID, Batterie-
| spannung jeder Box, Scharfschaltungsstatus Temperatur, RSSI, Anzahl
| Boxen je Slave-ID)
send | Startet das Menü zur manuellen Eingabe einer Anweisung ans Funkmodul
| (Zündbefehl, Identifizierungsaufforderung oder Temperaturmessung)
fire | Führt zu einer Eingabemaske, in die Slave-ID und Kanal für die Zündung
| einzugeben sind
ident | Sendet eine Identifizierungsaufforderung an alle anderen Devices

temp

Gibt über die serielle Schnittstelle die Temperatur aus und fordert alle anderen Devices ebenfalls zur Temperaturmessung auf. Zum Auslesen der neu gemessenen Temperaturen muss dann eine Identifizierungsanfrage geschickt werden
rfm | Erlaubt unmittelbaren Zugriff auf das Funkmodul durch Eingabe einer
| 16-Bit-Hexadezimalzahl, um Registerwerte auszulesen oder neu zu setzen
orders | Gibt letztes gesendetes und empfangenes Pattern auf LCD aus
zero | Markiert alle Kanäle der verbundenen Zündbox als noch nicht abgefeuert
cls | Löscht den Terminal-Bildschirm
kill | Löst einen Neustart des Device aus

Tabelle 3.1: Kommandos zur Konfiguration über die serielle Schnittstelle

## 3.2 Die Konfiguration

### 3.2.1 Lokal

Mit „conf“ gelangt man ins Konfigurationsmenü für die lokale Konfiguration der IDs, welches den Benutzer wie in Abbildung 3.1 gezeigt empfängt. Hier sind die beiden wichtigsten Parameter jedes Devices, die Unique-ID und die Slave-ID, aufgeführt, die der Benutzer nach eigenen Bedürfnissen vergeben kann.

Die Unique-ID dient der Identifikation jeder einzelnen Zündbox im Funksystem. Jeder verwendeten Zündbox muss daher, um die Funktion von El Fueradoro gewährleisten zu können, eine andere Unique-ID im Bereich von 01-30 (zweistellige Eingabe!) zugeteilt werden.

Die Slave-ID entscheidet, auf welche Zündbefehle eine Zündbox reagiert. Sollen also zwei oder mehr Boxen stets zur selben Zeit denselben Kanal zünden, kann ihnen einfach die gleiche Slave-ID zugewiesen werden. Wie oben ausgeführt muss die Zuweisung der Unique-IDs allerdings eineindeutig sein, d.h. jede Box hat eine unterschiedliche Unique-ID bzw. jede Unique-ID gehört zu genau einer Zündbox.

El Fueradoro | 27

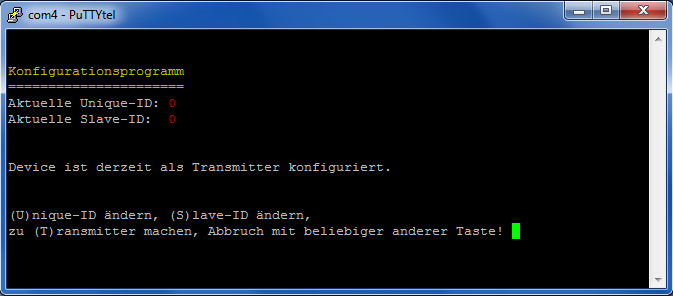
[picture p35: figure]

Abbildung 3.1: Startbildschirm des Konfigurationsprogramms

Die Null als Slave- und Unique-ID identifiziert ein Device als Transmitterbox.

Die Zuweisung von Slave- und Unique-ID vom Startbildschirm des Konfigurationsprogramms aus geschieht, indem man den Anweisungen auf dem Bildschirm folgt. U bzw. u (Groß- oder Kleinschreibung spielt hier keine Rolle) ändert die Unique-ID, S bzw. s die Slave-ID einer Zündbox. T bzw. t macht das Device zum Sender, indem Unique- und Slave-ID auf 0 gesetzt werden. Die neue Unique- bzw. Slave-ID muss stets zweistellig ohne Bestätigung durch Enter oder eine andere Taste eingegeben werden, die Konfiguration als Transmitter kann nicht über die Eingabe von Unique- und Slave-ID, sondern nur über die Eingabe T bzw. t im Hauptbildschirm erfolgen.

Möchte man also die Unique-ID 5 zuweisen, muss man zunächst „u“ und anschließend „05“ eingeben, für Slave-ID 12 dementsprechend „s“ und „12“. Ein Sonderfall tritt auf, wenn man ein zuvor als Transmitter konfiguriertes Device nun als Zündbox konfigurieren will. Es erscheint dann nach Eingabe der neuen Slave-ID (Unique-ID) automatisch die Eingabeaufforderung für die neue Unique-ID (Slave-ID), da entweder beide IDs den Wert 0 haben müssen (Transmitter) oder beide IDs einen anderen Wert als 0 (Zündbox). Die zugewiesenen IDs werden an drei Stellen im internen Speicher mit Prüfsummen hinterlegt und bleiben sowohl nach dem Ausschalten als auch nach einem Firmwareupdate erhalten.

Wie bereits angesprochen ist es möglich, auch eine Zündbox als Transmitter zu verwenden. Damit diese aber gleichzeitig noch als Zündbox fungieren kann, muss die Slave-ID größer sein als 0, da mit Pyro Ignition Control nur Slaves von 01-30 angesprochen werden können.

Als Transmitter (Slave-ID 0 und Unique-ID 0) konfiguriert werden können nur Devices wie in Abbildung 1.2 mit Display und ohne Klemmen für den Anschluss von Zündern. Der Grund hierfür liegt in der in Abbildung 11.1 auf Seite 63 gezeigten Pinbelegung des Controllers. Wie zu erkennen ist, werden Controlleranschlüsse beim Transmitter als Steuerung des Displays verwendet, die bei der Zündbox den Zustand des Schlüsselschalters einlesen oder die Schieberegister zur Zündung der Kanäle ansteuern. Da die Software davon ausgeht, dass ein Device mit Slave-ID und Unique-ID 0 an diesen Pins ein LC-Display besitzt, werden die Pins entsprechend konfiguriert und angesteuert. Im Fall des Schlüsselschalter-Pins kommt es daher zu einem Kurzschluss,

28 | El Fueradoro

wenn die Box scharf geschaltet ist, was den Controller beschädigen kann, die Ansteuerung des Schieberegisters mit LCD-Befehlen führt dazu dass Zündkanäle durchschalten und Zündungen unkontrolliert ausgelöst werden, weil die Software glaubt, die Datenpins des LCD zu modulieren, in Wahrheit aber die Schieberegister ansteuert.

Die Firmware erkennt durch eine Überprüfung des Devices beim Start, ob es sich bei dem angeschlossenen Device um einen Transmitter oder eine Zündbox handelt. Bei Zündboxen ist die Option „Als Transmitter konfigurieren“ daher nicht verfügbar. Der umgekehrte Fall, eine Transmitterbox als Zündbox zu konfigurieren, ist nicht sinnvoll und führt dazu, dass auf dem LCD nur zwei komplett gefüllte Zeilen zu sehen sind. Dies führt aber zu keinerlei Schäden, sobald das Device wieder als Transmitter konfiguriert ist, wird das LCD wieder einwandfrei funktionieren.

Unabhängig davon, dass eine Zündbox nicht als Transmitter konfiguriert werden, also nicht Unique- und Slave-ID 0 besitzen darf, kann sie theoretisch trotzdem zur Steuerung und Koordinierung eines Netzes und einer Show eingesetzt werden, indem man sie über die serielle Schnittstelle mit dem PC verbindet. Bis auf die Darstellung am LCD erfüllt sie dieselben Aufgaben wie ein Transmitter und kann auch parallel noch als Zündbox fungieren. Auf entsprechenden Sicherheitsabstand zu sensibler Technik und Lebewesen ist dabei selbstverständlich zu achten!

### 3.2.2 Ferngesteuert

Über den Befehl „remote“ gelangt man ins Konfigurationsprogramm zur ferngesteuerten Vergabe von Unique- und Slave-ID. Der Programmablauf ist beispielhaft in Abbildung 3.2 gezeigt: Die Eingabe der alten und neuen IDs erfolgt analog zur Eingabe bei lokaler Konfiguration, am Ende muss die Änderung noch bestätigt werden. Werden als alte Unique- und Slave-ID die Daten der verbundenen Box eingegeben, so werden deren Kennzahlen wie bei einer lokalen Konfiguration geändert und kein weiterer Befehl gesendet.

Durch „remote“ und die Eingabe von Unique- und Slave-ID einer nicht per Kabel verbundenen Box ist es möglich, die IDs einer eingeschalteten Zündbox per Funk zu ändern. Voraussetzung ist dabei, dass die angesprochene Zündbox nicht scharf geschaltet ist – hierdurch soll ein Eingriff von außen während einer Show unterbunden werden, aus Sicherheitsgründen ist es außerdem nicht möglich, ein Device ferngesteuert als Transmitter zu konfigurieren.

Der Anwender hat selbst darauf zu achten, durch ein ferngesteuertes Update nicht einem Device eine bereits vergebene Unique-ID zuzuweisen! Falls dies dennoch geschieht, ist das weitere Vorgehen davon abhängig, ob die Devices auch die gleiche Slave-ID besitzen oder nicht. Sind die Slave-IDs nicht identisch, so kann durch einen weiteren „remote“-Befehl die Unique-ID-Zuweisung geändert werden. Bei identischen Slave-IDs funktioniert dies nicht, da stets alle Devices auf den Änderungsbefehl in gleicher Weise reagieren würden. Hier müssen daher alle Devices mit identischen IDs bis auf eines ausgeschaltet werden, dem man dann neue IDs zuweisen kann. Nun kann dann jeweils ein weiteres Device eingeschaltet und seine IDs neu gesetzt werden, bis wieder alle unterschiedliche Unique-IDs besitzen.

El Fueradoro | 29


Abbildung 3.2: Beispiel einer ferngesteuerten ID-Zuweisung

## 3.3 Die Systemübersicht

Mit „list“ ist es möglich, sich die Systemübersicht entsprechend Abbildung 3.3 anzeigen zu lassen. Es werden zwei Tabellen ausgegeben, wobei die obere nach Unique-ID geordnet anzeigt:

1. Welche Slave-ID der Unique-ID zugewiesen ist.
2. Welche Spannung die Batterie der Box mit der entsprechenden Unique-ID liefert.
3. Ist die Box mit der jeweiligen Unique-ID scharf geschaltet: (j)a oder (n)ein.
4. Temperatur im Inneren der Box, sofern die Box über einen eingebauten Temperatursensor verfügt.
5. Wie stark ist das von der Box empfangene Signal (RSSI = Received Signal Strength Indication). Werte stehen nur bei Aufruf von „list“ an einem Device mit RFM69 zur Verfügung.

Die untere Tabelle listet auf, wie viele Boxen mit der entsprechenden Slave-ID derzeit aktiv sind.

Zwischen den beiden Tabellen wird die Anzahl der fehlerhaften IDs aufgelistet. Dies kann entweder auf doppelte Zuweisung von Unique-IDs oder Fehler beim Auslesen der IDs (fehlerhafte Prüfsummen) zurückzuführen sein. Für normalen Betrieb sollte dieser Wert stets 0 betragen.

Der dargestellte Zustand entspricht den empfangenen Parametern nach der letzten Identifikationsaufforderung, für eine möglichst aktuelle Liste sollte also zuvor, wie im Abschnitt 3.4

30 | El Fueradoro

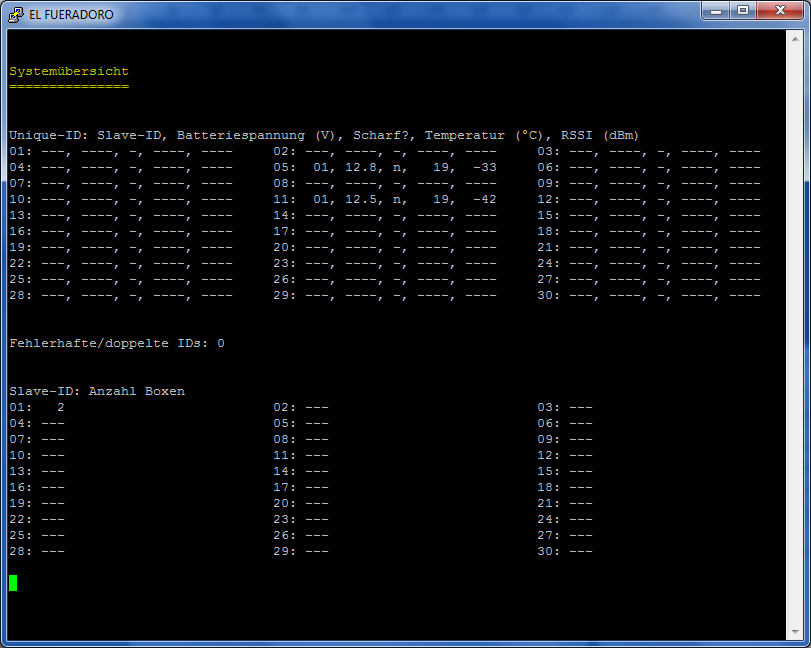
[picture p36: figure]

Abbildung 3.3: Systemübersicht

beschrieben eine Identifikationsaufforderung gesendet werden.

## 3.4 Manuelles Senden

Zu Testzwecken oder um die Systemübersicht zu aktualisieren, können mittels „send“ Zündbefehle und die Aufforderung zur Identifizierung oder Temperaturmessung manuell versendet werden. Nach Eingabe von „send“ muss dies mit „f“ (=fire), „i“ (=identify) oder „t“ (=temperature) ausgewählt werden. Wählt man „i“ oder „t“ ist keine weitere Eingabe nötig, bei „f“ müssen anschließend noch Slave-ID und Kanal jeweils zweistellig eingegeben werden. Statt „send“ und den entsprechenden Buchstaben anzugeben, können auch die direkten Befehle „fire“, „ident“ und „temp“ verwendet werden.

Das Senden einer Identifikationsaufforderung hat zudem den Effekt, dass alle Kanäle in allen Zündboxen als noch nicht abgefeuert gekennzeichnet werden.

Jede andere Angabe als „f“, „i“ oder „t“ beendet den Modus ohne irgendetwas zu senden. Denselben Effekt hat die Eingabe einer Slave-ID oder Kanalnummer außerhalb der jeweils zulässigen Zahlenbereiche.

El Fueradoro | 31
Hexadezimal | 0 | 1 | 2 | 3 | 4 | 5 | 6 | 7
Dezimal | 0 | 1 | 2 | 3 | 4 | 5 | 6 | 7
Binär | 0000 | 0001 | 0010 | 0011 | 0100 | 0101 | 0110 | 0111
Hexadezimal | 8 | 9 | A | B | C | D | E | F
Dezimal | 8 | 9 | 10 | 11 | 12 | 13 | 14 | 15
Binär | 1000 | 1001 | 1010 | 1011 | 1100 | 1101 | 1110 | 1111

Tabelle 3.2: Umrechnung Hexadezimal-, Dezimal- und Binärwerte

## 3.5 Funkmodul-Zugriff

Das verwendete Funkmodul RFM69CW¹ kann unmittelbar über das Terminalprogramm angesprochen werden, um Werte aus seinen Registern zu lesen oder die Register neu zu beschreiben.

Nach Eingabe von „rfm“ und Bestätigung mit ENTER erscheint eine Aufforderung zur Befehlseingabe. Diese hat im Hexadezimalformat als 16-Bit-Wert zu erfolgen, d.h. vierstellig mit den zulässigen Zeichen 0-9 und A-F bzw. a-f. Jedes eingegebene Zeichen symbolisiert dabei vier Bits, die Umrechnung ist in Tabelle 3.2 gezeigt.

Die Bedeutung der Eingabe für das Funkmodul ist in Tabelle 3.3 illustriert. Hierbei sollte auch klar werden, wie sich die Werte für die Zeichen 1-4 zusammensetzen. Ist ein Bit gesetzt, muss die entsprechende Zahl (8, 4, 2, 1) zum Zeichenwert addiert werden, so dass sich bei vier gesetzten Bits als Maximalwert 15 ergibt, ist nur das oberste Bit gesetzt, lautet der Wert 8, ist nur das unterste gesetzt 1, usw.

Es ist zu erkennen, dass das erste einzugebende Zeichen sowohl das Schreiben/Lesen-Bit enthält als auch die obersten drei Bit der Registeradresse. Die acht Datenbits sind lediglich für einen Schreibbefehl relevant, bei einem Lesezugriff kann als drittes und viertes Zeichen ohne Konsequenzen ein beliebiger Hexadezimalwert im Bereich von 0x00 bis 0xFF übertragen werden.

w/r | r6 | r5 | r4 | r3 | r2 | r1 | r0 | d7 d6 d5 d4 d3 d2 d1 d0
Zeichen 1 | Zeichen 2 | Zeichen 3 | Zeichen 4
8 | 4 | 2 | 1 | 8 | 4 | 2 | 1 | 8 | 4 | 2 | 1 | 8 | 4 | 2 | 1
w/r | Schreib- oder Lesezugriff (0 = lesen, 1 = schreiben)
r6 . . . r0 | Registeradresse
d7 . . . d0 | Zu schreibender Registerwert (beliebig falls w/r = 0)

Tabelle 3.3: Struktur des RFM69CW-Befehls

1Links zum Datenblatt: Homepage von Hersteller HopeRF (http://www.hoperf.com/upload/rf/RFM69CW-V1.1.pdf) oder Pollin (http://www.pollin.de/shop/downloads/D810303D.PDF)

32 | El Fueradoro

### 3.5.1 Auslesen der eingestellten Sendeleistung

Zur Veranschaulichung soll hier die Abfrage der aktuell eingestellten Sendeleistung und eine anschließende Änderung derselben simuliert werden: Aus dem Datenblatt, dem die Bedeutungen aller Registeradressen und ihrer acht Registerbits zu entnehmen sind, kann die Registeradresse 0x11 als diejenige identifiziert werden, in der die Informationen zur Sendeleistung hinterlegt sind. Um nun den aktuellen Wert auszulesen, gibt man im Terminalprogramm „rfm“ gefolgt von „ENTER“ ein und anschließend die Zeichenfolge „11FF“, wobei die beiden hinteren Stellen wie erwähnt keine Rolle spielen.

Das Modul antwortet nun mit einem 8-Bit-Wert, z.B. mit dem Wert 0x9A, welcher dem Binärwert 10011010 entspricht, dessen Bedeutung dem Datenblatt entnommen werden kann: Das oberste Bit signalisiert, dass die Verstärkerstufe PA0 aktiv ist, die beiden folgenden Bits sind 0, da PA1 und PA2 in der Variante RFM69CW nicht genutzt werden können. Die unteren fünf Bits schließlich stehen für die eingestellte Sendeleistung, wobei man vom aus den fünf Bits berechneten Wert noch 18 abziehen muss, um die Sendeleistung in dBm zu erhalten. Gesetzt sind die Bits 4, 3 und 1, was dem Wert 26 (= 2⁴ + 2³ + 2¹
) entspricht, daraus resultiert eine eingestellte Sendeleistung von 8 dBm.

### 3.5.2 Setzen der Sendeleistung

Will man die Sendeleistung nun auf 6 dBm anpassen, muss also ein Wert von 24 für die Ausgangsleistungs-Bits gesetzt werden, dazu natürlich auch das oberste Bit für den PA0. Als Wert für die Registerbits ergibt sich damit 2

7 + 2⁴ + 2³ = 0x98. Die Registeradresse bleibt gleich, jedoch muss dem Modul mitgeteilt werden, dass es sich um einen Schreibzugriff handelt, weshalb die erste Stelle um den Wert 8 erhöht werden muss. Um nun den neuen Wert von 6 dBm einzuschreiben, gibt man im Terminalprogramm „rfm“ gefolgt von „ENTER“ ein und anschließend die Zeichenfolge „9198“.

Als Antwort erhält man vom Modul den Registerwert von VOR dem Schreibzugriff, im Beispiel also den Wert 0x9A. Ein nochmaliges Auslesen des Registers wie im Abschnitt 3.5.1 sollte dann den eben eingeschriebenen Wert 0x98 zurückgeben.

33

# 4 Firmwareupdate

WICHTIG: Aus Sicherheitsgründen darf kein Update durchgeführt werden, solange Zünder mit dem Device verbunden sind, da sich die Devices im Falle eines Übertragungsfehlers völlig unvorhersehbar verhalten können.

Die aktuelle Firmware kann aus dem SVN-Repository

http://el-fueradoro.googlecode.com/svn/trunk/

heruntergeladen werden. Sie beinhaltet den kompletten C-Quellcode, das AVR-Eclipse-Projekt, die kompilierten iHex-Dateien für Firmware und Bootloader, die nötigen Software-Tools zur Übertragung zwischen PC und Mikrocontroller sowie die vorliegende Anleitung. Zum Selbstkompilieren wird der Compiler AVR-GCC benötigt.

El Fueradoro bietet die Möglichkeit, die Firmware via serielle Schnittstelle vom PC aus zu aktualisieren. Hierfür gibt es das Programm fwupdate.exe, welches zunächst einen Reset auslöst, um den Bootloader des Devices zu aktivieren und anschließend die im iHex-Format vorliegende Firmware überträgt.

fwupdate.exe muss über die Kommandozeile mit zwei Parametern gestartet werden, nämlich der Angabe der seriellen Schnittstelle und dem Namen der zu übertragenden Firmware-Datei. Aufgrund der Möglichkeit, zwei verschiedene Mikrocontroller und zwei verschiedene Funkmodultypen zu verwenden, existieren vier verschiedene Firmwaredateien, welche sich im gleichen Ordner wie fwupdate.exe befinden sollten.

Um nun die neue Firmware zu übertragen, lautet das Kommando für ein Device am COM4 mit dem ATmega328P und dem Funkmodul RFM69CW:

fwupdate.exe /c4 /fm:Pyro_atmega328p_RFM69.hex

Die Angabe der Dateiendung .hex kann hierbei – ebenso wie das .exe hinter fwupdate – auch weggelassen werden, die Firmware-Datei muss jedoch zwingend auf .hex enden.

fwupdate.exe ist, sofern bereits eine korrekt funktionierende Firmware auf dem Device vorhanden ist, in der Lage, automatisiert zu ermitteln, welche Firmwaredatei die benötigte ist, das Kommando für ein Update über COM4 lautet dann:

fwupdate.exe /c4 /fa

34 | El Fueradoro

Der Updater führt nach Übertragung der Daten einen CRC-Check durch. Sollte dieser fehlschlagen, wurde die Firmware nicht korrekt übertragen. Dies kann zufällig passieren oder auf ein Hardwareproblem, welches in der Regel beim USB-RS232-Adapter liegt, zurückzuführen sein. Für den Fall eines CRC-Fehlers sollte die Firmware erneut übertragen werden. Bleibt das Update beim Punkt „COMx at 9600 baud:“ stehen, sollte die Stromversorgung des Device kurz unterbrochen und wieder aktiviert werden. Das Kabel für die serielle Verbindung bleibt währenddessen mit Device und PC verbunden.

35

# Teil II

# Dokumentation

37

# 5 Schaltpläne & Layouts

In den Abbildungen 5.1 und 5.2 sind die Schaltpläne von Transmitter und Zündbox nach Funktionseinheiten unterteilt gezeigt, in den Abbildungen 5.3 und 5.4 die Layouts.

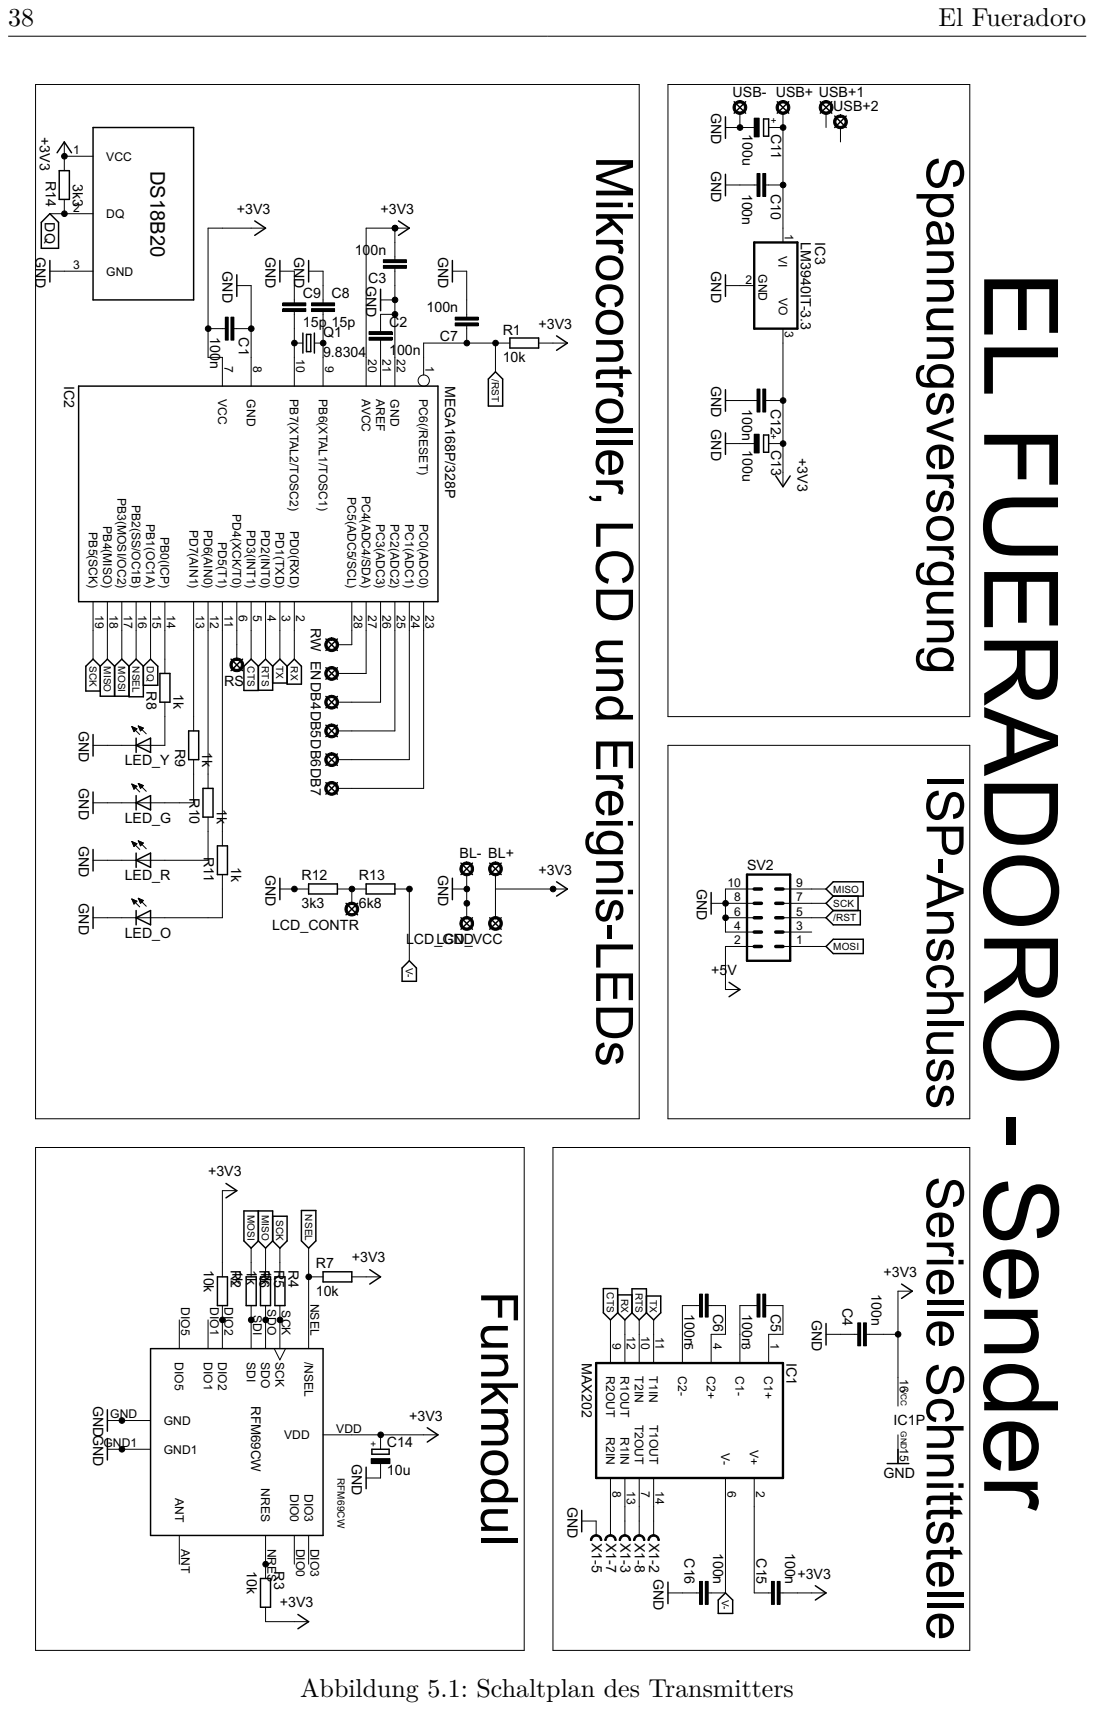
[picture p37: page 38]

Mikrocontroller, LCD und Ereignis-LEDs

Serielle Schnittstelle ISP-Anschluss Spannungsversorgung

PB4(MISO) 18 PB3(MOSI/OC2) 17 PB2(SS/OC1B) 16 PB1(OC1A) 15 PB0(ICP) 14

GND GND

Abbildung 5.1: Schaltplan des Transmitters

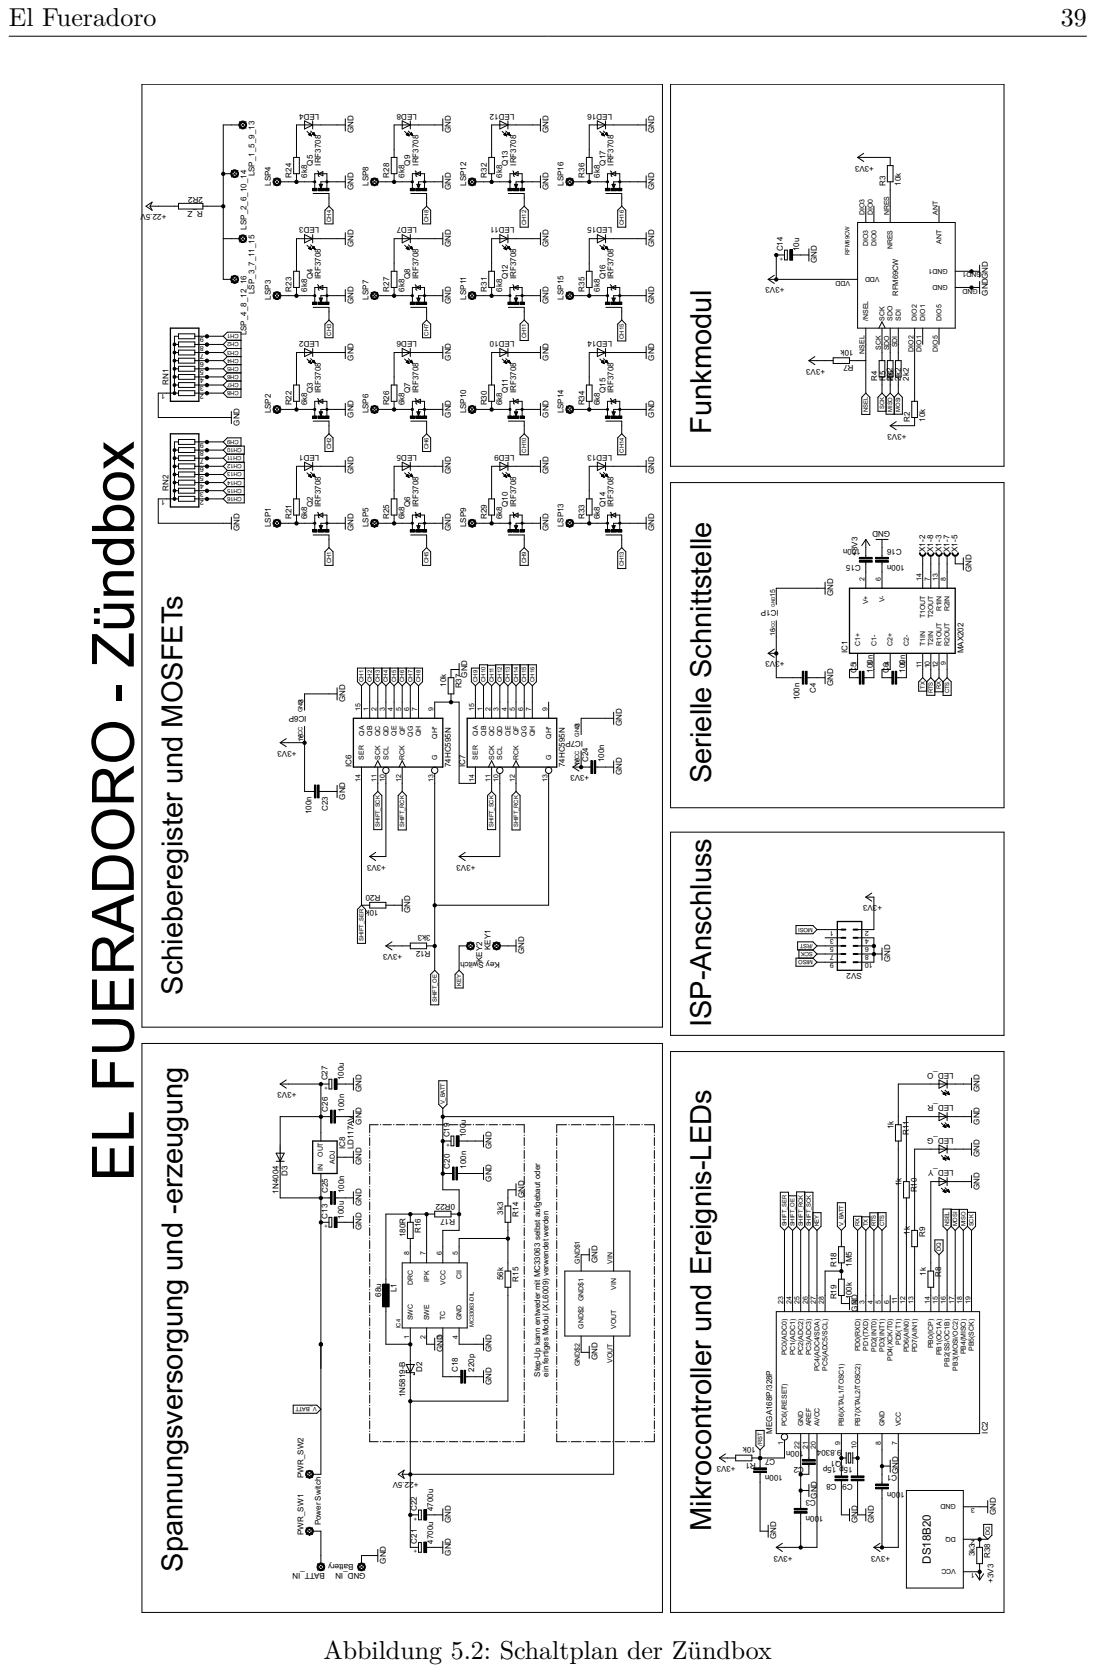
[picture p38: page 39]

GND GND

Funkmodul Serielle Schnittstelle ISP-Anschluss Mikrocontroller und Ereignis-LEDs

Spannungsversorgung und -erzeugung Schieberegister und MOSFETs

GND GND GND GND +3V3

Step-Up kann entweder mit MC33063 selbst aufgebaut oder

ein fertiges Modul (XL6009) verwendet werden

PB4(MISO) 18 PB3(MOSI/OC2) 17 PB2(SS/OC1B) 16 PB1(OC1A) 15 PB0(ICP) 14

Abbildung 5.2: Schaltplan der Zündbox

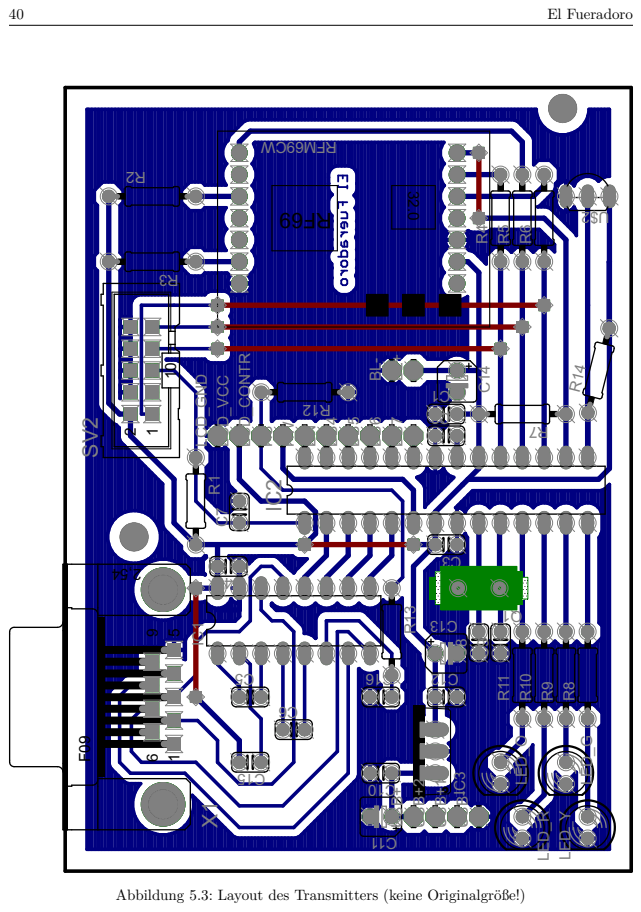
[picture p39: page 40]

Abbildung 5.3: Layout des Transmitters (keine Originalgröße!)

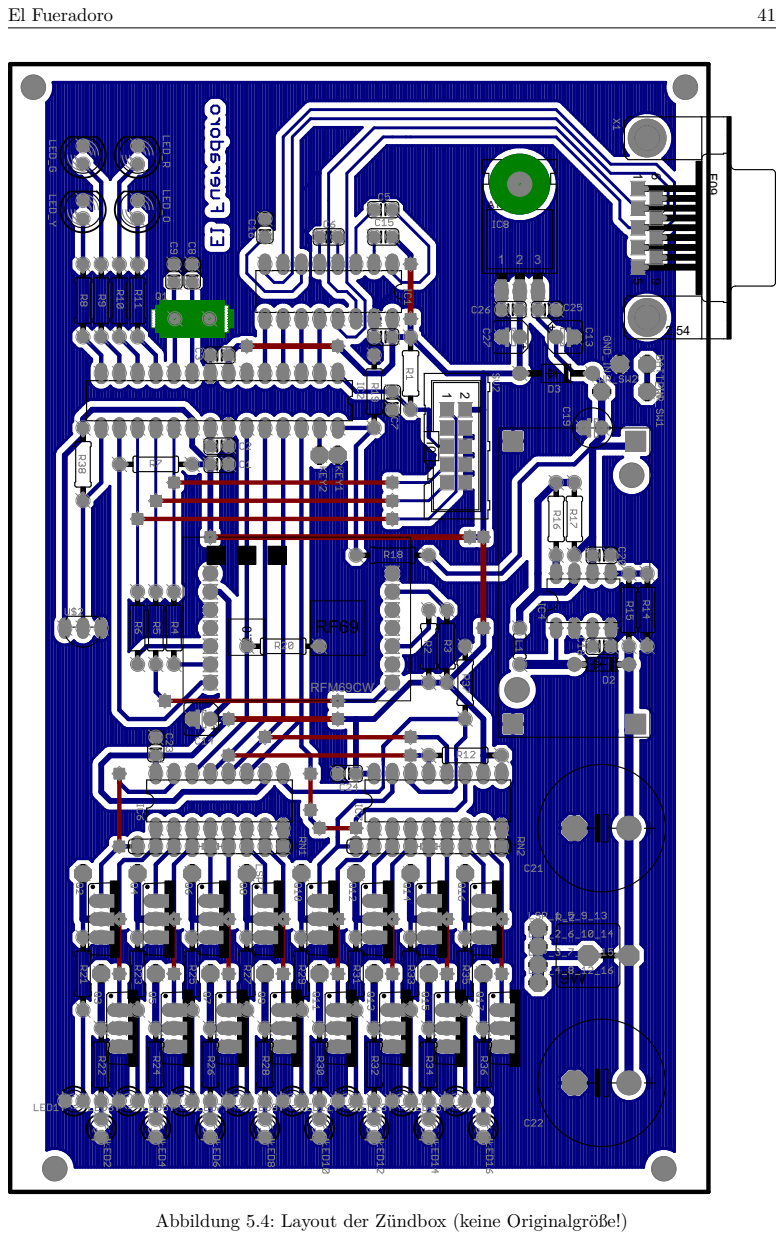
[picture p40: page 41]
El Fueradoro; RFM69CW

Abbildung 5.4: Layout der Zündbox (keine Originalgröße!)

43
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

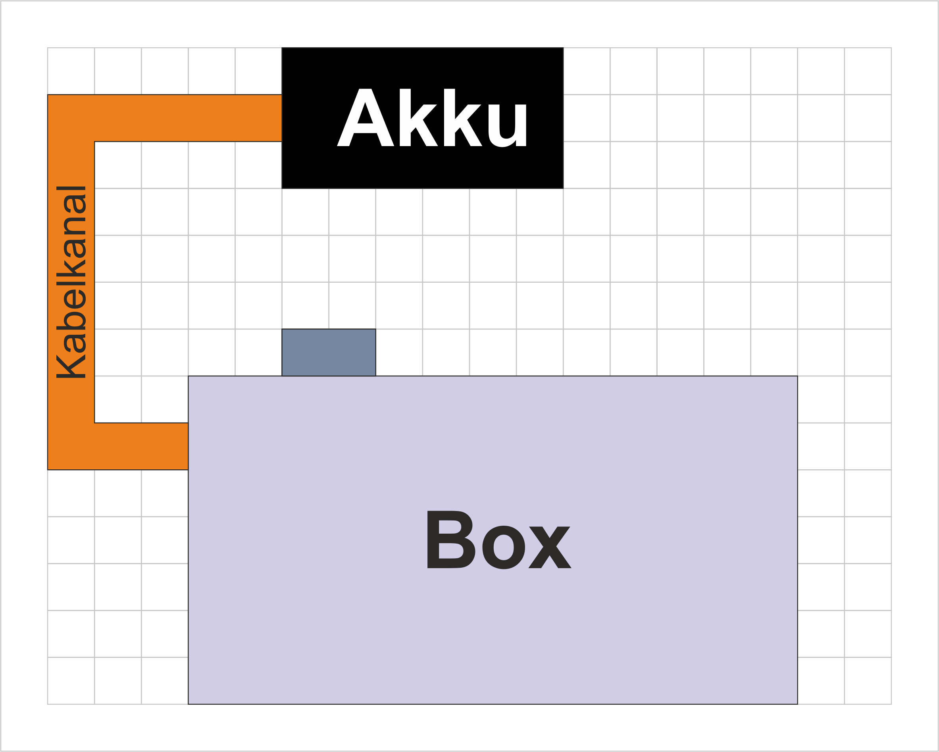
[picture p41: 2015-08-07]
Manual/Bilder/foamcut.png

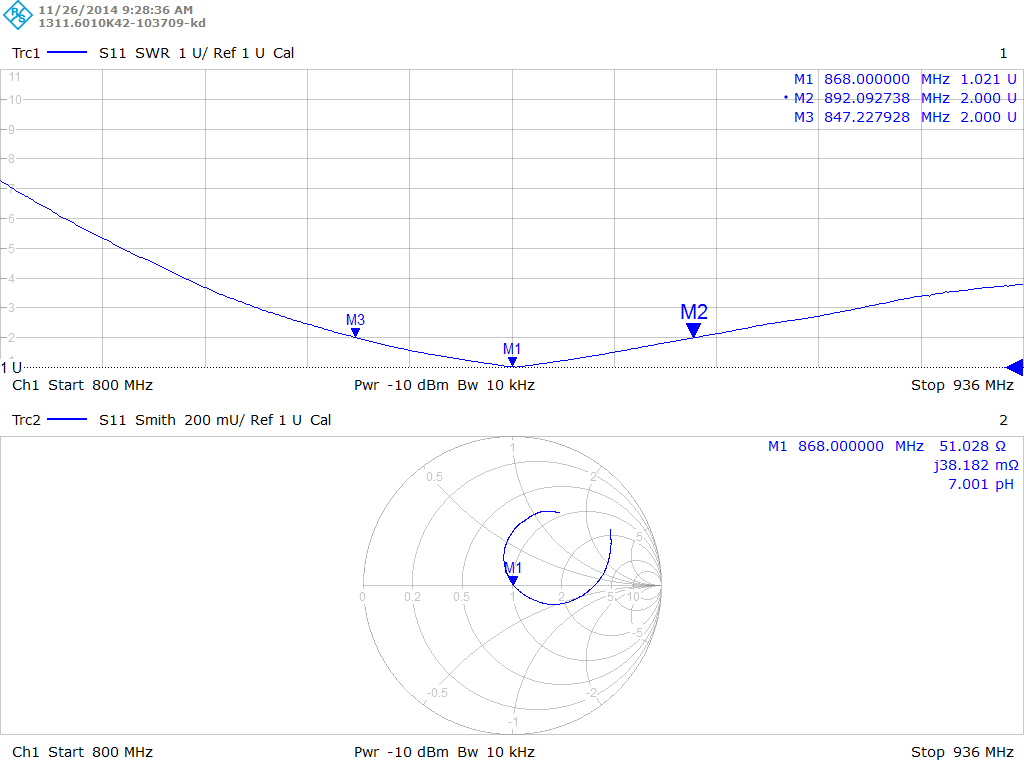
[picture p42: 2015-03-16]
Manual/Bilder/vswrmessung.png

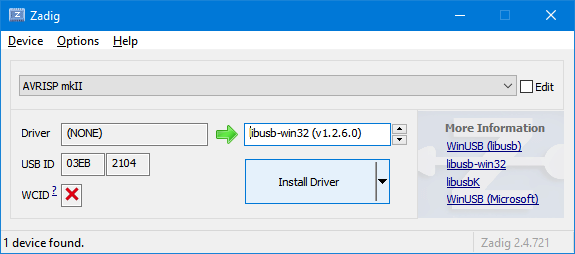
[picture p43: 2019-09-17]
Manual/Bilder/zadig.png

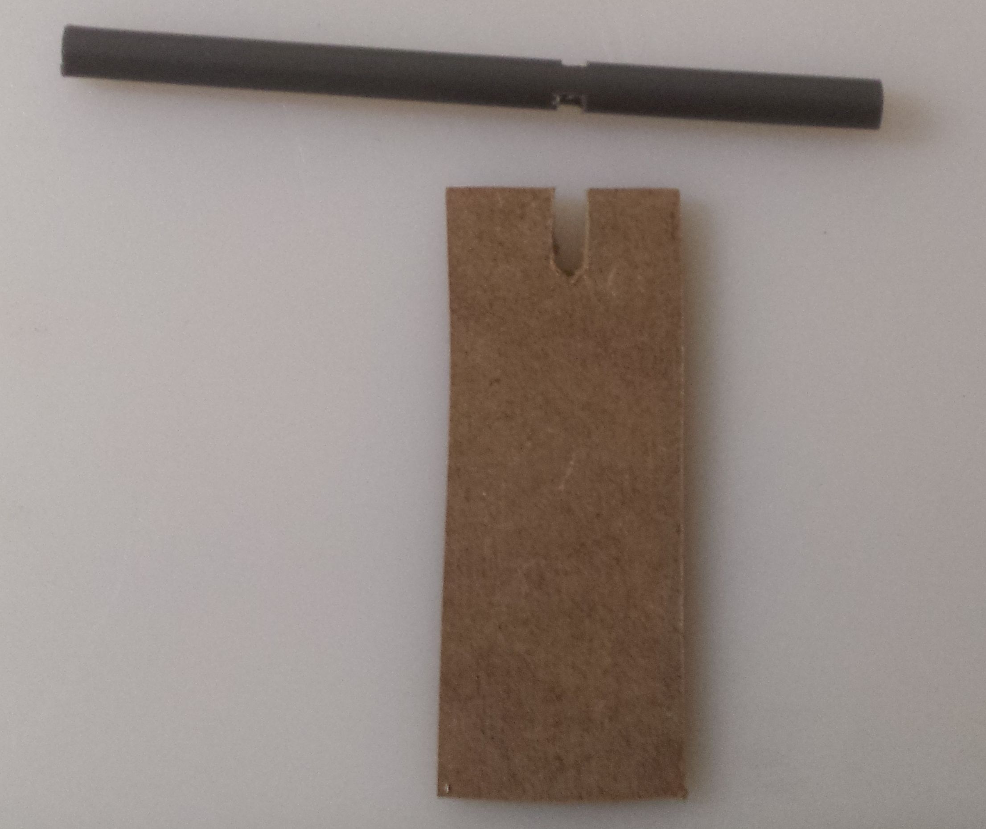
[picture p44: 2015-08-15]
Manual/Bilder/koffer-adapter-einzeln.jpg

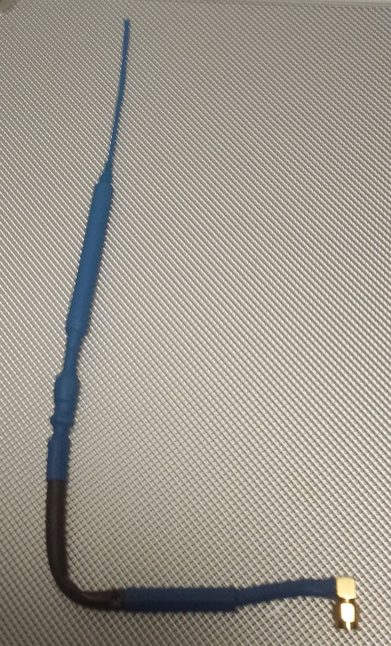
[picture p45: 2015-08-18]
Manual/Bilder/antennefertig.jpg

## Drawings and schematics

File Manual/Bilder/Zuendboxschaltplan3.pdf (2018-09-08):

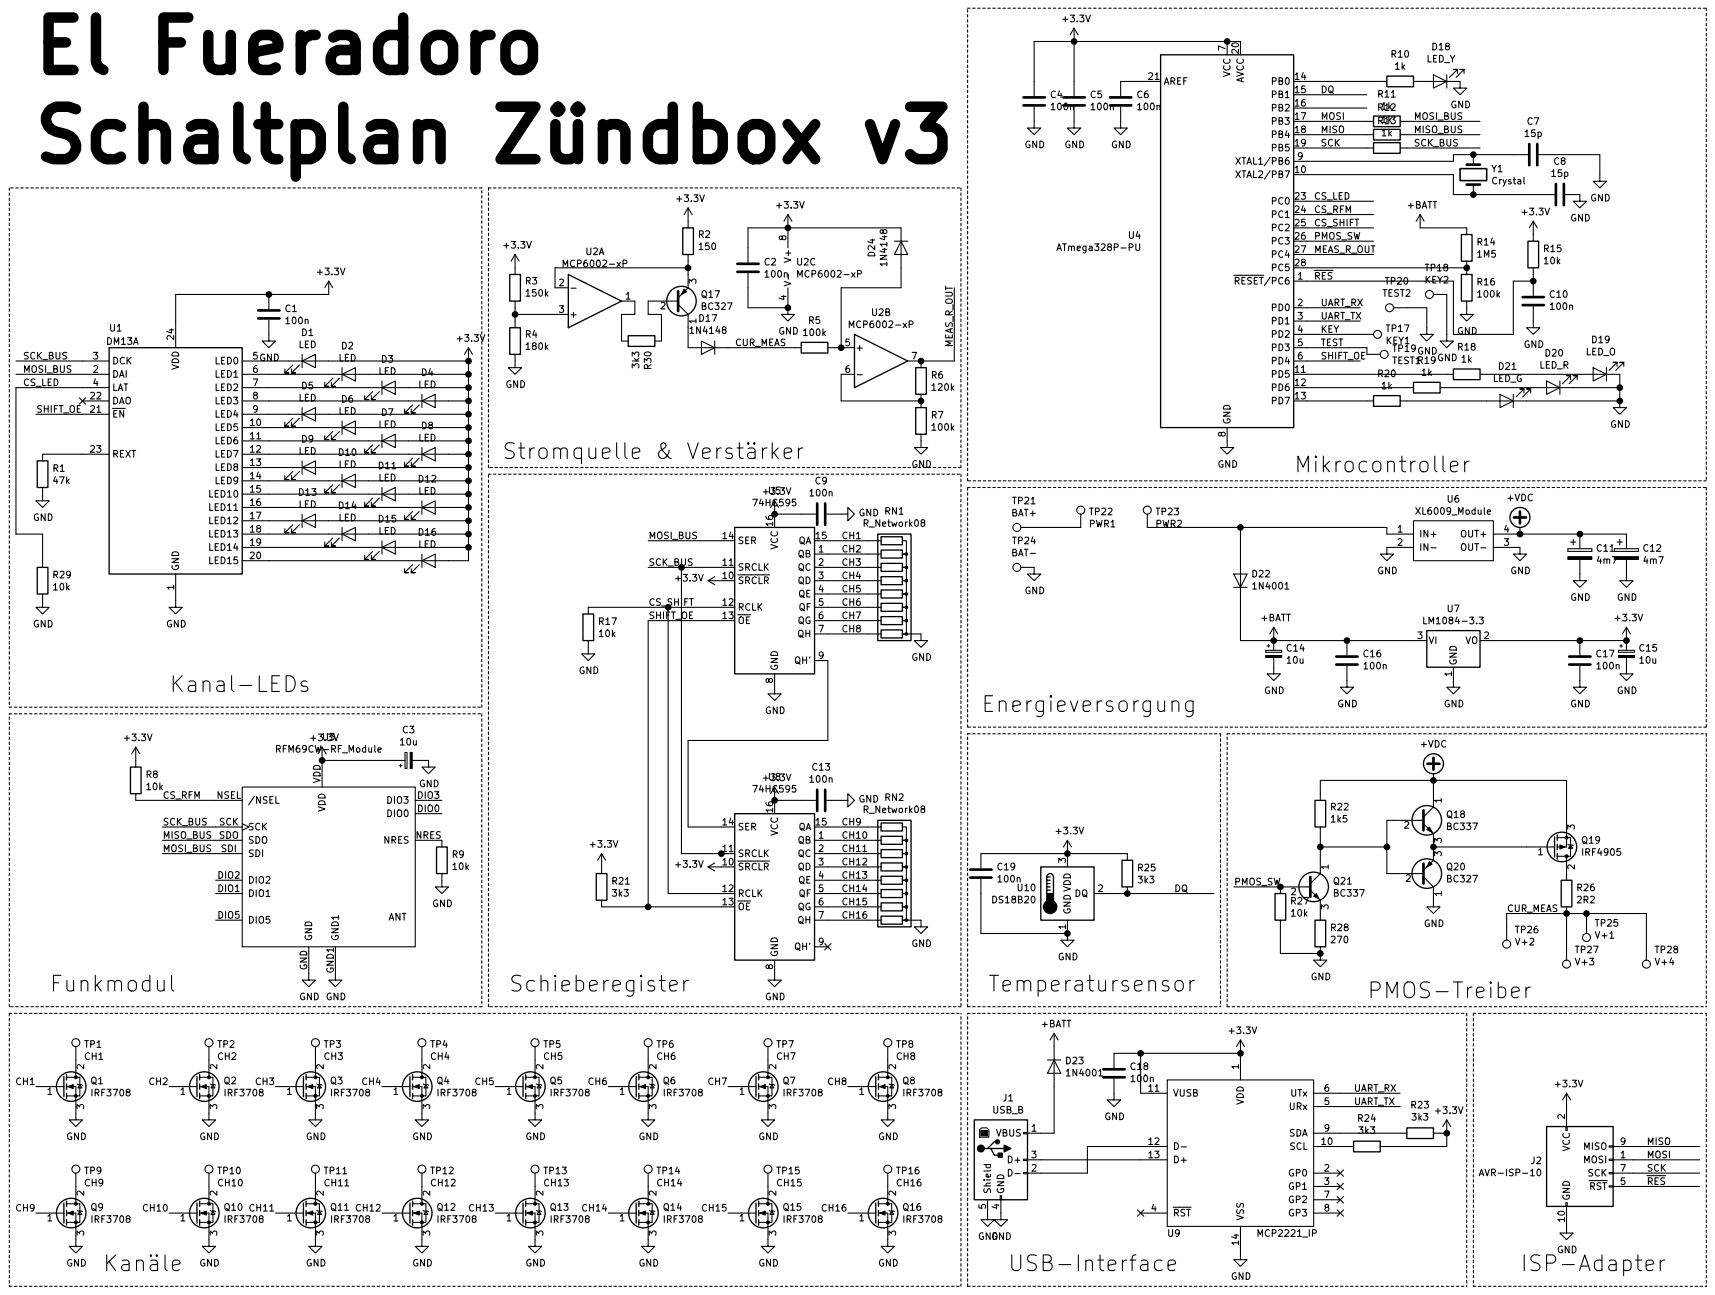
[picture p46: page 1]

1 SCL 10 VUSB 11 D- 12 D+ 13 VSS 14 GP0 2 GP1 3 RST 4 URx 5 UTx 6 GP2 7 GP3 8 SDA 9 U9 MCP2221_IP GND

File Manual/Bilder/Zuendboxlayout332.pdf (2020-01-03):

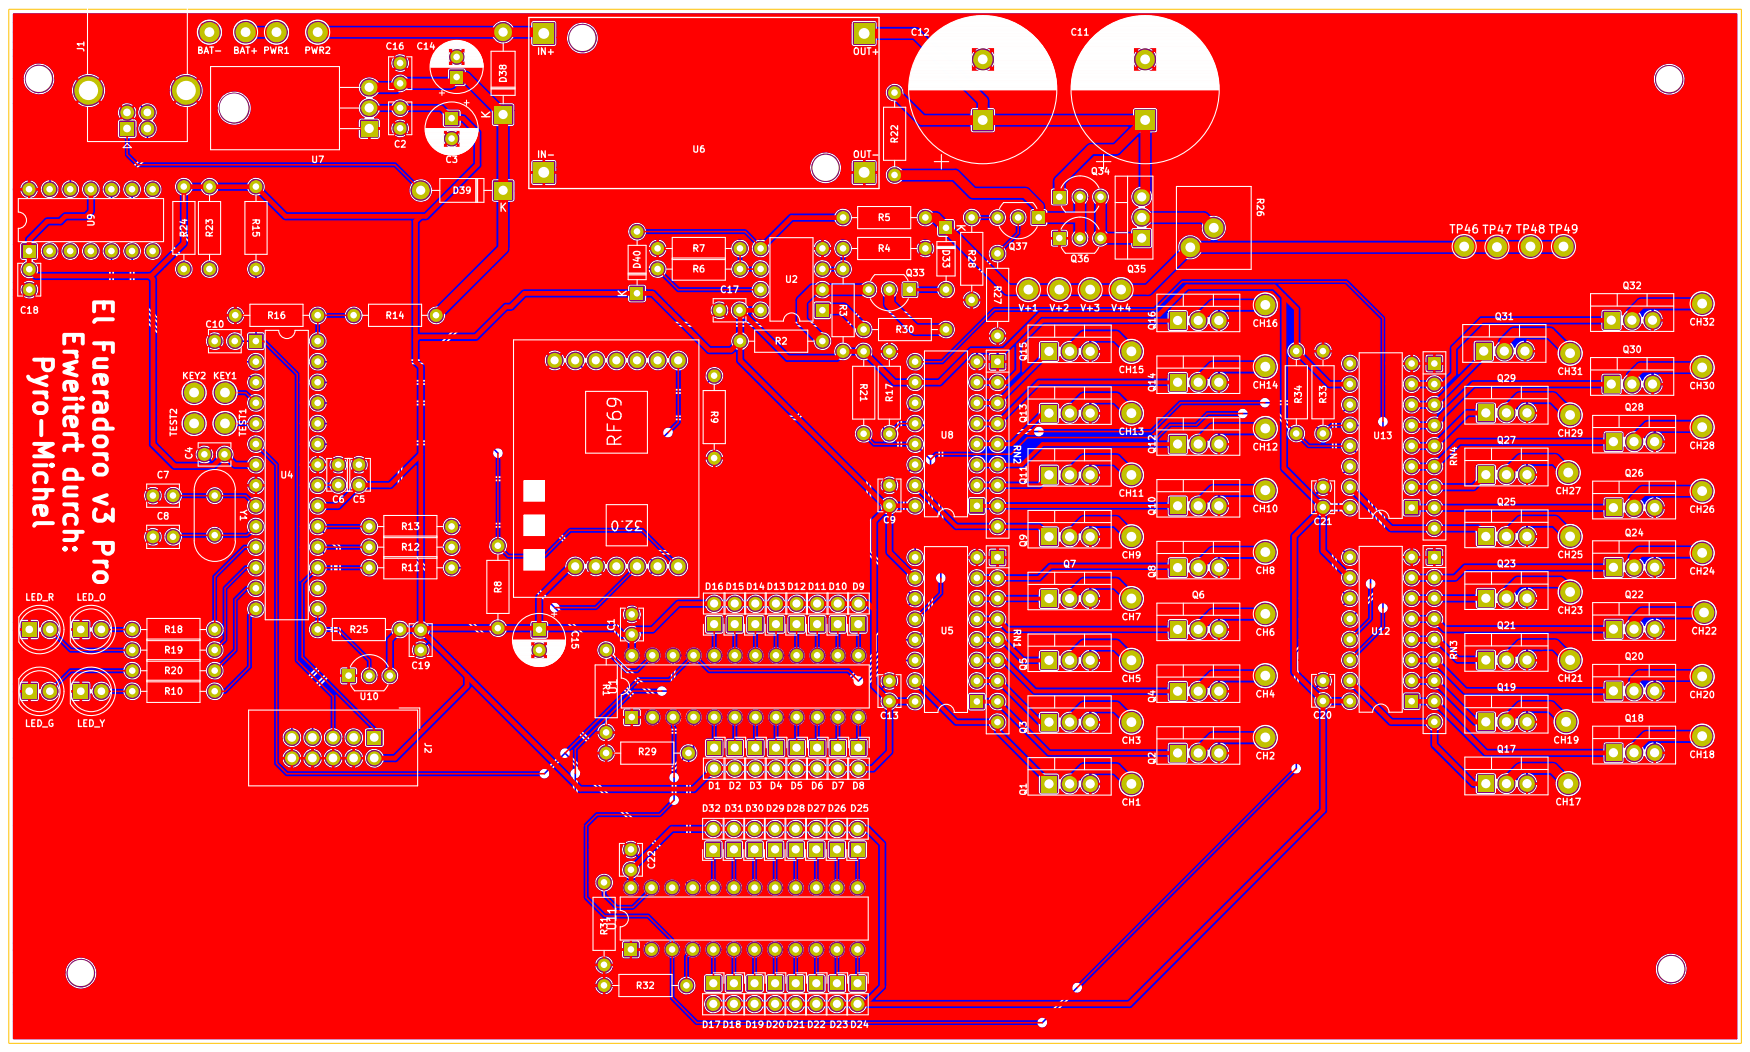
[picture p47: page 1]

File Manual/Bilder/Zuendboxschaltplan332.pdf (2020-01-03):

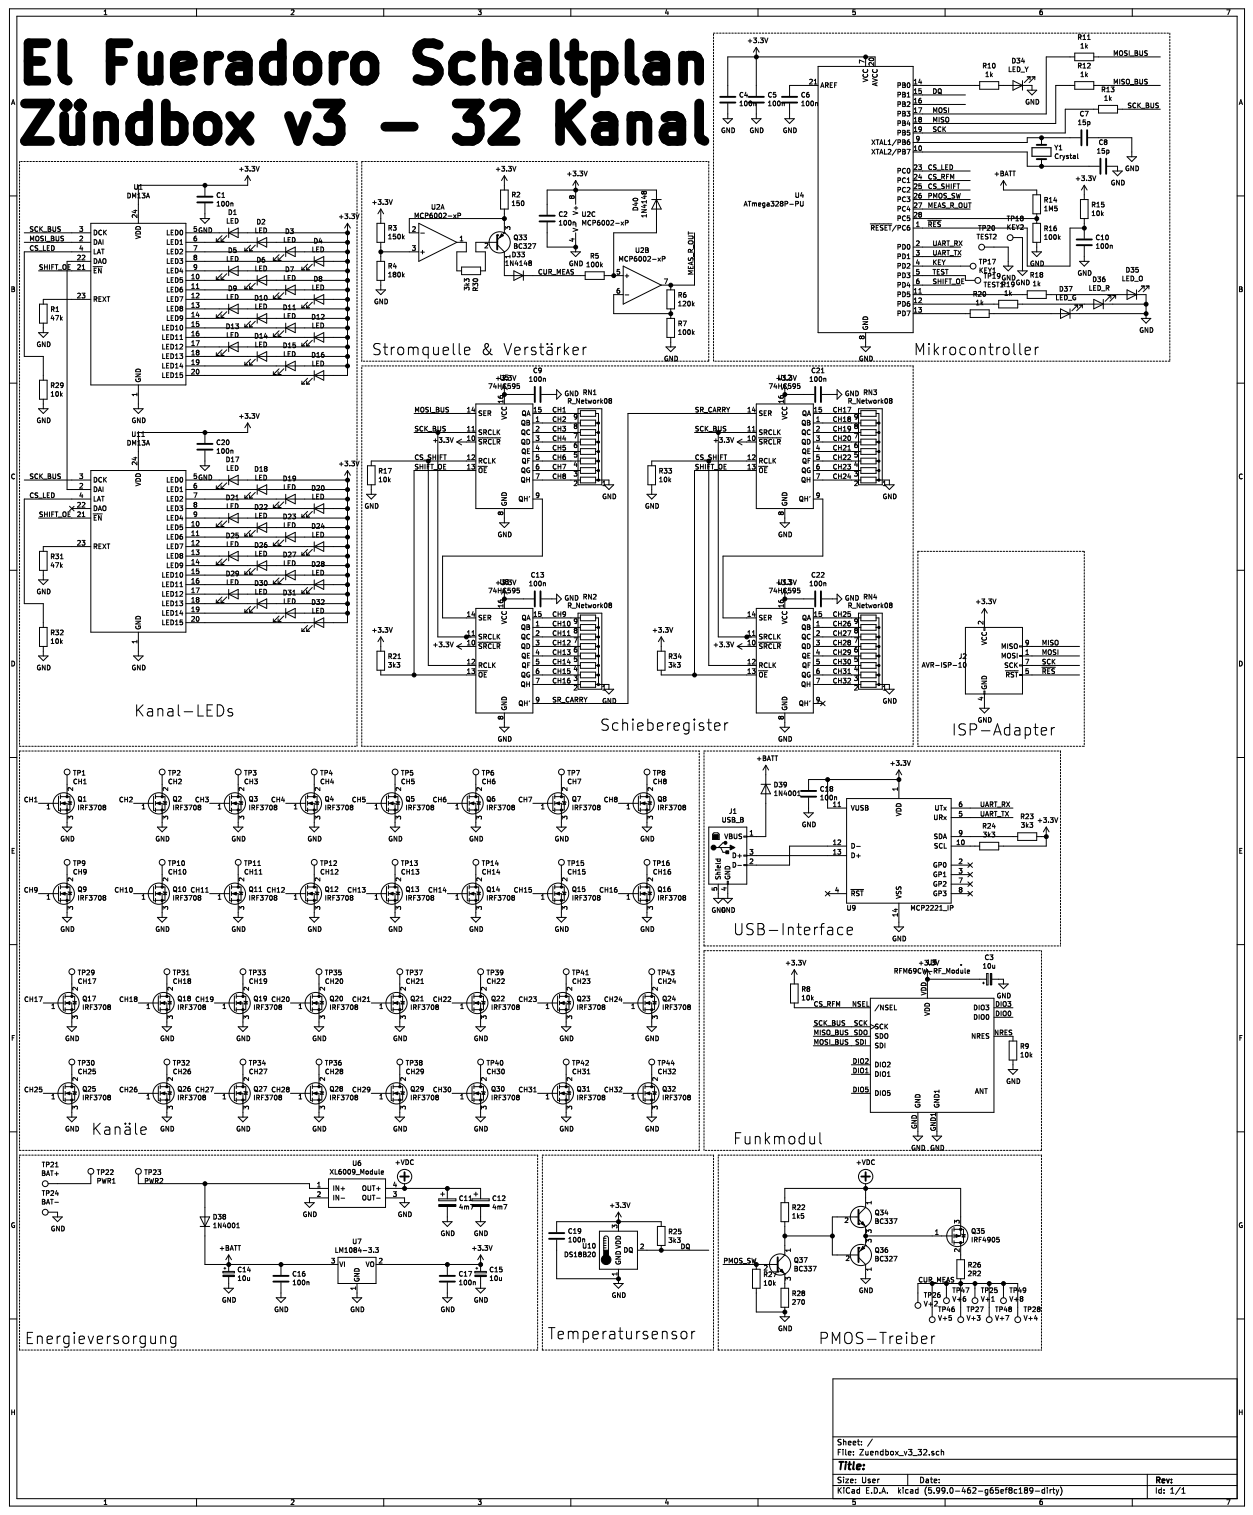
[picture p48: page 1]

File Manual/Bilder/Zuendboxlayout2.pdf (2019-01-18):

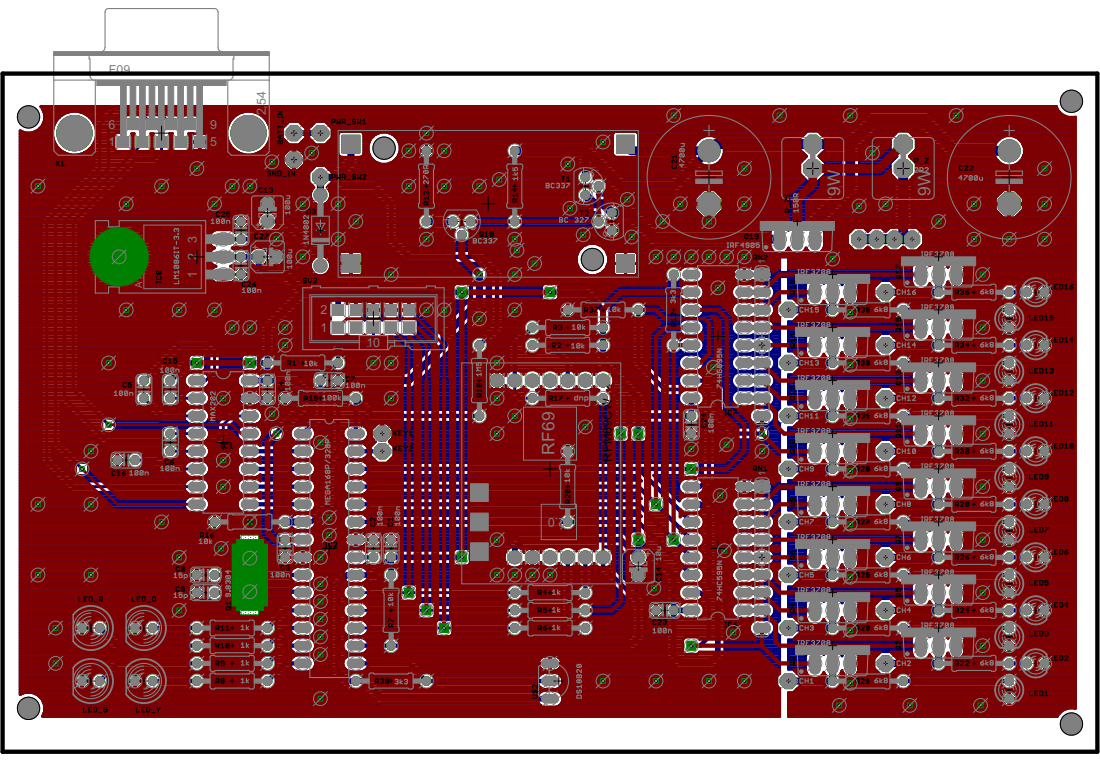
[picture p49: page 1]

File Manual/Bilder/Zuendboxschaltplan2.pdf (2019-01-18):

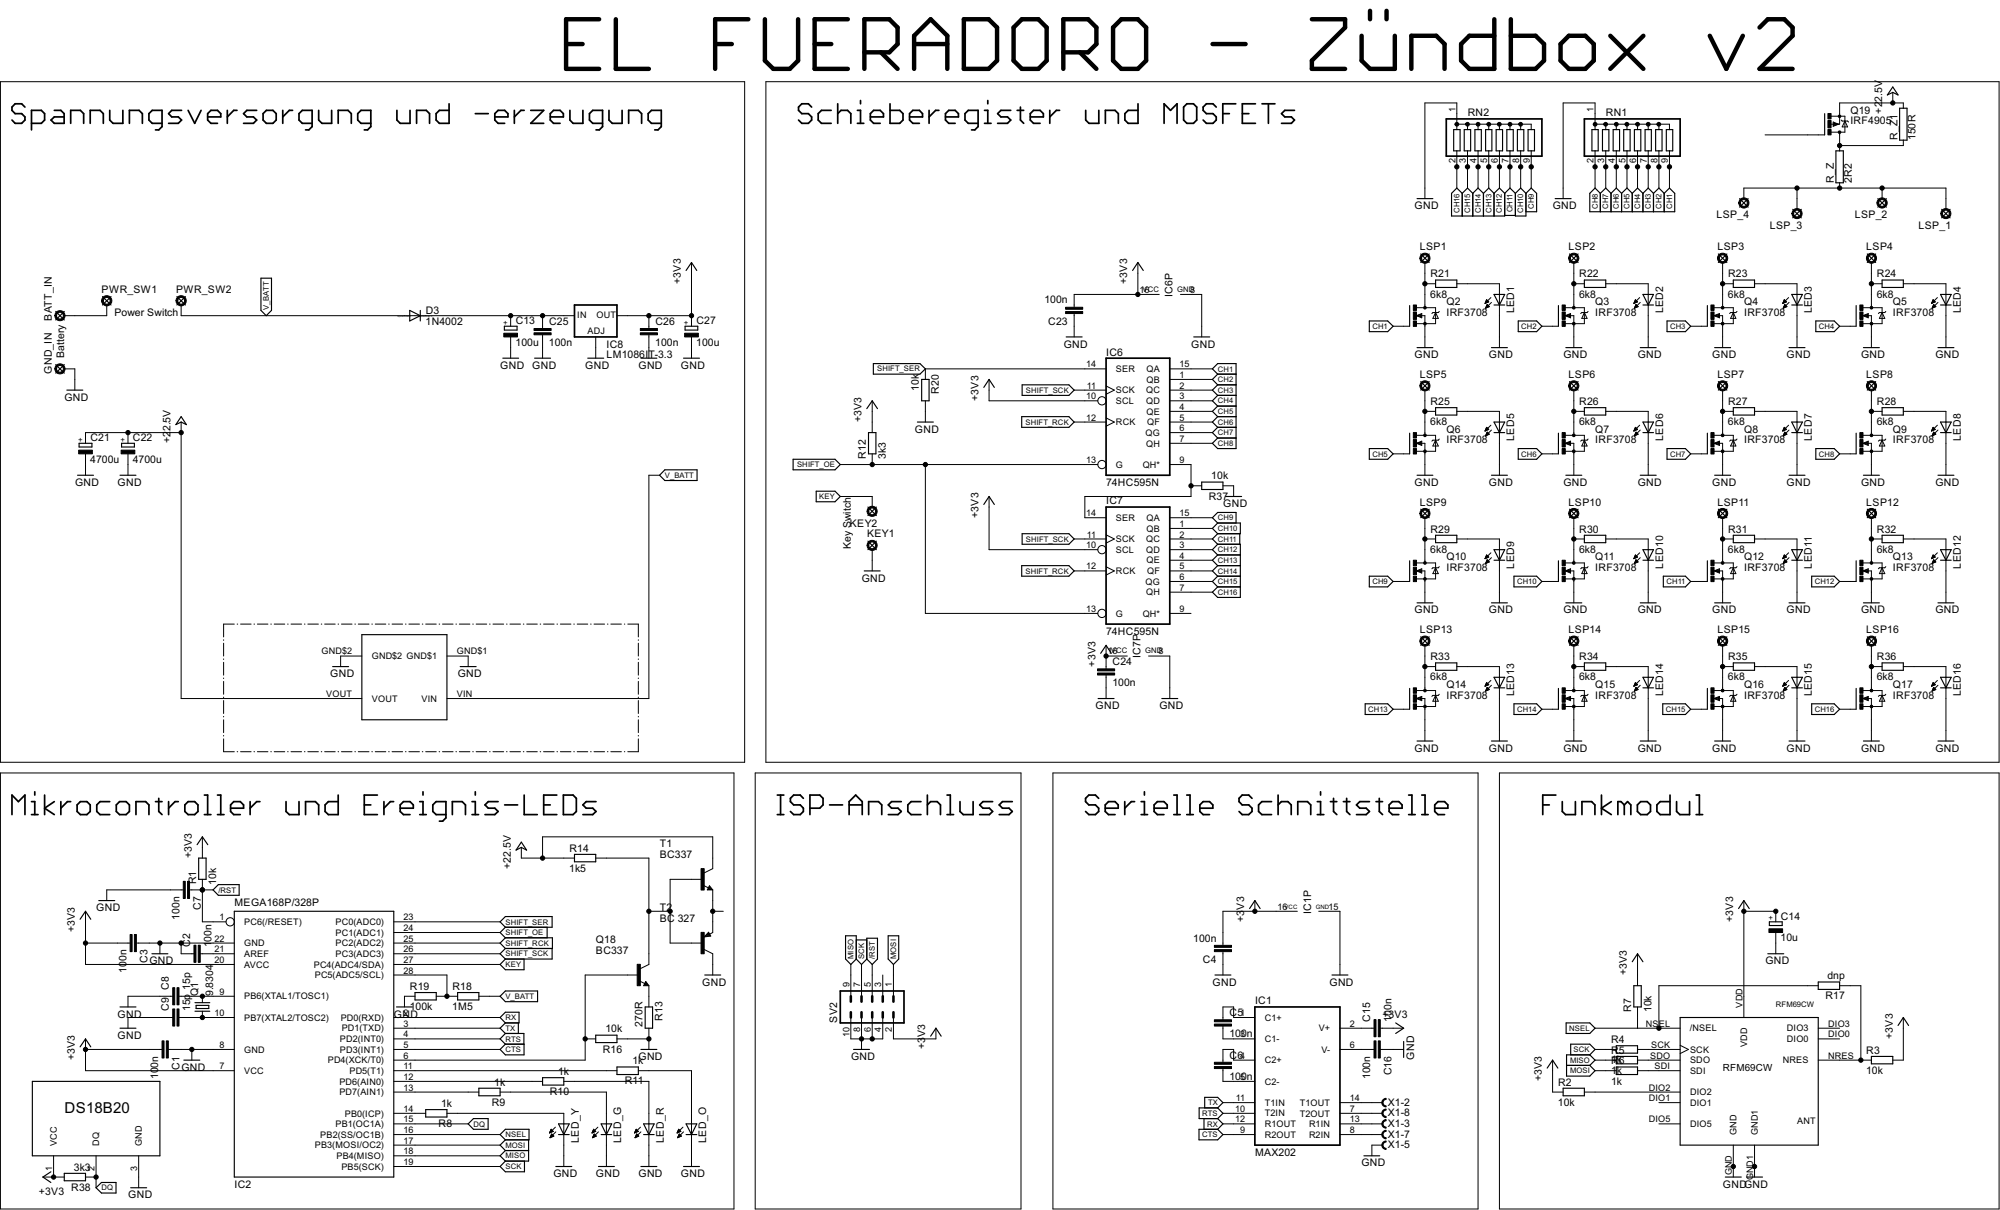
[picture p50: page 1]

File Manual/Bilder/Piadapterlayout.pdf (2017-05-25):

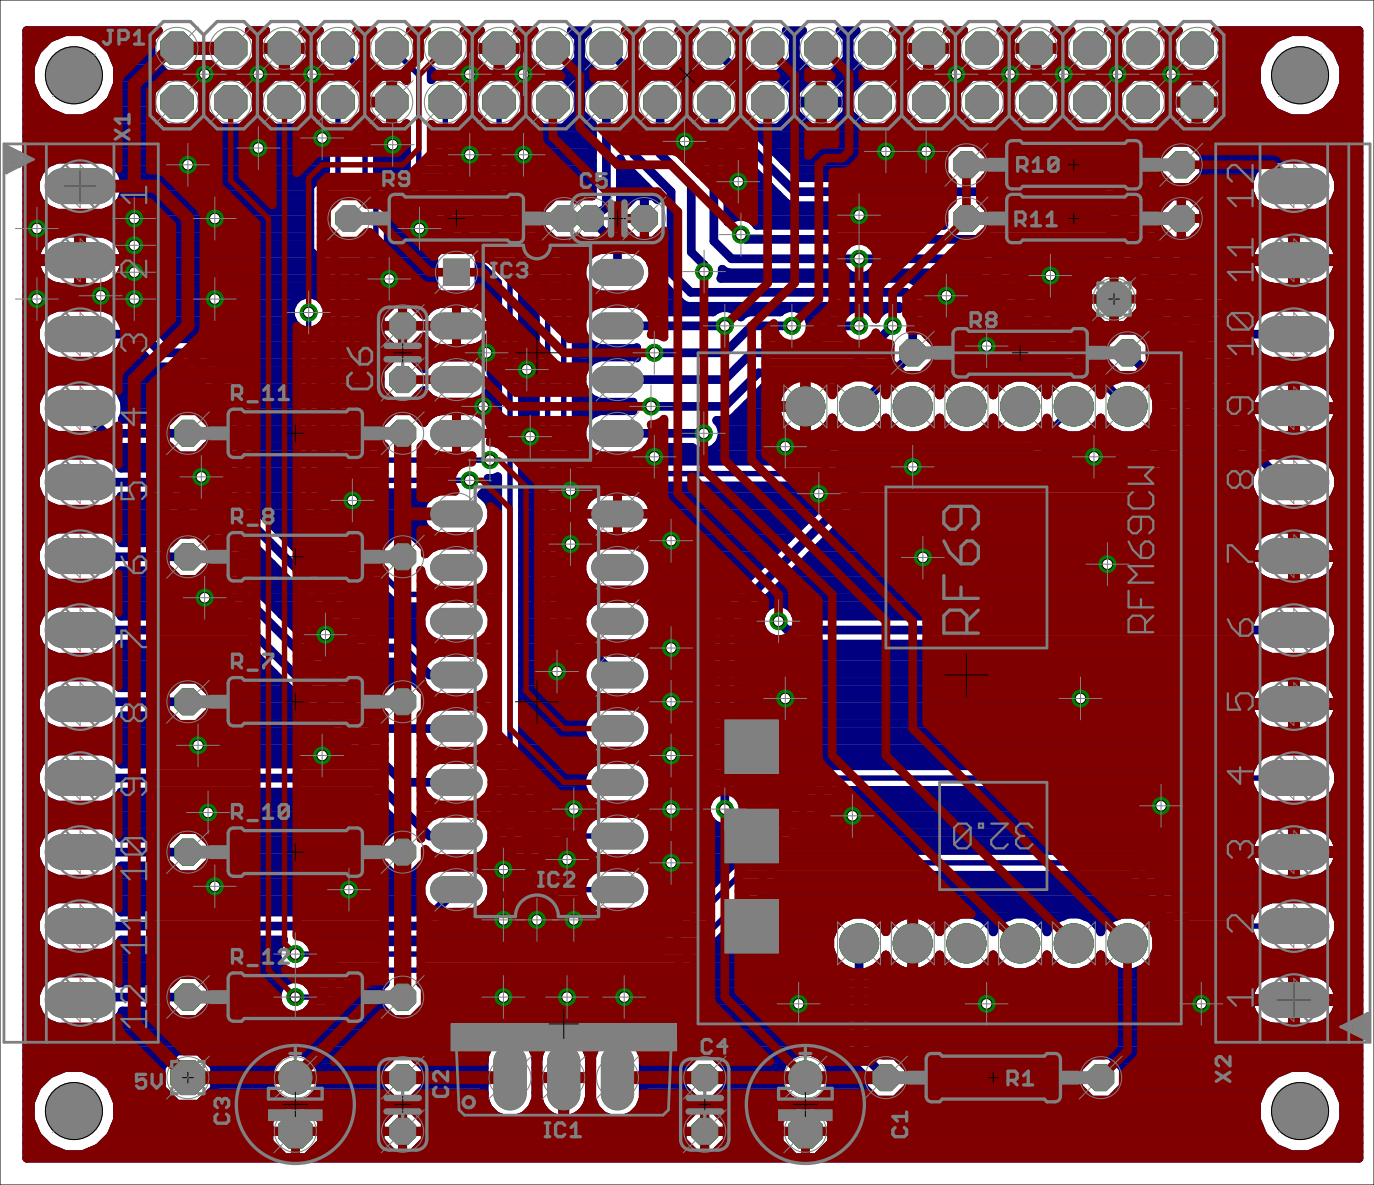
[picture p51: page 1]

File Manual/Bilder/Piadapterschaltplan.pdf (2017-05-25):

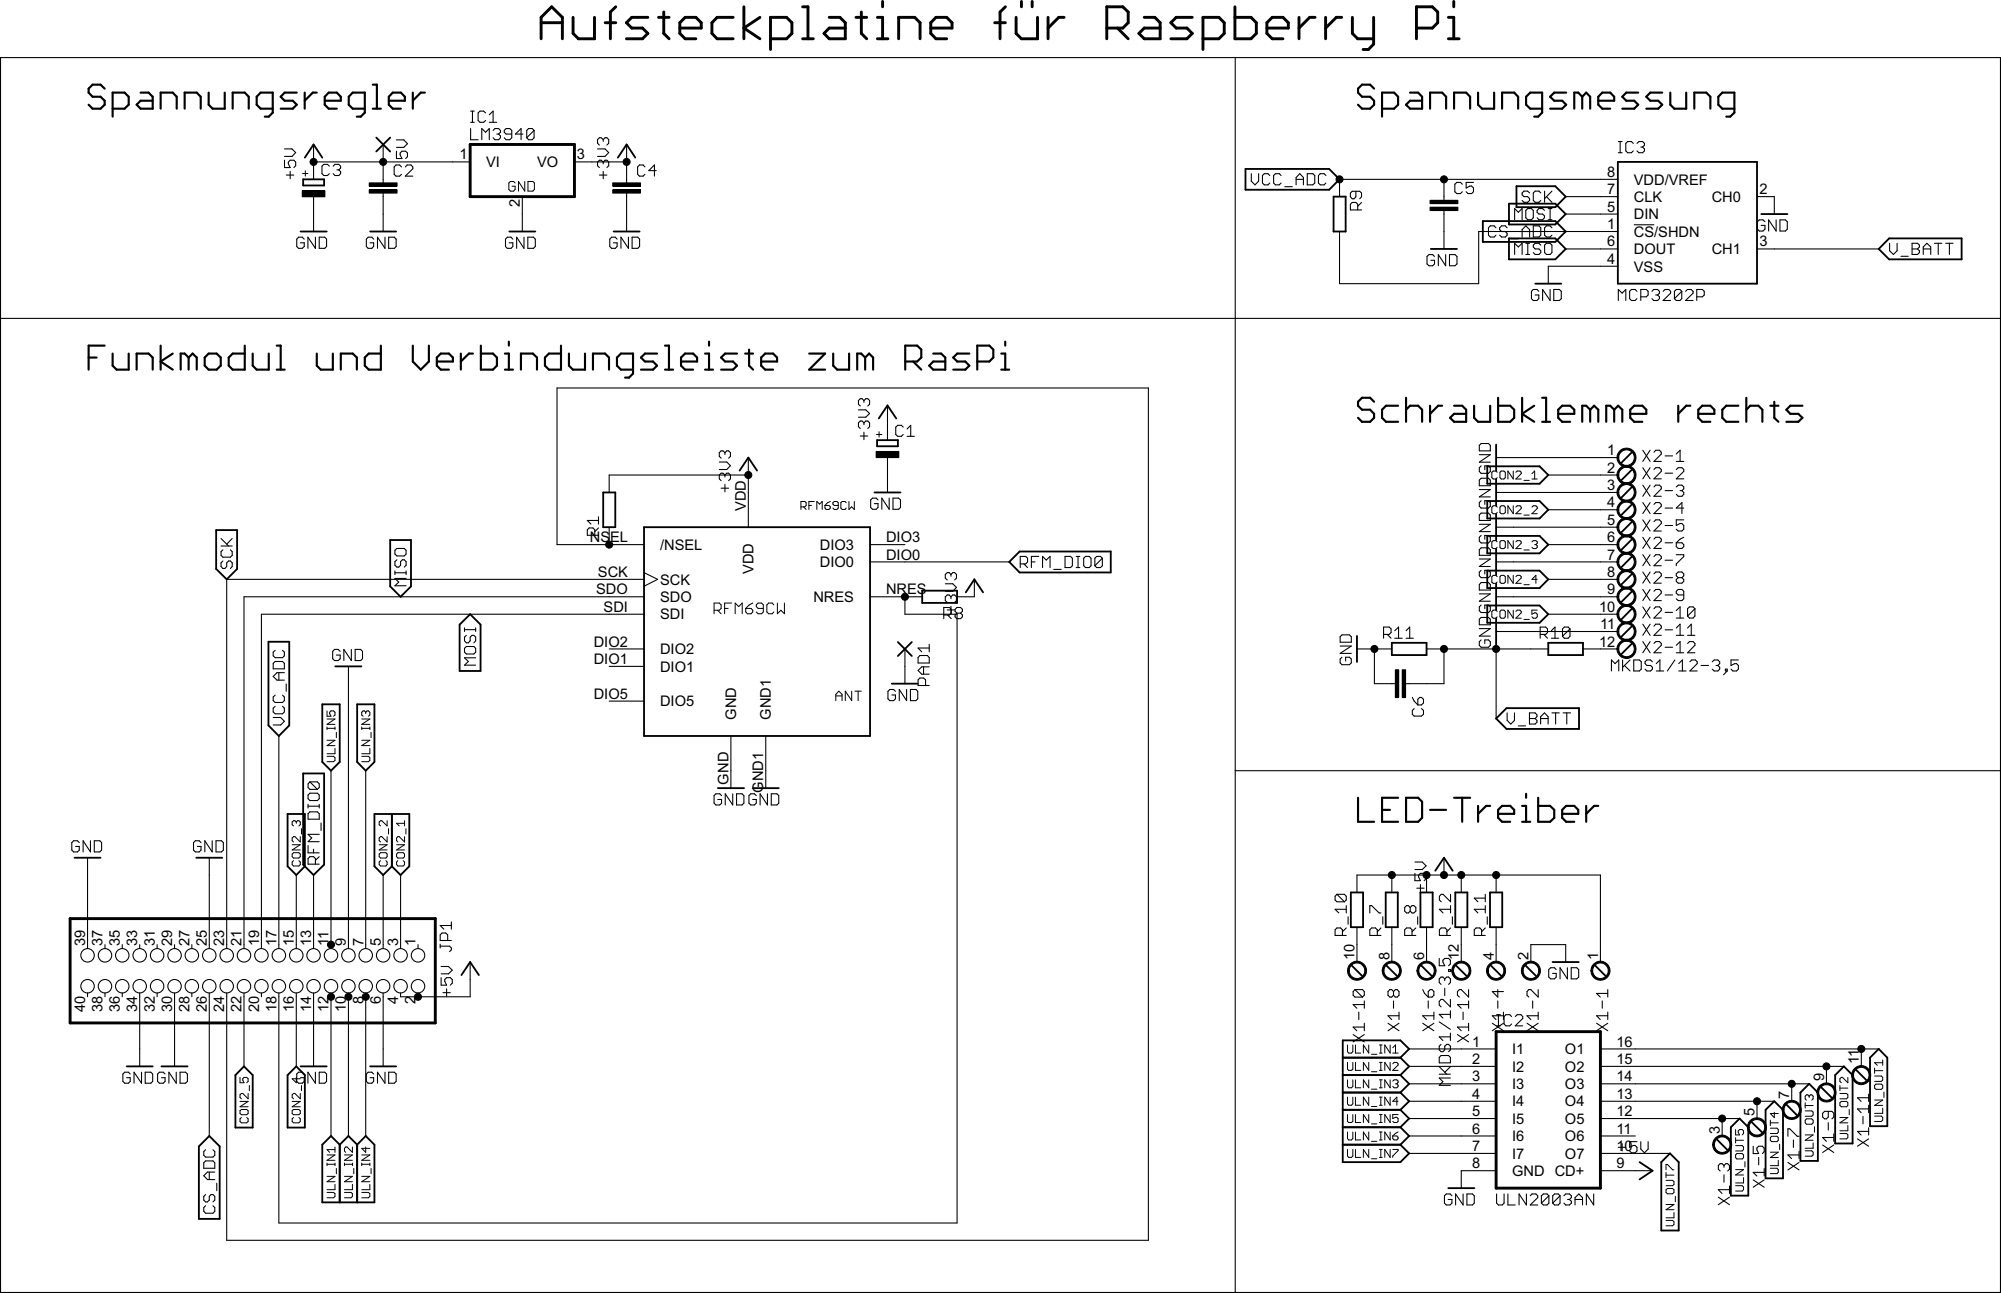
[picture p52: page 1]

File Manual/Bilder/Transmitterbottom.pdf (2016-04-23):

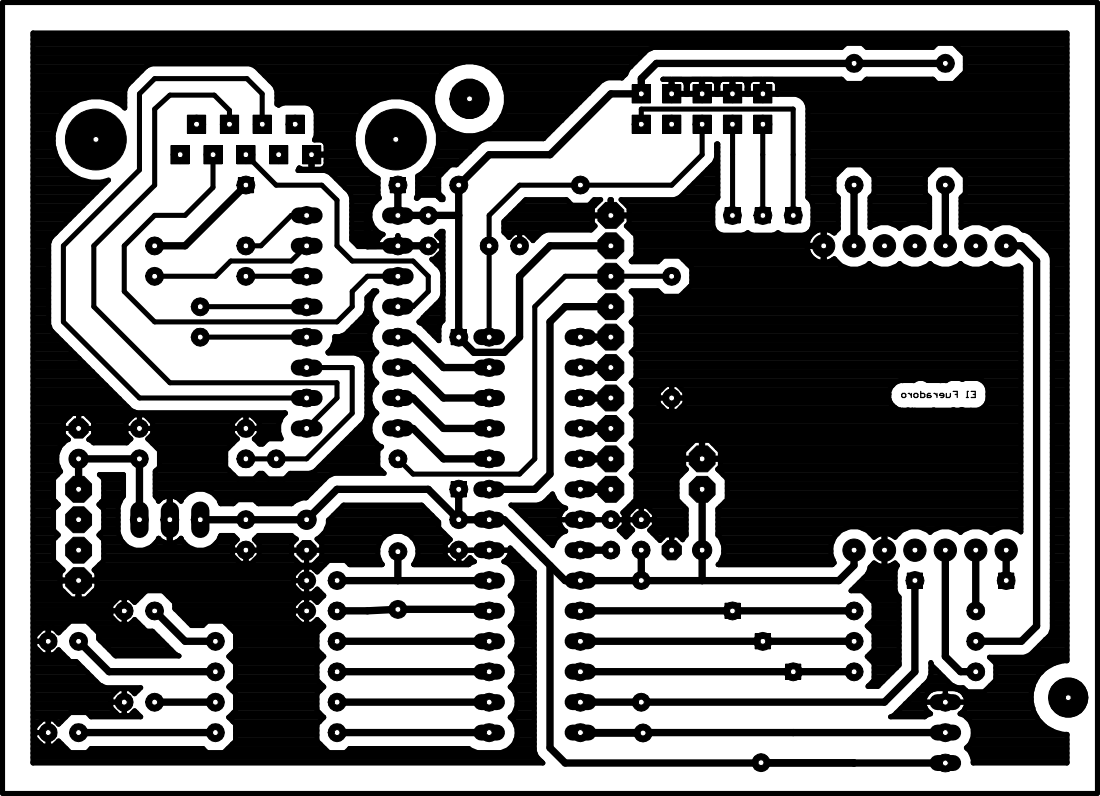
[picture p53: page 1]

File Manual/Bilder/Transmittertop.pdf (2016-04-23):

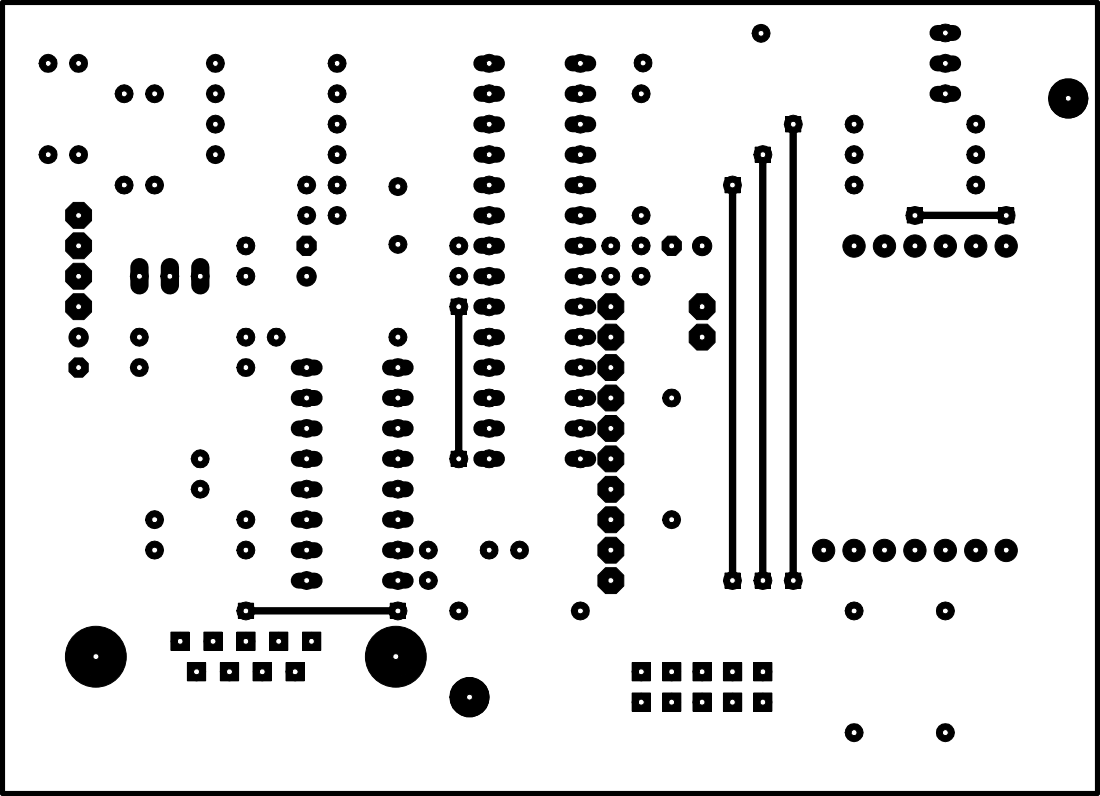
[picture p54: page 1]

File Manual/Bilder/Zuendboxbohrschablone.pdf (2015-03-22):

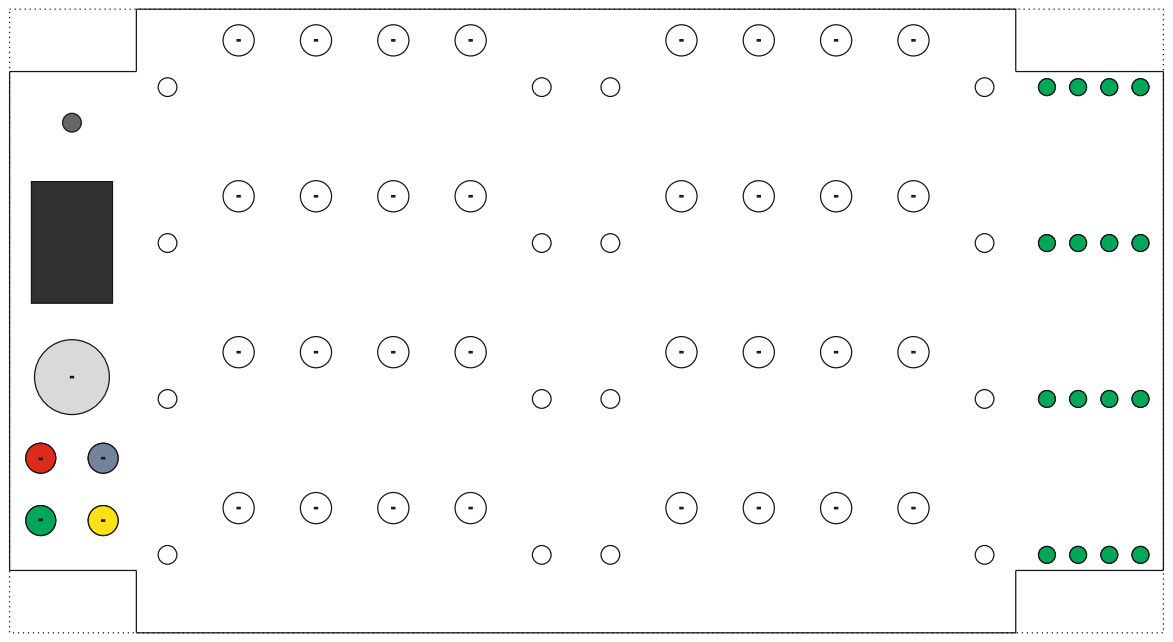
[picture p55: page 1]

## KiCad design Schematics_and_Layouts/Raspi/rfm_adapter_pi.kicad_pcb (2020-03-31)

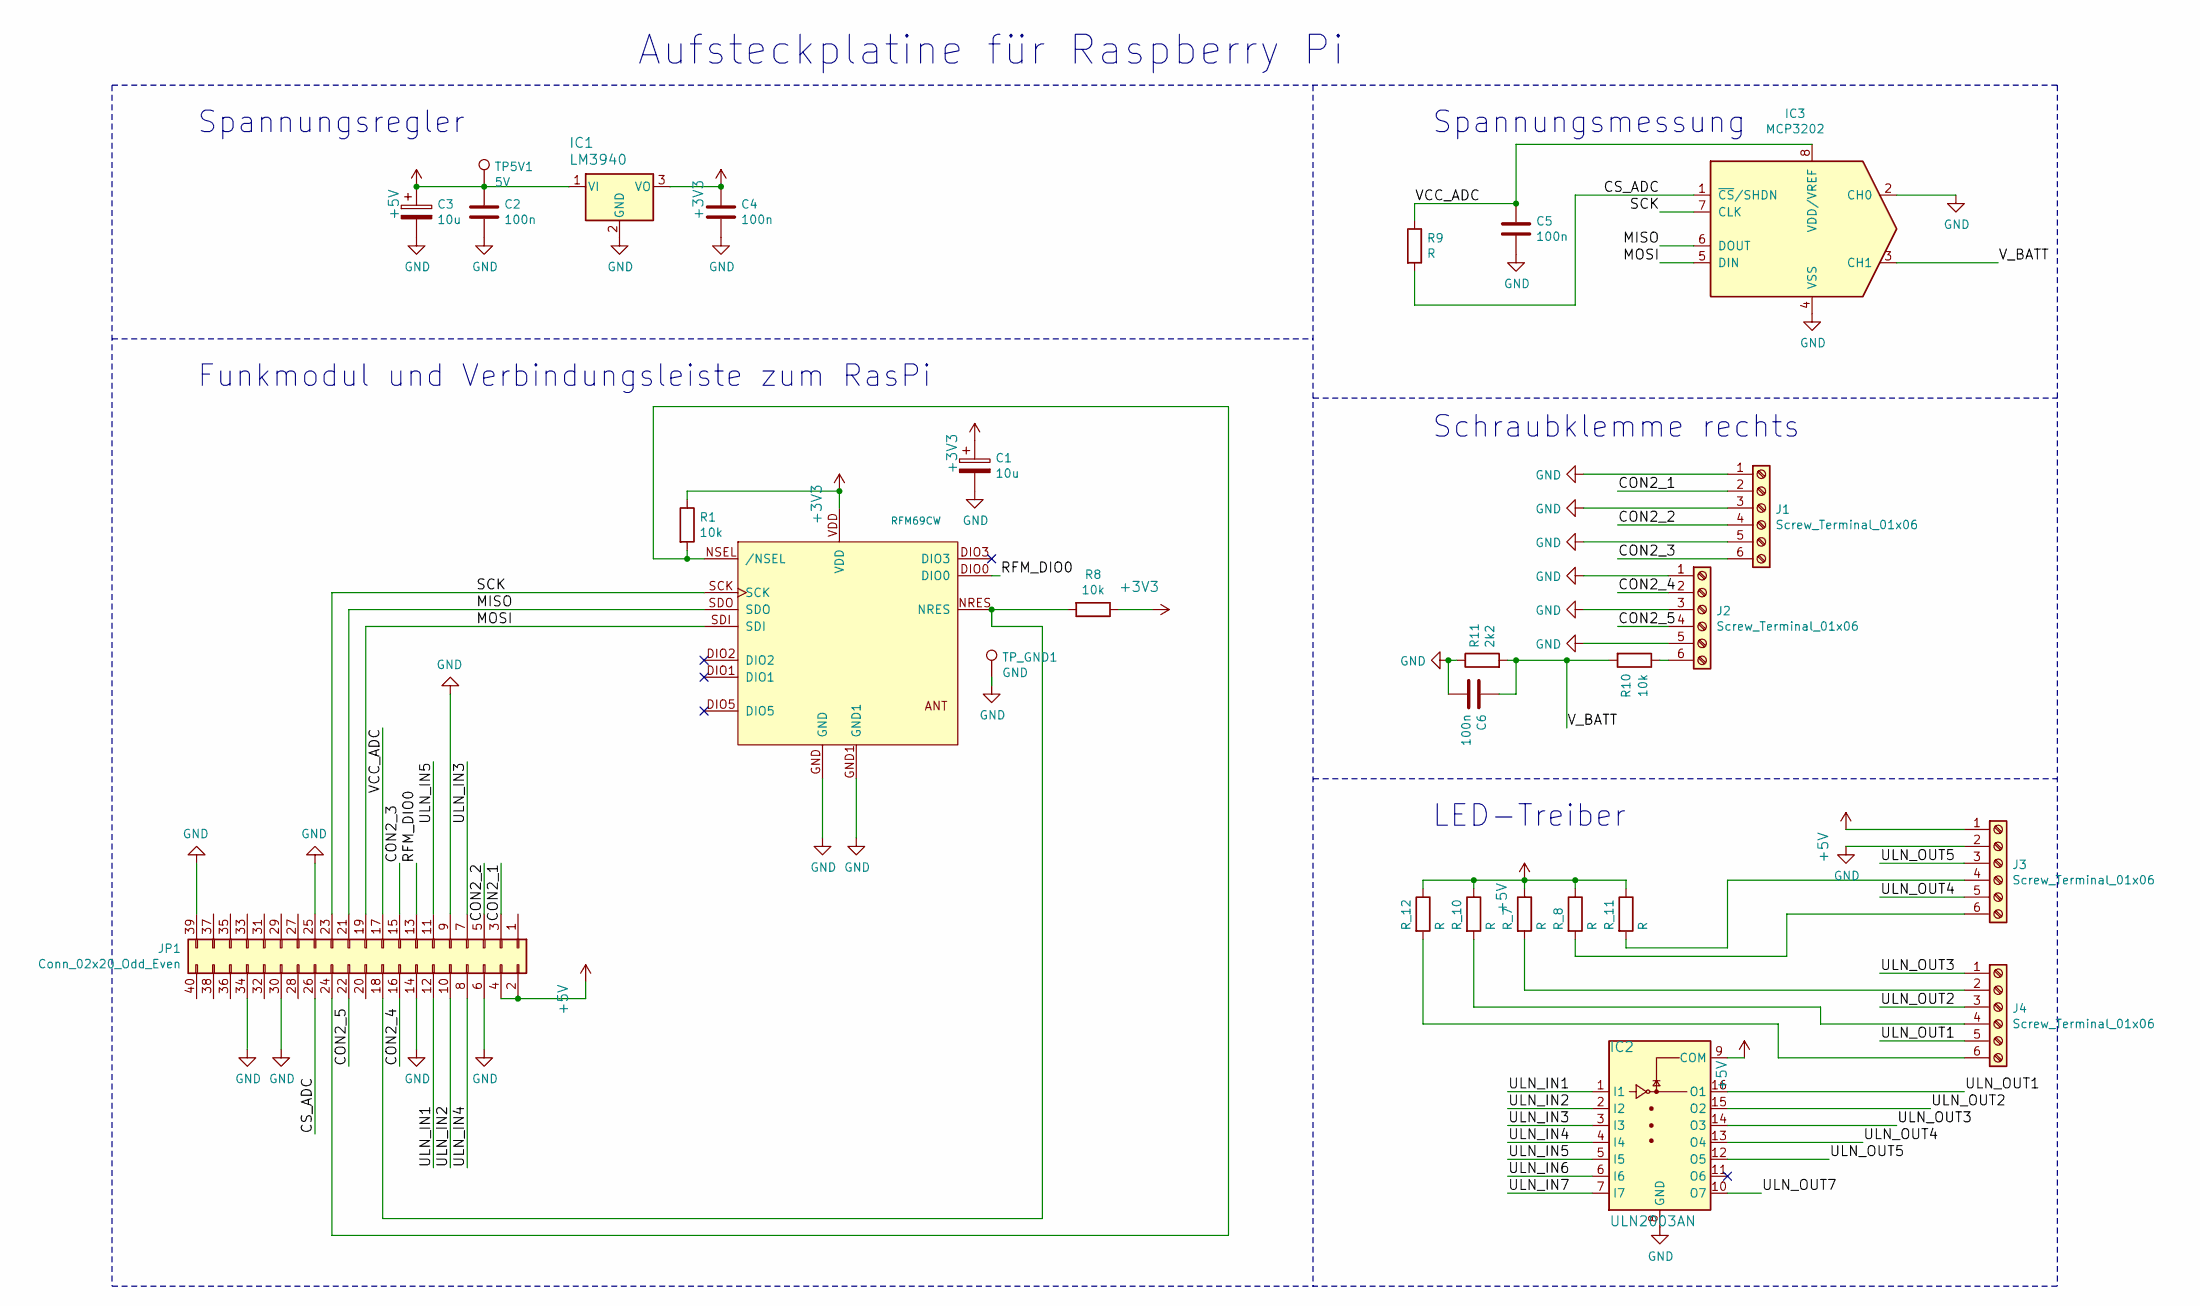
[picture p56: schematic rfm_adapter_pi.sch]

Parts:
C1, C3: 10u; CP_Radial_D5.0mm_P2.50mm
C2, C4, C5, C6: 100n; C_Disc_D5.0mm_W2.5mm_P2.50mm
IC1: LM3940; TO-220-3_Vertical
IC2: ULN2003AN; DIP-16_W7.62mm
IC3: MCP3202; DIP-8_W7.62mm
J1, J2, J3, J4: Screw_Terminal_01x06; TerminalBlock_MetzConnect_Type059_RT06306HBWC_1x06_P3.50mm
JP1: Conn_02x20_Odd_Even; PinSocket_2x20_P2.54mm_Vertical
R1, R8, R10: 10k; R_Axial_DIN0207_L6.3mm_D2.5mm_P10.16mm_Horizontal
R9: R; R_Axial_DIN0207_L6.3mm_D2.5mm_P10.16mm_Horizontal
R11: 2k2; R_Axial_DIN0207_L6.3mm_D2.5mm_P10.16mm_Horizontal
R_7, R_8, R_10, R_11, R_12: R; R_Axial_DIN0207_L6.3mm_D2.5mm_P10.16mm_Horizontal
TP5V1: 5V; TestPoint_THTPad_D1.5mm_Drill0.7mm
TP_GND1: GND; TestPoint_THTPad_D1.5mm_Drill0.7mm
U$1: RFM69CW

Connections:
+3V3: C1.1, C4.1, IC1.3 (VO), R1.1, R8.1, U$1.VDD
+5V: C2.1, C3.1, IC1.1 (VI), IC2.9 (COM), J3.1, JP1.2, JP1.4, R_7.1, R_8.1, R_10.1, R_11.1, R_12.1, TP5V1.1
/CON2_1: J1.2, JP1.3
/CON2_2: J1.4, JP1.5
/CON2_3: J1.6, JP1.15
/CON2_4: J2.2, JP1.16
/CON2_5: J2.4, JP1.22
/CS_ADC: IC3.1 (~CS~/SHDN), JP1.26, R9.2
/MISO: IC3.6 (DOUT), JP1.21, U$1.SDO
/MOSI: IC3.5 (DIN), JP1.19, U$1.SDI
/RFM_DIO0: JP1.13, U$1.DIO0
/SCK: IC3.7 (CLK), JP1.23, U$1.SCK
/ULN_IN1: IC2.1 (I1), JP1.12
/ULN_IN2: IC2.2 (I2), JP1.10
/ULN_IN3: IC2.3 (I3), JP1.7
/ULN_IN4: IC2.4 (I4), JP1.8
/ULN_IN5: IC2.5 (I5), JP1.11
/ULN_IN6: IC2.6 (I6)
/ULN_IN7: IC2.7 (I7)
/ULN_OUT1: IC2.16 (O1), J4.5
/ULN_OUT2: IC2.15 (O2), J4.3
/ULN_OUT3: IC2.14 (O3), J4.1
/ULN_OUT4: IC2.13 (O4), J3.5
/ULN_OUT5: IC2.12 (O5), J3.3
/ULN_OUT7: IC2.10 (O7)
/VCC_ADC: C5.1, IC3.8 (VDD/VREF), JP1.17, R9.1
/V_BATT: C6.1, IC3.3 (CH1), R10.2, R11.2
GND: C1.2, C2.2, C3.2, C4.2, C5.2, C6.2, IC1.2 (GND), IC2.8 (GND), IC3.2 (CH0), IC3.4 (VSS), J1.1, J1.3, J1.5, J2.1, J2.3, J2.5, J3.2, JP1.6, JP1.9, JP1.14, JP1.25, JP1.30, JP1.34, JP1.39, R11.1, TP_GND1.1, U$1.GND, U$1.GND1
unnamed: J2.6, R10.1
unnamed: J3.4, R_11.2
unnamed: J3.6, R_8.2
unnamed: J4.2, R_7.2
unnamed: J4.4, R_10.2
unnamed: J4.6, R_12.2
unnamed: JP1.18, R8.2, U$1.NRES
unnamed: JP1.24, R1.2, U$1.NSEL (/NSEL)

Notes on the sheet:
Aufsteckplatine für Raspberry Pi
LED-Treiber
Schraubklemme rechts
Spannungsmessung
Spannungsregler
Funkmodul und Verbindungsleiste zum RasPi

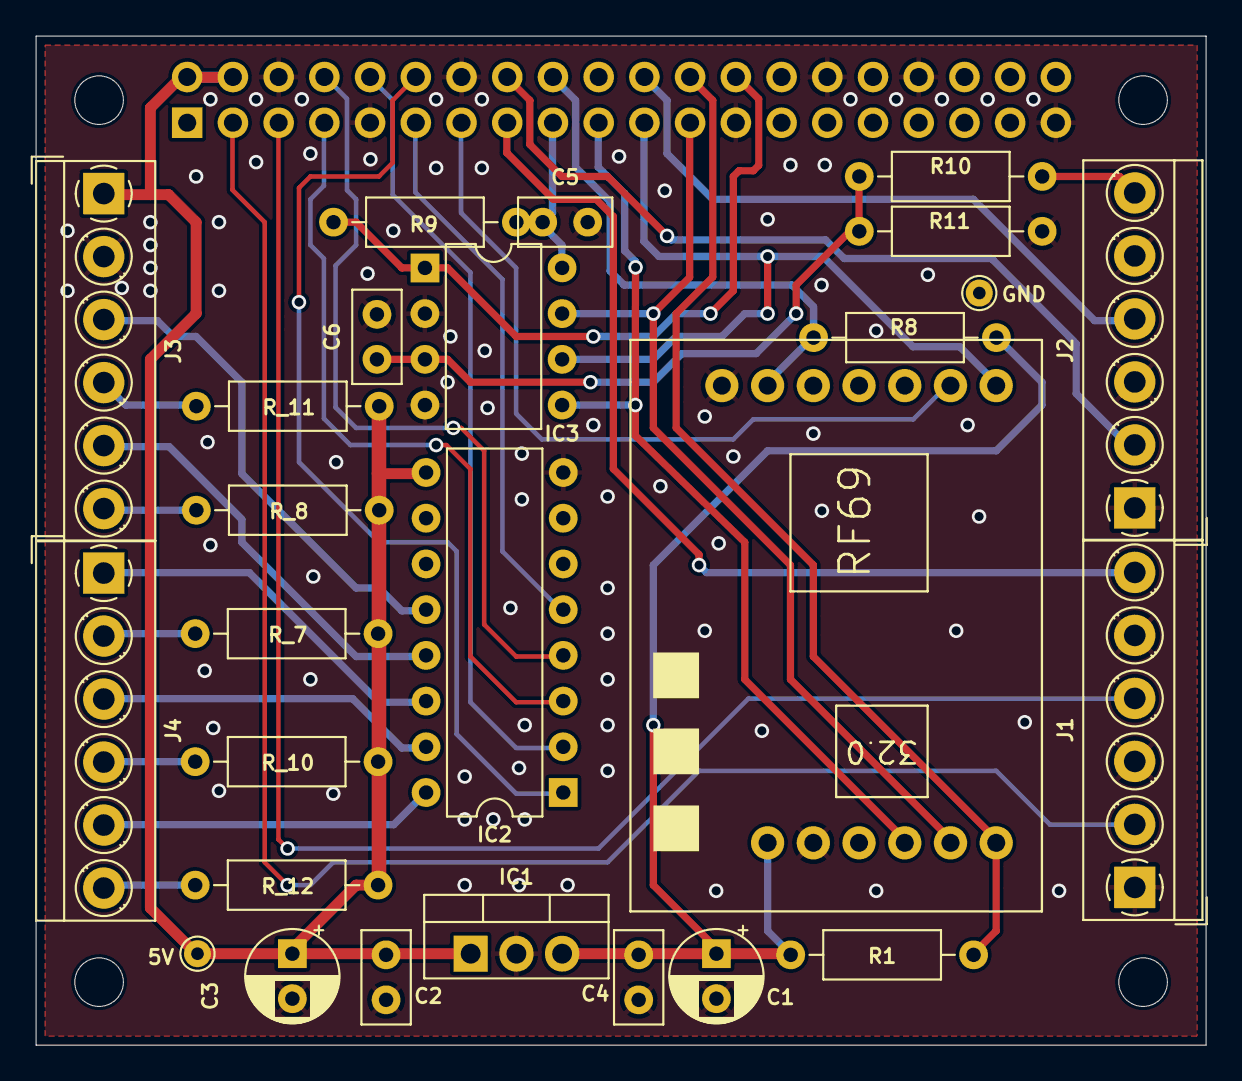
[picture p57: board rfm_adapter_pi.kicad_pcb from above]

Board: 2 copper layers, 65.0 x 56.1 mm, 27 parts (0 on the bottom side), 33 nets.

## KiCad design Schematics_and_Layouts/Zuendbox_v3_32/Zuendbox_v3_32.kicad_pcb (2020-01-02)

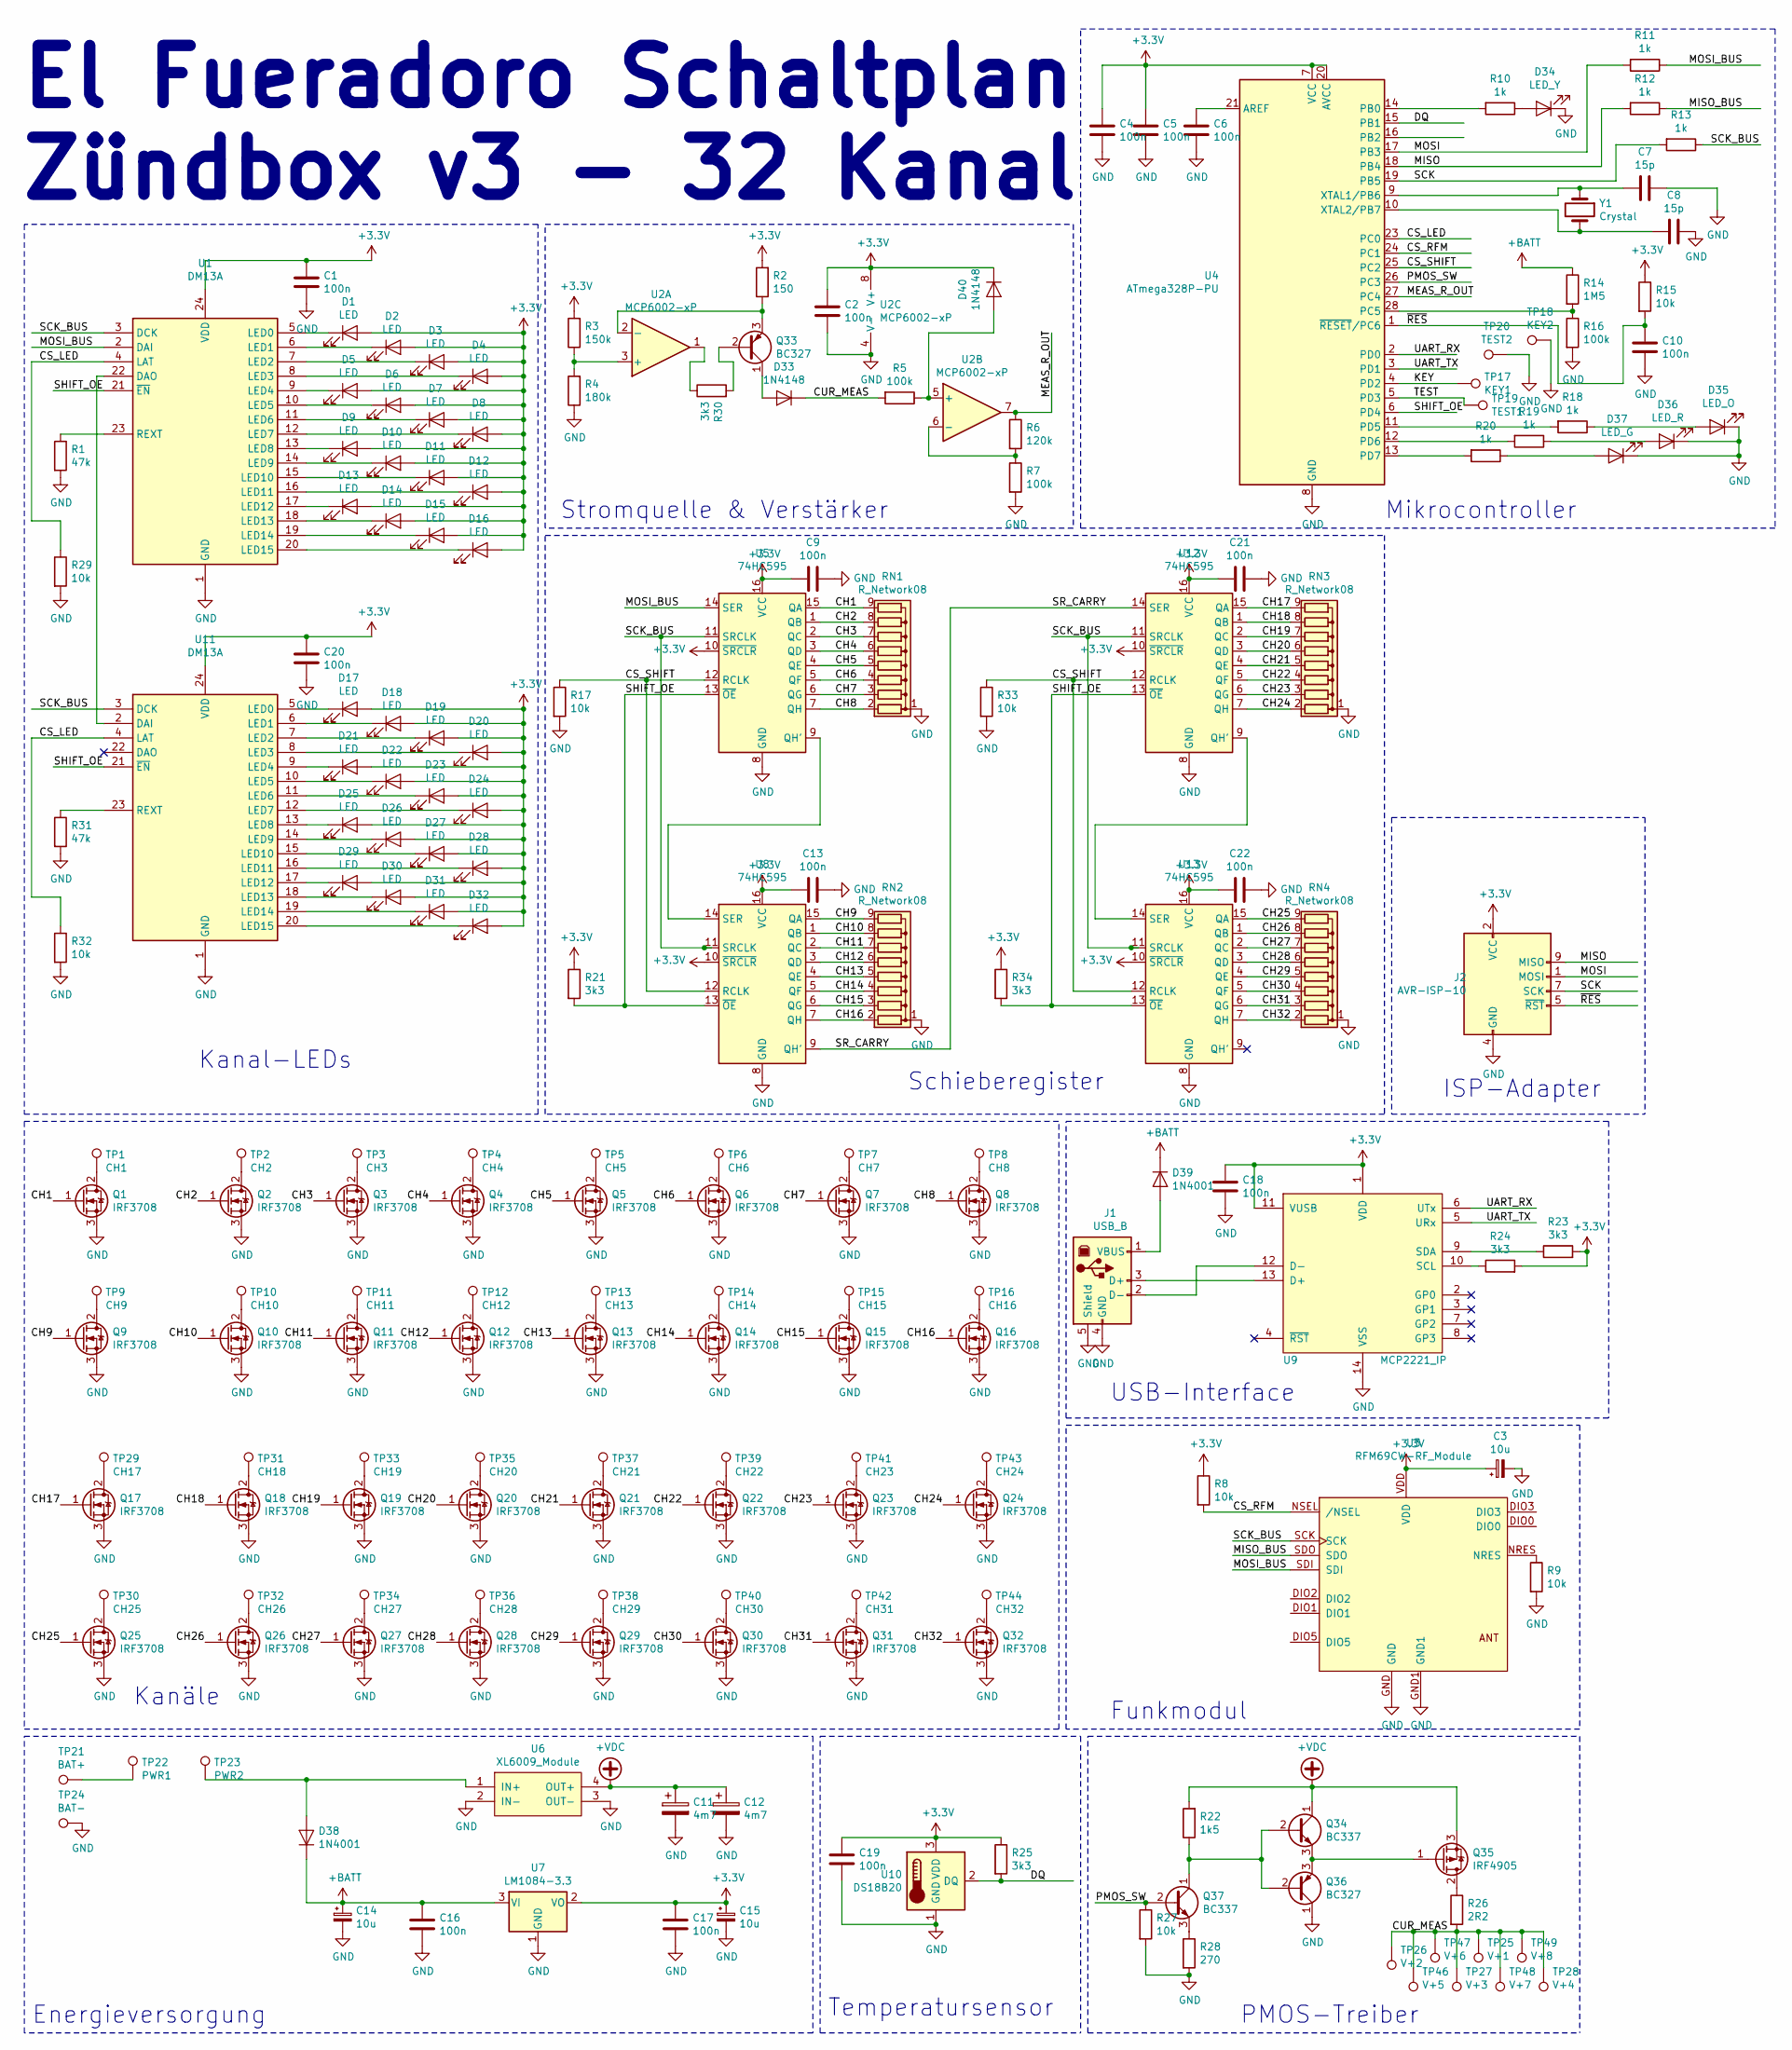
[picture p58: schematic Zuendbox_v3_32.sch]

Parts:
C1, C2, C4, C5, C6, C9, C10, C13, C16, C17, C18, C19, C20, C21, C22: 100n; C_Disc_D3.8mm_W2.6mm_P2.50mm
C3, C14, C15: 10u; CP_Radial_D6.3mm_P2.50mm
C7, C8: 15p; C_Disc_D3.8mm_W2.6mm_P2.50mm
C11, C12: 4m7; CP_Radial_D18.0mm_P7.50mm
D1, D2, D3, D4, D5, D6, D7, D8, D9, D10, D11, D12, D13, D14, D15, D16, D17, D18, D19, D20, D21, D22, D23, D24, D25, D26, D27, D28, D29, D30, D31, D32: LED; PinSocket_1x02_P2.54mm_Vertical
D33, D40: 1N4148; D_DO-35_SOD27_P7.62mm_Horizontal
D34: LED_Y; LED_D5.0mm
D35: LED_O; LED_D5.0mm
D36: LED_R; LED_D5.0mm
D37: LED_G; LED_D5.0mm
D38, D39: 1N4001; D_DO-41_SOD81_P10.16mm_Horizontal
J1: USB_B; USB_B_THT_Horizontal
J2: AVR-ISP-10; IDC-Header_2x05_P2.54mm_Vertical
Q1, Q2, Q3, Q4, Q5, Q6, Q7, Q8, Q9, Q10, Q11, Q12, Q13, Q14, Q15, Q16, Q17, Q18, Q19, Q20, Q21, Q22, Q23, Q24, Q25, Q26, Q27, Q28, Q29, Q30, Q31, Q32: IRF3708; TO-220-3_Vertical
Q33, Q36: BC327; TO-92_Inline_Wide
Q34, Q37: BC337; TO-92_Inline_Wide
Q35: IRF4905; TO-220-3_Vertical
R1, R31: 47k; R_Axial_DIN0207_L6.3mm_D2.5mm_P10.16mm_Horizontal
R2: 150; R_Axial_DIN0207_L6.3mm_D2.5mm_P10.16mm_Horizontal
R3: 150k; R_Axial_DIN0207_L6.3mm_D2.5mm_P10.16mm_Horizontal
R4: 180k; R_Axial_DIN0207_L6.3mm_D2.5mm_P10.16mm_Horizontal
R5, R7, R16: 100k; R_Axial_DIN0207_L6.3mm_D2.5mm_P10.16mm_Horizontal
R6: 120k; R_Axial_DIN0207_L6.3mm_D2.5mm_P10.16mm_Horizontal
R8, R9, R15, R17, R27, R29, R32, R33: 10k; R_Axial_DIN0207_L6.3mm_D2.5mm_P10.16mm_Horizontal
R10, R11, R12, R13, R18, R19, R20: 1k; R_Axial_DIN0207_L6.3mm_D2.5mm_P10.16mm_Horizontal
R14: 1M5; R_Axial_DIN0207_L6.3mm_D2.5mm_P10.16mm_Horizontal
R21, R23, R24, R25, R30, R34: 3k3; R_Axial_DIN0207_L6.3mm_D2.5mm_P10.16mm_Horizontal
R22: 1k5; R_Axial_DIN0207_L6.3mm_D2.5mm_P10.16mm_Horizontal
R26: 2R2; R_Radial_Power_L9.0mm_W10.0mm_Px2.90mm_Py2.40mm
R28: 270; R_Axial_DIN0207_L6.3mm_D2.5mm_P10.16mm_Horizontal
RN1, RN2, RN3, RN4: R_Network08; R_Array_SIP9
TP1: CH1; TestPoint_THTPad_D2.5mm_Drill1.2mm
TP2: CH2; TestPoint_THTPad_D2.5mm_Drill1.2mm
TP3: CH3; TestPoint_THTPad_D2.5mm_Drill1.2mm
TP4: CH4; TestPoint_THTPad_D2.5mm_Drill1.2mm
TP5: CH5; TestPoint_THTPad_D2.5mm_Drill1.2mm
TP6: CH6; TestPoint_THTPad_D2.5mm_Drill1.2mm
TP7: CH7; TestPoint_THTPad_D2.5mm_Drill1.2mm
TP8: CH8; TestPoint_THTPad_D2.5mm_Drill1.2mm
TP9: CH9; TestPoint_THTPad_D2.5mm_Drill1.2mm
TP10: CH10; TestPoint_THTPad_D2.5mm_Drill1.2mm
TP11: CH11; TestPoint_THTPad_D2.5mm_Drill1.2mm
TP12: CH12; TestPoint_THTPad_D2.5mm_Drill1.2mm
TP13: CH13; TestPoint_THTPad_D2.5mm_Drill1.2mm
TP14: CH14; TestPoint_THTPad_D2.5mm_Drill1.2mm
TP15: CH15; TestPoint_THTPad_D2.5mm_Drill1.2mm
TP16: CH16; TestPoint_THTPad_D2.5mm_Drill1.2mm
TP17: KEY1; TestPoint_THTPad_D2.5mm_Drill1.2mm
TP18: KEY2; TestPoint_THTPad_D2.5mm_Drill1.2mm
TP19: TEST1; TestPoint_THTPad_D2.5mm_Drill1.2mm
TP20: TEST2; TestPoint_THTPad_D2.5mm_Drill1.2mm
TP21: BAT+; TestPoint_THTPad_D2.5mm_Drill1.2mm
TP22: PWR1; TestPoint_THTPad_D2.5mm_Drill1.2mm
TP23: PWR2; TestPoint_THTPad_D2.5mm_Drill1.2mm
TP24: BAT-; TestPoint_THTPad_D2.5mm_Drill1.2mm
TP25: V+1; TestPoint_THTPad_D2.5mm_Drill1.2mm
TP26: V+2; TestPoint_THTPad_D2.5mm_Drill1.2mm
TP27: V+3; TestPoint_THTPad_D2.5mm_Drill1.2mm
TP28: V+4; TestPoint_THTPad_D2.5mm_Drill1.2mm
TP29: CH17; TestPoint_THTPad_D2.5mm_Drill1.2mm
TP30: CH25; TestPoint_THTPad_D2.5mm_Drill1.2mm
TP31: CH18; TestPoint_THTPad_D2.5mm_Drill1.2mm
TP32: CH26; TestPoint_THTPad_D2.5mm_Drill1.2mm
TP33: CH19; TestPoint_THTPad_D2.5mm_Drill1.2mm
TP34: CH27; TestPoint_THTPad_D2.5mm_Drill1.2mm
TP35: CH20; TestPoint_THTPad_D2.5mm_Drill1.2mm
TP36: CH28; TestPoint_THTPad_D2.5mm_Drill1.2mm
TP37: CH21; TestPoint_THTPad_D2.5mm_Drill1.2mm
TP38: CH29; TestPoint_THTPad_D2.5mm_Drill1.2mm
TP39: CH22; TestPoint_THTPad_D2.5mm_Drill1.2mm
TP40: CH30; TestPoint_THTPad_D2.5mm_Drill1.2mm
TP41: CH23; TestPoint_THTPad_D2.5mm_Drill1.2mm
TP42: CH31; TestPoint_THTPad_D2.5mm_Drill1.2mm
TP43: CH24; TestPoint_THTPad_D2.5mm_Drill1.2mm
TP44: CH32; TestPoint_THTPad_D2.5mm_Drill1.2mm
TP46: V+5; TestPoint_THTPad_D2.5mm_Drill1.2mm
TP47: V+6; TestPoint_THTPad_D2.5mm_Drill1.2mm
TP48: V+7; TestPoint_THTPad_D2.5mm_Drill1.2mm
TP49: V+8; TestPoint_THTPad_D2.5mm_Drill1.2mm
U1, U11: DM13A; DIP-24_W7.62mm
U2: MCP6002-xP; DIP-8_W7.62mm
U3: RFM69CW-RF_Module; RFM69CW
U4: ATmega328P-PU; DIP-28_W7.62mm
U5, U8, U12, U13: 74HC595; DIP-16_W7.62mm
U6: XL6009_Module; XL6009_STEP-UP-MODULE
U7: LM1084-3.3; TO-220-3_Horizontal_TabDown
U9: MCP2221_IP; DIP-14_W7.62mm
U10: DS18B20; TO-92_Inline_Wide
Y1: Crystal; Crystal_HC49-U_Vertical

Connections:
+3V3: C1.1, C2.1, C3.1, C4.2, C5.2, C9.2, C13.2, C15.1, C17.2, C18.2, C19.2, C20.1, C21.2, C22.2, D1.2 (A), D2.2 (A), D3.2 (A), D4.2 (A), D5.2 (A), D6.2 (A), D7.2 (A), D8.2 (A), D9.2 (A), D10.2 (A), D11.2 (A), D12.2 (A), D13.2 (A), D14.2 (A), D15.2 (A), D16.2 (A), D17.2 (A), D18.2 (A), D19.2 (A), D20.2 (A), D21.2 (A), D22.2 (A), D23.2 (A), D24.2 (A), D25.2 (A), D26.2 (A), D27.2 (A), D28.2 (A), D29.2 (A), D30.2 (A), D31.2 (A), D32.2 (A), D40.1 (K), J2.2 (VCC), R2.2, R3.2, R8.1, R15.1, R21.1, R23.2, R24.2, R25.1, R34.1, U1.24 (VDD), U2.8 (V+), U3.VDD, U4.7 (VCC), U4.20 (AVCC), U5.10 (~SRCLR), U5.16 (VCC), U7.2 (VO), U8.10 (~SRCLR), U8.16 (VCC), U9.1 (VDD), U9.11 (VUSB), U10.3 (VDD), U11.24 (VDD), U12.10 (~SRCLR), U12.16 (VCC), U13.10 (~SRCLR), U13.16 (VCC)
+BATT: C14.1, C16.2, D38.1 (K), D39.1 (K), R14.1, U7.3 (VI)
+VDC: C11.1, C12.1, Q34.1 (C), Q35.3 (S), R22.2, U6.4 (OUT+)
/CH1: Q1.1 (G), RN1.9 (R8), U5.15 (QA)
/CH2: Q2.1 (G), RN1.8 (R7), U5.1 (QB)
/CH3: Q3.1 (G), RN1.7 (R6), U5.2 (QC)
/CH4: Q4.1 (G), RN1.6 (R5), U5.3 (QD)
/CH5: Q5.1 (G), RN1.5 (R4), U5.4 (QE)
/CH6: Q6.1 (G), RN1.4 (R3), U5.5 (QF)
/CH7: Q7.1 (G), RN1.3 (R2), U5.6 (QG)
/CH8: Q8.1 (G), RN1.2 (R1), U5.7 (QH)
/CH9: Q9.1 (G), RN2.9 (R8), U8.15 (QA)
/CH10: Q10.1 (G), RN2.8 (R7), U8.1 (QB)
/CH11: Q11.1 (G), RN2.7 (R6), U8.2 (QC)
/CH12: Q12.1 (G), RN2.6 (R5), U8.3 (QD)
/CH13: Q13.1 (G), RN2.5 (R4), U8.4 (QE)
/CH14: Q14.1 (G), RN2.4 (R3), U8.5 (QF)
/CH15: Q15.1 (G), RN2.3 (R2), U8.6 (QG)
/CH16: Q16.1 (G), RN2.2 (R1), U8.7 (QH)
/CH17: Q17.1 (G), RN3.9 (R8), U12.15 (QA)
/CH18: Q18.1 (G), RN3.8 (R7), U12.1 (QB)
/CH19: Q19.1 (G), RN3.7 (R6), U12.2 (QC)
/CH20: Q20.1 (G), RN3.6 (R5), U12.3 (QD)
/CH21: Q21.1 (G), RN3.5 (R4), U12.4 (QE)
/CH22: Q22.1 (G), RN3.4 (R3), U12.5 (QF)
/CH23: Q23.1 (G), RN3.3 (R2), U12.6 (QG)
/CH24: Q24.1 (G), RN3.2 (R1), U12.7 (QH)
/CH25: Q25.1 (G), RN4.9 (R8), U13.15 (QA)
/CH26: Q26.1 (G), RN4.8 (R7), U13.1 (QB)
/CH27: Q27.1 (G), RN4.7 (R6), U13.2 (QC)
/CH28: Q28.1 (G), RN4.6 (R5), U13.3 (QD)
/CH29: Q29.1 (G), RN4.5 (R4), U13.4 (QE)
/CH30: Q30.1 (G), RN4.4 (R3), U13.5 (QF)
/CH31: Q31.1 (G), RN4.3 (R2), U13.6 (QG)
/CH32: Q32.1 (G), RN4.2 (R1), U13.7 (QH)
/CS_LED: R29.1, R32.1, U1.4 (LAT), U4.23 (PC0), U11.4 (LAT)
/CS_RFM: R8.2, U3.NSEL (/NSEL), U4.24 (PC1)
/CS_SHIFT: R17.1, R33.1, U4.25 (PC2), U5.12 (RCLK), U8.12 (RCLK), U12.12 (RCLK), U13.12 (RCLK)
/CUR_MEAS: D33.1 (K), R5.2, R26.2, TP25.1, TP26.1, TP27.1, TP28.1, TP46.1, TP47.1, TP48.1, TP49.1
/DQ: R25.2, U4.15 (PB1), U10.2 (DQ)
/KEY: TP17.1, U4.4 (PD2)
/MEAS_R_OUT: R6.1, U2.7, U4.27 (PC4)
/MISO: J2.9 (MISO), R12.2, U4.18 (PB4)
/MISO_BUS: R12.1, U3.SDO
/MOSI: J2.1 (MOSI), R11.2, U4.17 (PB3)
/MOSI_BUS: R11.1, U1.2 (DAI), U3.SDI, U5.14 (SER)
/PMOS_SW: Q37.2 (B), R27.1, U4.26 (PC3)
/SCK: J2.7 (SCK), R13.2, U4.19 (PB5)
/SCK_BUS: R13.1, U1.3 (DCK), U3.SCK, U5.11 (SRCLK), U8.11 (SRCLK), U11.3 (DCK), U12.11 (SRCLK), U13.11 (SRCLK)
/SHIFT_OE: R21.2, R34.2, U1.21 (~EN), U4.6 (PD4), U5.13 (~OE), U8.13 (~OE), U11.21 (~EN), U12.13 (~OE), U13.13 (~OE)
/SR_CARRY: U8.9 (QH'), U12.14 (SER)
/TEST: TP19.1, U4.5 (PD3)
/UART_RX: U4.2 (PD0), U9.6 (UTx)
/UART_TX: U4.3 (PD1), U9.5 (URx)
/~RES: C10.2, J2.5 (~RST), R15.2, U4.1 (~RESET~/PC6)
GND: C1.2, C2.2, C3.2, C4.1, C5.1, C6.1, C7.1, C8.1, C9.1, C10.1, C11.2, C12.2, C13.1, C14.2, C15.2, C16.1, C17.1, C18.1, C19.1, C20.2, C21.1, C22.1, D34.1 (K), D35.1 (K), D36.1 (K), D37.1 (K), J1.4 (GND), J1.5 (Shield), J2.4 (GND), J2.6 (GND), J2.8 (GND), J2.10 (GND), Q1.3 (S), Q2.3 (S), Q3.3 (S), Q4.3 (S), Q5.3 (S), Q6.3 (S), Q7.3 (S), Q8.3 (S), Q9.3 (S), Q10.3 (S), Q11.3 (S), Q12.3 (S), Q13.3 (S), Q14.3 (S), Q15.3 (S), Q16.3 (S), Q17.3 (S), Q18.3 (S), Q19.3 (S), Q20.3 (S), Q21.3 (S), Q22.3 (S), Q23.3 (S), Q24.3 (S), Q25.3 (S), Q26.3 (S), Q27.3 (S), Q28.3 (S), Q29.3 (S), Q30.3 (S), Q31.3 (S), Q32.3 (S), Q36.1 (C), R1.2, R4.1, R7.2, R9.2, R16.2, R17.2, R27.2, R28.2, R29.2, R31.2, R32.2, R33.2, RN1.1 (common), RN2.1 (common), RN3.1 (common), RN4.1 (common), TP18.1, TP20.1, TP24.1, U1.1 (GND), U2.4 (V-), U3.GND, U3.GND1, U4.8 (GND), U4.22 (GND), U5.8 (GND), U6.2 (IN-), U6.3 (OUT-), U7.1 (GND), U8.8 (GND), U9.14 (VSS), U10.1 (GND), U11.1 (GND), U12.8 (GND), U13.8 (GND)
unnamed: C6.2, U4.21 (AREF)
unnamed: C7.2, U4.9 (XTAL1/PB6), Y1.1
unnamed: C8.2, U4.10 (XTAL2/PB7), Y1.2
unnamed: D1.1 (K), U1.5 (LED0)
unnamed: D2.1 (K), U1.6 (LED1)
unnamed: D3.1 (K), U1.7 (LED2)
unnamed: D4.1 (K), U1.8 (LED3)
unnamed: D5.1 (K), U1.9 (LED4)
unnamed: D6.1 (K), U1.10 (LED5)
unnamed: D7.1 (K), U1.11 (LED6)
unnamed: D8.1 (K), U1.12 (LED7)
unnamed: D9.1 (K), U1.13 (LED8)
unnamed: D10.1 (K), U1.14 (LED9)
unnamed: D11.1 (K), U1.15 (LED10)
unnamed: D12.1 (K), U1.16 (LED11)
unnamed: D13.1 (K), U1.17 (LED12)
unnamed: D14.1 (K), U1.18 (LED13)
unnamed: D15.1 (K), U1.19 (LED14)
unnamed: D16.1 (K), U1.20 (LED15)
unnamed: D17.1 (K), U11.5 (LED0)
unnamed: D18.1 (K), U11.6 (LED1)
unnamed: D19.1 (K), U11.7 (LED2)
unnamed: D20.1 (K), U11.8 (LED3)
unnamed: D21.1 (K), U11.9 (LED4)
unnamed: D22.1 (K), U11.10 (LED5)
unnamed: D23.1 (K), U11.11 (LED6)
unnamed: D24.1 (K), U11.12 (LED7)
unnamed: D25.1 (K), U11.13 (LED8)
unnamed: D26.1 (K), U11.14 (LED9)
unnamed: D27.1 (K), U11.15 (LED10)
unnamed: D28.1 (K), U11.16 (LED11)
unnamed: D29.1 (K), U11.17 (LED12)
unnamed: D30.1 (K), U11.18 (LED13)
unnamed: D31.1 (K), U11.19 (LED14)
unnamed: D32.1 (K), U11.20 (LED15)
unnamed: D33.2 (A), Q33.1 (C)
unnamed: D34.2 (A), R10.1
unnamed: D35.2 (A), R18.1
unnamed: D36.2 (A), R19.1
unnamed: D37.2 (A), R20.1
unnamed: D38.2 (A), TP23.1, U6.1 (IN+)
unnamed: D39.2 (A), J1.1 (VBUS)
unnamed: D40.2 (A), R5.1, U2.5 (+)
unnamed: J1.2 (D-), U9.12 (D-)
unnamed: J1.3 (D+), U9.13 (D+)
unnamed: Q1.2 (D), TP1.1
unnamed: Q2.2 (D), TP2.1
unnamed: Q3.2 (D), TP3.1
unnamed: Q4.2 (D), TP4.1
unnamed: Q5.2 (D), TP5.1
unnamed: Q6.2 (D), TP6.1
unnamed: Q7.2 (D), TP7.1
unnamed: Q8.2 (D), TP8.1
unnamed: Q9.2 (D), TP9.1
unnamed: Q10.2 (D), TP10.1
unnamed: Q11.2 (D), TP11.1
unnamed: Q12.2 (D), TP12.1
unnamed: Q13.2 (D), TP13.1
unnamed: Q14.2 (D), TP14.1
unnamed: Q15.2 (D), TP15.1
unnamed: Q16.2 (D), TP16.1
unnamed: Q17.2 (D), TP29.1
unnamed: Q18.2 (D), TP31.1
unnamed: Q19.2 (D), TP33.1
unnamed: Q20.2 (D), TP35.1
unnamed: Q21.2 (D), TP37.1
unnamed: Q22.2 (D), TP39.1
unnamed: Q23.2 (D), TP41.1
unnamed: Q24.2 (D), TP43.1
unnamed: Q25.2 (D), TP30.1
unnamed: Q26.2 (D), TP32.1
unnamed: Q27.2 (D), TP34.1
unnamed: Q28.2 (D), TP36.1
unnamed: Q29.2 (D), TP38.1
unnamed: Q30.2 (D), TP40.1
unnamed: Q31.2 (D), TP42.1
unnamed: Q32.2 (D), TP44.1
unnamed: Q33.2 (B), R30.2
unnamed: Q33.3 (E), R2.1, U2.2 (-)
unnamed: Q34.2 (B), Q36.2 (B), Q37.1 (C), R22.1
unnamed: Q34.3 (E), Q35.1 (G), Q36.3 (E)
unnamed: Q35.2 (D), R26.1
unnamed: Q37.3 (E), R28.1
unnamed: R1.1, U1.23 (REXT)
unnamed: R3.1, R4.2, U2.3 (+)
unnamed: R6.2, R7.1, U2.6 (-)
unnamed: R9.1, U3.NRES
unnamed: R10.2, U4.14 (PB0)
unnamed: R14.2, R16.1, U4.28 (PC5)
unnamed: R18.2, U4.11 (PD5)
unnamed: R19.2, U4.12 (PD6)
unnamed: R20.2, U4.13 (PD7)
unnamed: R23.1, U9.9 (SDA)
unnamed: R24.1, U9.10 (SCL)
unnamed: R30.1, U2.1
unnamed: R31.1, U11.23 (REXT)
unnamed: TP21.1, TP22.1
unnamed: U1.22 (DAO), U11.2 (DAI)
unnamed: U5.9 (QH'), U8.14 (SER)
unnamed: U12.9 (QH'), U13.14 (SER)

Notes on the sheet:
El Fueradoro Schaltplan Zündbox v3 - 32 Kanal
Temperatursensor
PMOS-Treiber
Funkmodul
Schieberegister
Stromquelle & Verstärker
Energieversorgung
Mikrocontroller
ISP-Adapter
USB-Interface
Kanäle
Kanal-LEDs

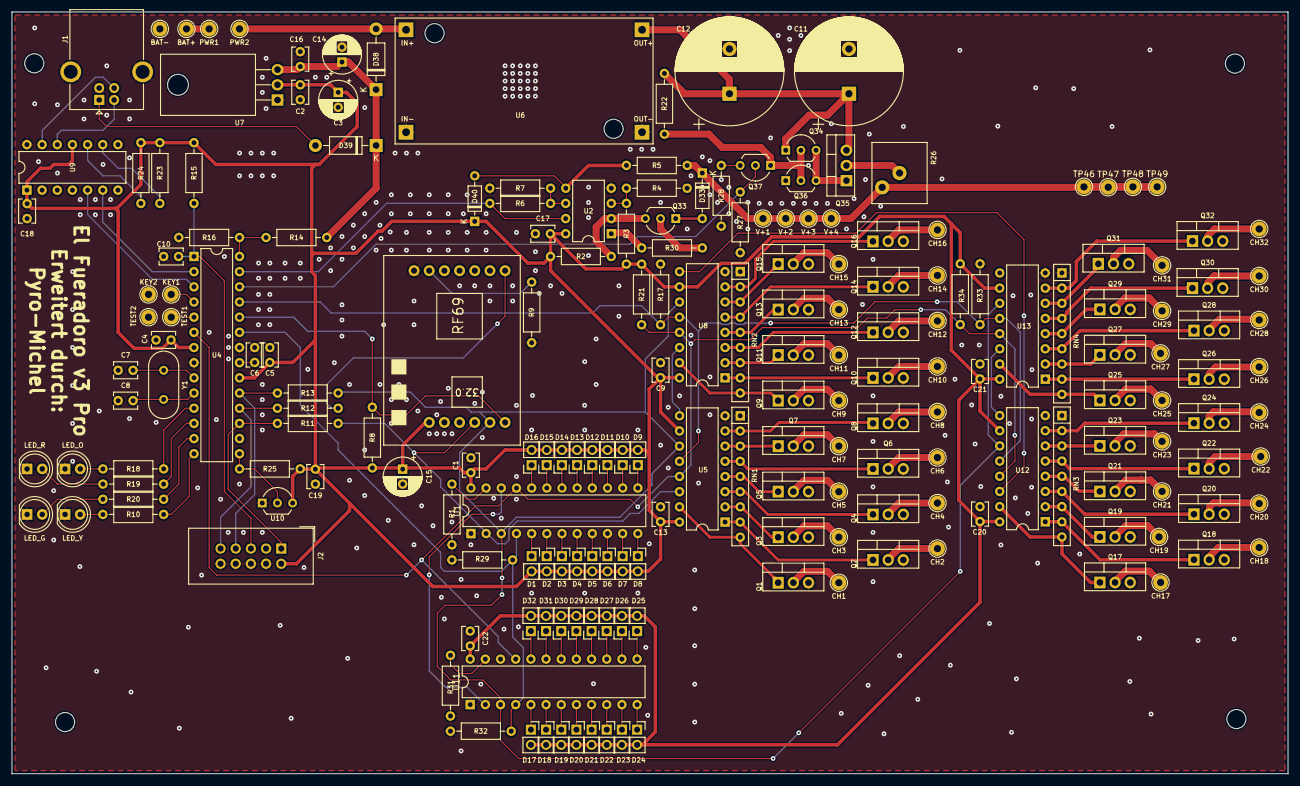
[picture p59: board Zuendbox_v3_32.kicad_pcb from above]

Board: 2 copper layers, 213.6 x 127.5 mm, 201 parts (0 on the bottom side), 156 nets.

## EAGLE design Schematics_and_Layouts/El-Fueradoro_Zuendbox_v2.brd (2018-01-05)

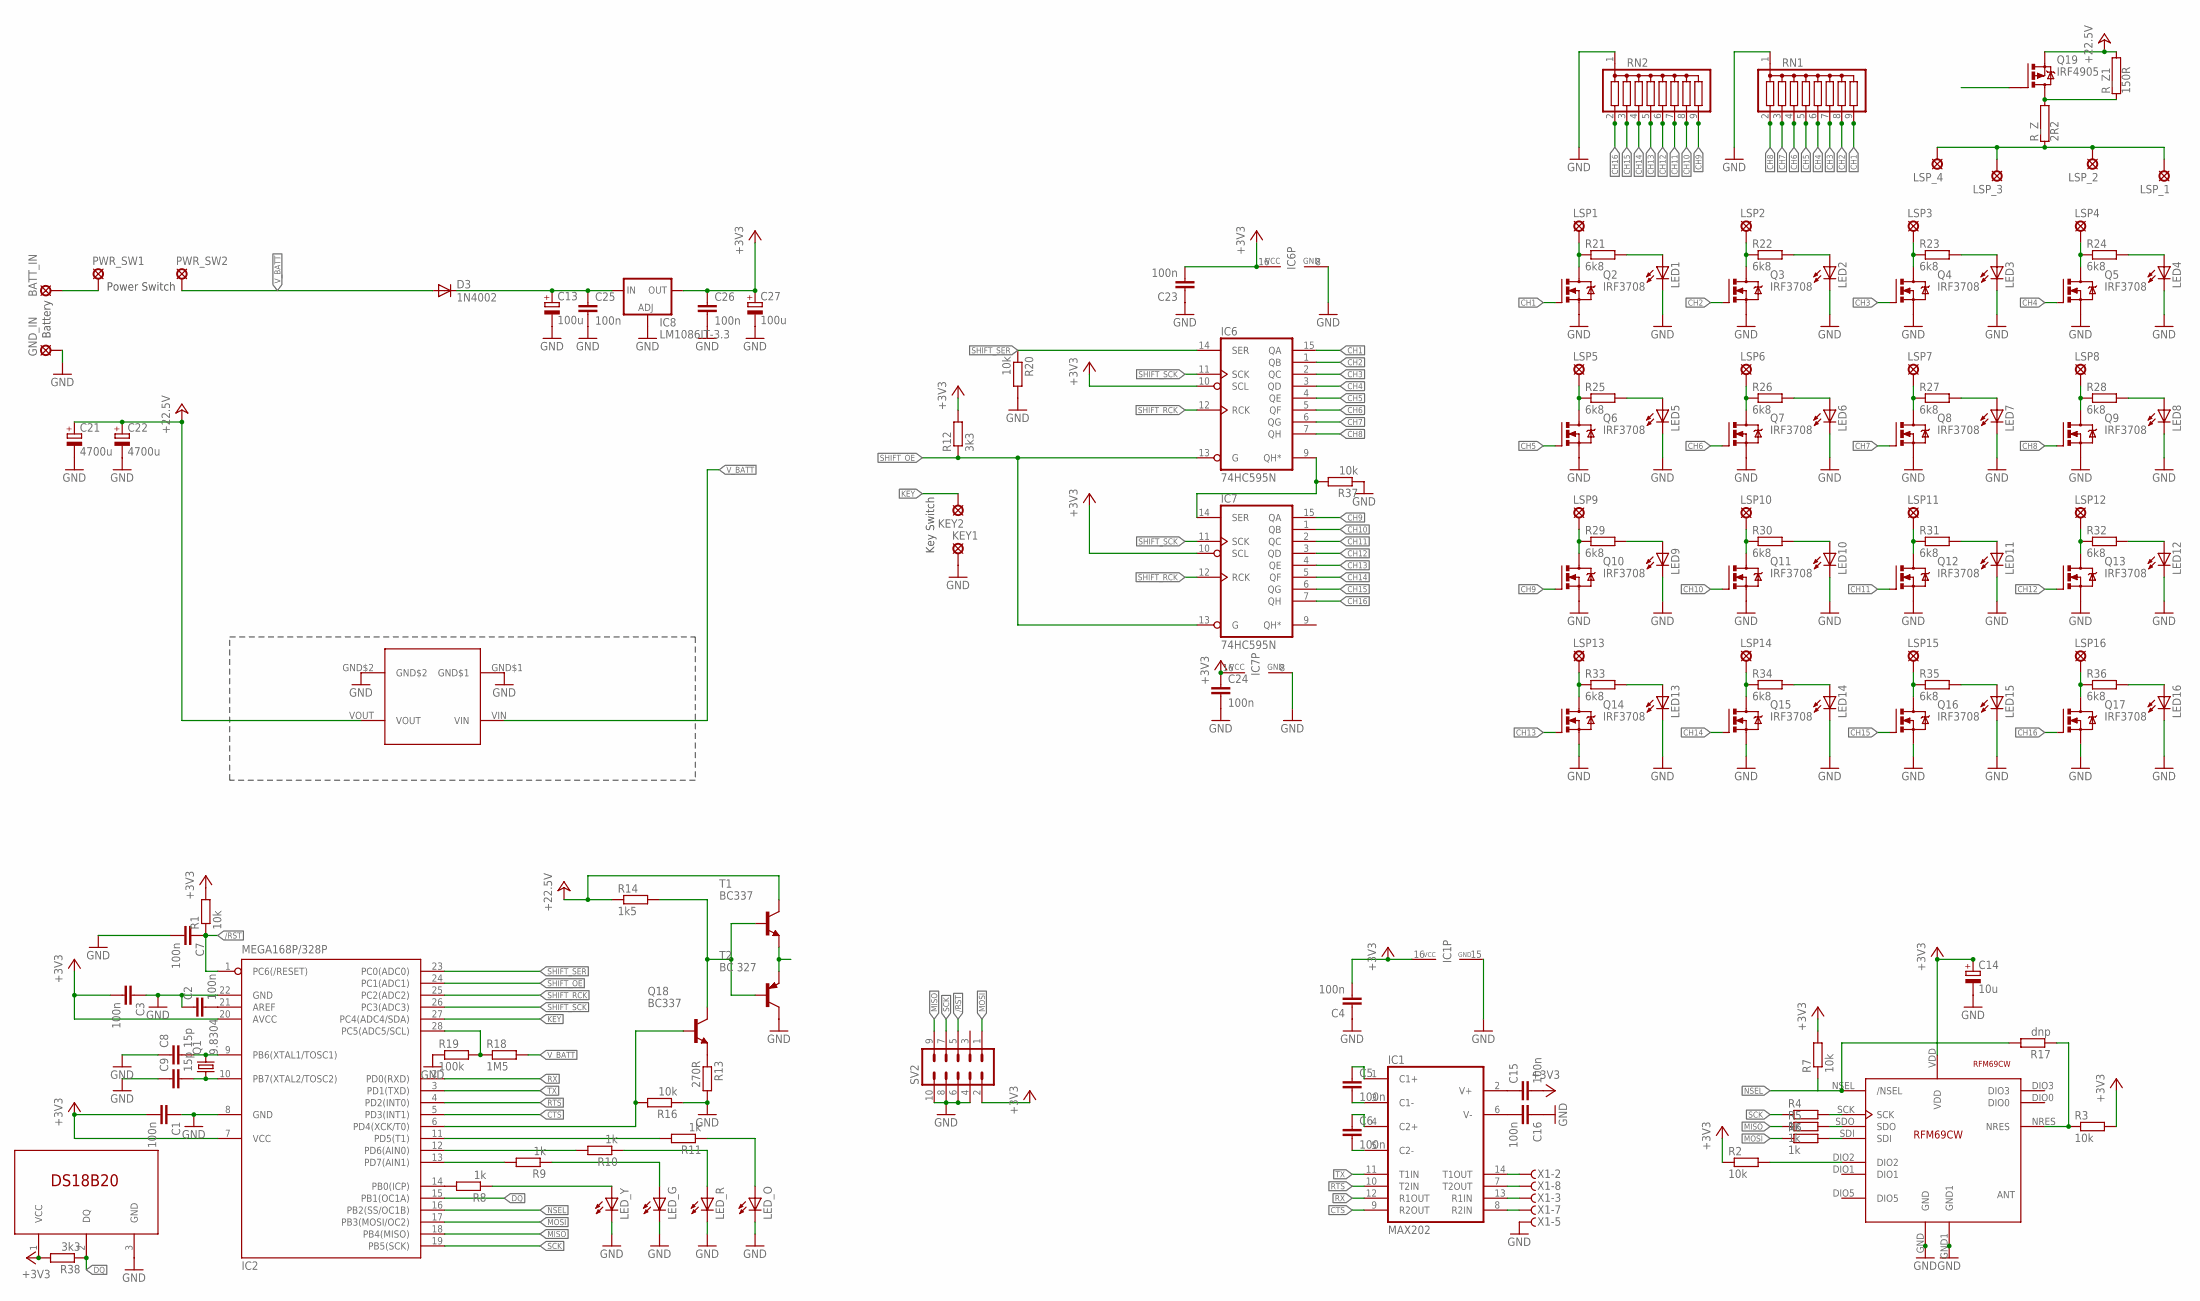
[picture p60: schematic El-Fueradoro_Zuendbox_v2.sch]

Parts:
BATT_IN: LSP10
C1, C2, C3, C4, C5, C6, C7, C15, C16, C23, C24, C25, C26: 100n; C025-024X044
C8, C9: 15p; C025-024X044
C13, C27: 100u; B45181A
C14: 10u; B45181A
C21, C22: 4700u; E7,5-18
D3: 1N4002; DO41-10
GND_IN: LSP10
IC1: MAX202; DIL16
IC2: MEGA168P/328P; DIL28-3
IC6, IC7: 74HC595N; DIL16
IC8: LM1086IT-3.3; TO220L1
KEY1, KEY2: LSP10
LED1, LED2, LED3, LED4, LED5, LED6, LED7, LED8, LED9, LED10, LED11, LED12, LED13, LED14, LED15, LED16: LED3MM
LED_G: LED5MM
LED_O: LED5MM
LED_R: LED5MM
LED_Y: LED5MM
LSP1: CH1; LSP11
LSP2: CH2; LSP11
LSP3: CH3; LSP11
LSP4: CH4; LSP11
LSP5: CH5; LSP11
LSP6: CH6; LSP11
LSP7: CH7; LSP11
LSP8: CH8; LSP11
LSP9: CH9; LSP11
LSP10: CH10; LSP11
LSP11: CH11; LSP11
LSP12: CH12; LSP11
LSP13: CH13; LSP11
LSP14: CH14; LSP11
LSP15: CH15; LSP11
LSP16: CH16; LSP11
LSP_1, LSP_2, LSP_3, LSP_4: LSP11
PWR_SW1, PWR_SW2: LSP10
Q1: 9.8304; HC49/S
Q2, Q3, Q4, Q5, Q6, Q7, Q8, Q9, Q10, Q11, Q12, Q13, Q14, Q15, Q16, Q17: IRF3708; TO220BV
Q18: BC337; TO92
Q19: IRF4905; TO220BV
R1, R2, R3, R7, R16, R20, R37: 10k; 0207/10
R4, R5, R6, R8, R9, R10, R11: 1k; 0207/10
R12, R38: 3k3; 0207/10
R13: 270R; 0207/10
R14: 1k5; 0207/10
R17: dnp; 0207/10
R18: 1M5; 0207/10
R19: 100k; 0207/10
R21, R22, R23, R24, R25, R26, R27, R28, R29, R30, R31, R32, R33, R34, R35, R36: 6k8; 0207/10
RN1, RN2: G08R; SIL9
R_Z: 2R2; KH214R-8
R_Z1: 150R; KH214R-8
SV2: ML10
T1: BC337; TO92
T2: BC 327; TO92
U$2: DS18B20; TO92-LINE
U$3: XL6009_MODULED; XL6009_PACK
U$4: RFM69CW
X1: F09HPS; F09HP

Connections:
+3V3: C1.2, C3.2, C4.2, C14.+, C15.2, C23.2, C24.1, C26.1, C27.+, IC1.16 (VCC), IC2.7 (VCC), IC2.20 (AVCC), IC6.10 (SCL), IC6.16 (VCC), IC7.10 (SCL), IC7.16 (VCC), IC8.2 (OUT), R1.2, R2.1, R3.2, R7.2, R12.2, R38.2, SV2.2, U$2.1 (VCC), U$4.VDD
+22_5V: C21.+, C22.+, Q19.S, R14.1, R_Z1.2, T1.3 (C), U$3.VOUT
/RST: C7.1, IC2.1 (PC6(/RESET)), R1.1, SV2.5
CH1: IC6.15 (QA), Q2.G, RN1.9
CH2: IC6.1 (QB), Q3.G, RN1.8
CH3: IC6.2 (QC), Q4.G, RN1.7
CH4: IC6.3 (QD), Q5.G, RN1.6
CH5: IC6.4 (QE), Q6.G, RN1.5
CH6: IC6.5 (QF), Q7.G, RN1.4
CH7: IC6.6 (QG), Q8.G, RN1.3
CH8: IC6.7 (QH), Q9.G, RN1.2
CH9: IC7.15 (QA), Q10.G, RN2.9
CH10: IC7.1 (QB), Q11.G, RN2.8
CH11: IC7.2 (QC), Q12.G, RN2.7
CH12: IC7.3 (QD), Q13.G, RN2.6
CH13: IC7.4 (QE), Q14.G, RN2.5
CH14: IC7.5 (QF), Q15.G, RN2.4
CH15: IC7.6 (QG), Q16.G, RN2.3
CH16: IC7.7 (QH), Q17.G, RN2.2
CTS: IC1.9 (R2OUT), IC2.5 (PD3(INT1))
DQ: IC2.15 (PB1(OC1A)), R38.1, U$2.2 (DQ)
DRVBASE: Q18.3 (C), R14.2, T1.2 (B), T2.2 (B)
GND: C1.1, C2.1, C3.1, C4.1, C7.2, C8.1, C9.1, C13.-, C14.-, C16.1, C21.-, C22.-, C23.1, C24.2, C25.2, C26.2, C27.-, GND_IN.MP, IC1.15 (GND), IC2.8 (GND), IC2.22 (GND), IC6.8 (GND), IC7.8 (GND), IC8.1 (ADJ), KEY1.MP, LED1.K (C), LED2.K (C), LED3.K (C), LED4.K (C), LED5.K (C), LED6.K (C), LED7.K (C), LED8.K (C), LED9.K (C), LED10.K (C), LED11.K (C), LED12.K (C), LED13.K (C), LED14.K (C), LED15.K (C), LED16.K (C), LED_G.K (C), LED_O.K (C), LED_R.K (C), LED_Y.K (C), Q2.S, Q3.S, Q4.S, Q5.S, Q6.S, Q7.S, Q8.S, Q9.S, Q10.S, Q11.S, Q12.S, Q13.S, Q14.S, Q15.S, Q16.S, Q17.S, R13.2, R16.1, R19.1, R20.2, R37.1, RN1.1, RN2.1, SV2.4, SV2.6, SV2.8, SV2.10, T2.3 (C), U$2.3 (GND), U$3.GND$1, U$3.GND$2, U$4.GND, U$4.GND1, X1.5 (F)
KEY: IC2.27 (PC4(ADC4/SDA)), KEY2.MP
MISO: IC2.18 (PB4(MISO)), R5.1, SV2.9
MOSI: IC2.17 (PB3(MOSI/OC2)), R6.1, SV2.1
unnamed: BATT_IN.MP, PWR_SW1.MP
unnamed: C13.+, C25.1, D3.C, IC8.3 (IN)
unnamed: IC2.6 (PD4(XCK/T0)), Q18.2 (B), R16.2
unnamed: Q18.1 (E), R13.1
unnamed: LSP_1.MP, LSP_2.MP, LSP_3.MP, LSP_4.MP, R_Z.1
unnamed: Q19.D, R_Z.2, R_Z1.1
unnamed: R2.2, U$4.DIO2
unnamed: R4.2, U$4.SCK
unnamed: R5.2, U$4.SDO
unnamed: R6.2, U$4.SDI
unnamed: R3.1, R17.1, U$4.NRES
unnamed: C2.2, IC2.21 (AREF)
unnamed: C9.2, IC2.10 (PB7(XTAL2/TOSC2)), Q1.1
unnamed: C5.1, IC1.1 (C1+)
unnamed: C5.2, IC1.3 (C1-)
unnamed: C6.1, IC1.4 (C2+)
unnamed: C6.2, IC1.5 (C2-)
unnamed: C8.2, IC2.9 (PB6(XTAL1/TOSC1)), Q1.2
unnamed: IC2.13 (PD7(AIN1)), R9.2
unnamed: IC2.12 (PD6(AIN0)), R10.2
unnamed: IC2.11 (PD5(T1)), R11.2
unnamed: LED_O.A, R11.1
unnamed: IC2.14 (PB0(ICP)), R8.2
unnamed: LED_R.A, R10.1
unnamed: LED_G.A, R9.1
unnamed: LED_Y.A, R8.1
unnamed: IC2.28 (PC5(ADC5/SCL)), R18.1, R19.2
unnamed: C15.1, IC1.2 (V+)
unnamed: C16.2, IC1.6 (V-)
unnamed: IC6.9 (QH*), IC7.14 (SER), R37.2
unnamed: LSP1.MP, Q2.D, R21.1
unnamed: LSP2.MP, Q3.D, R22.1
unnamed: LSP3.MP, Q4.D, R23.1
unnamed: LSP4.MP, Q5.D, R24.1
unnamed: LSP5.MP, Q6.D, R25.1
unnamed: LSP6.MP, Q7.D, R26.1
unnamed: LSP7.MP, Q8.D, R27.1
unnamed: LSP8.MP, Q9.D, R28.1
unnamed: LSP9.MP, Q10.D, R29.1
unnamed: LSP10.MP, Q11.D, R30.1
unnamed: LSP11.MP, Q12.D, R31.1
unnamed: LSP12.MP, Q13.D, R32.1
unnamed: LSP13.MP, Q14.D, R33.1
unnamed: LSP14.MP, Q15.D, R34.1
unnamed: LSP15.MP, Q16.D, R35.1
unnamed: LSP16.MP, Q17.D, R36.1
unnamed: LED1.A, R21.2
unnamed: LED2.A, R22.2
unnamed: LED3.A, R23.2
unnamed: LED4.A, R24.2
unnamed: LED5.A, R25.2
unnamed: LED6.A, R26.2
unnamed: LED7.A, R27.2
unnamed: LED8.A, R28.2
unnamed: LED9.A, R29.2
unnamed: LED10.A, R30.2
unnamed: LED11.A, R31.2
unnamed: LED12.A, R32.2
unnamed: LED13.A, R33.2
unnamed: LED14.A, R34.2
unnamed: LED15.A, R35.2
unnamed: LED16.A, R36.2
NSEL: IC2.16 (PB2(SS/OC1B)), R7.1, R17.2, U$4.NSEL (/NSEL)
PC_CTS_IN: IC1.7 (T2OUT), X1.8 (F)
PC_RTS_OUT: IC1.8 (R2IN), X1.7 (F)
PC_RX_IN: IC1.14 (T1OUT), X1.2 (F)
PC_TX_OUT: IC1.13 (R1IN), X1.3 (F)
PMOSG: Q19.G, T1.1 (E), T2.1 (E)
RTS: IC1.10 (T2IN), IC2.4 (PD2(INT0))
RX: IC1.12 (R1OUT), IC2.2 (PD0(RXD))
SCK: IC2.19 (PB5(SCK)), R4.1, SV2.7
SHIFT_OE: IC2.24 (PC1(ADC1)), IC6.13 (G), IC7.13 (G), R12.1
SHIFT_RCK: IC2.25 (PC2(ADC2)), IC6.12 (RCK), IC7.12 (RCK)
SHIFT_SCK: IC2.26 (PC3(ADC3)), IC6.11 (SCK), IC7.11 (SCK)
SHIFT_SER: IC2.23 (PC0(ADC0)), IC6.14 (SER), R20.1
TX: IC1.11 (T1IN), IC2.3 (PD1(TXD))
V_BATT: D3.A, PWR_SW2.MP, R18.2, U$3.VIN

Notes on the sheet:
Power Switch
Battery
Key Switch

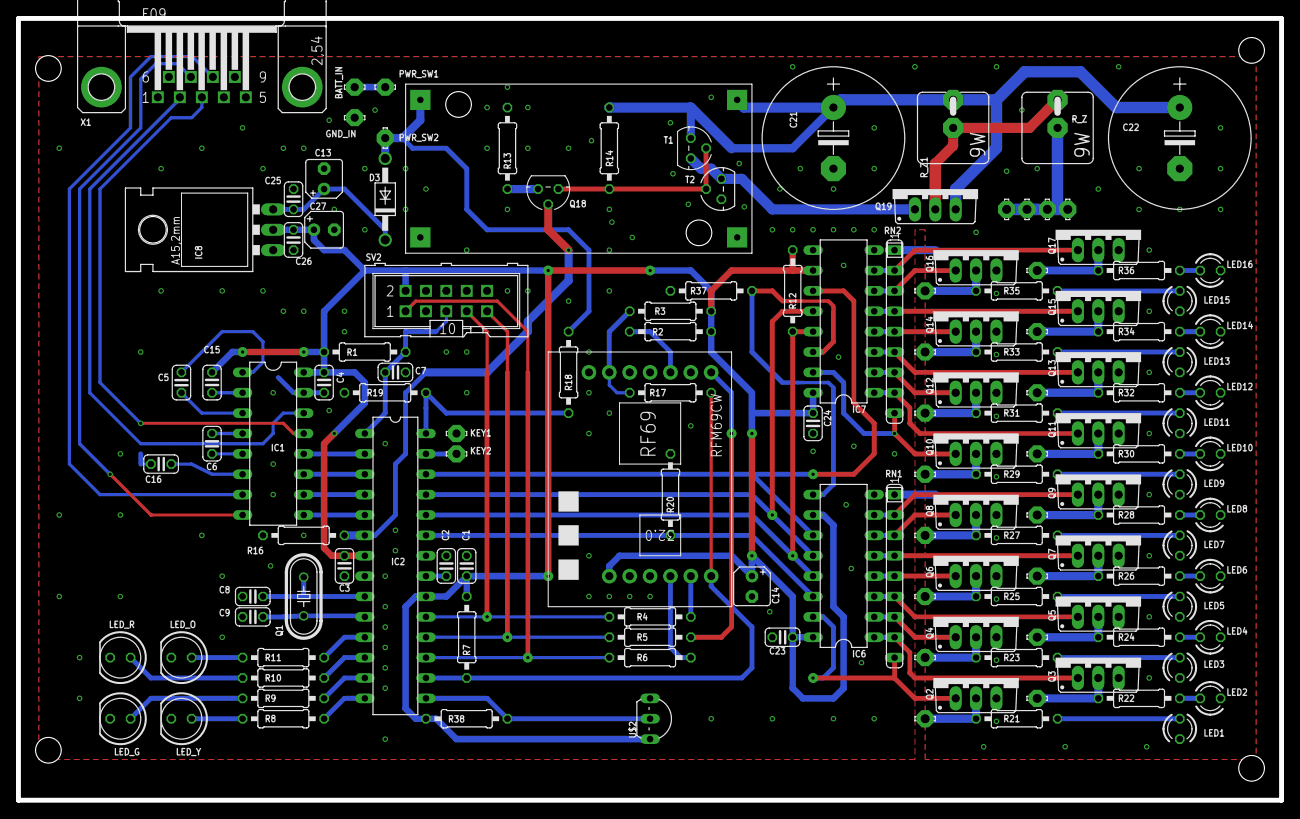
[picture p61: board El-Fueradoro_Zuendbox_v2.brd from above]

Board: 2 copper layers, 157.5 x 97.5 mm, 139 parts (0 on the bottom side), 103 nets.

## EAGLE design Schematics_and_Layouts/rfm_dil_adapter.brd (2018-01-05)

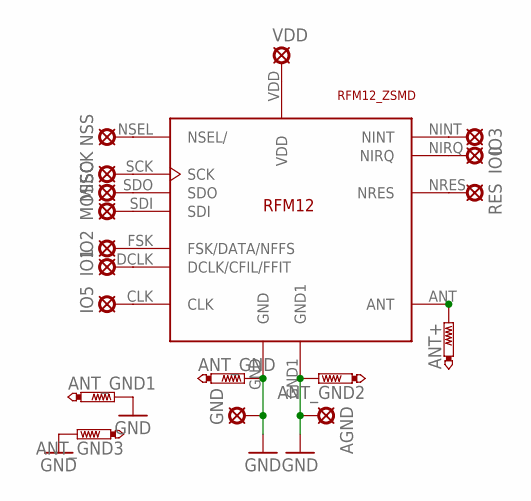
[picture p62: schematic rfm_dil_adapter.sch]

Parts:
AGND: LSP10
ANT+: PTR1TP20SQ; TP20SQ
ANT_GND, ANT_GND1, ANT_GND2, ANT_GND3: PTR1TP20SQ; TP20SQ
GND: LSP10
IO0, IO1, IO2, IO3, IO5: LSP10
MISO: LSP10
MOSI: LSP10
NSS: LSP10
RES: LSP10
SCK: LSP10
U$1: RFM12_ZSMD; RFM12_Z
VDD: LSP10

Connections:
ANT: ANT+.TP, U$1.ANT
GND: AGND.MP, ANT_GND.TP, ANT_GND1.TP, ANT_GND2.TP, ANT_GND3.TP, GND.MP, U$1.GND, U$1.GND1
unnamed: IO5.MP, U$1.CLK
unnamed: IO1.MP, U$1.DCLK (DCLK/CFIL/FFIT)
unnamed: IO2.MP, U$1.FSK (FSK/DATA/NFFS)
unnamed: MOSI.MP, U$1.SDI
unnamed: MISO.MP, U$1.SDO
unnamed: SCK.MP, U$1.SCK
unnamed: NSS.MP, U$1.NSEL (NSEL/)
unnamed: RES.MP, U$1.NRES
unnamed: IO0.MP, U$1.NIRQ
unnamed: IO3.MP, U$1.NINT
VDD: U$1.VDD, VDD.MP

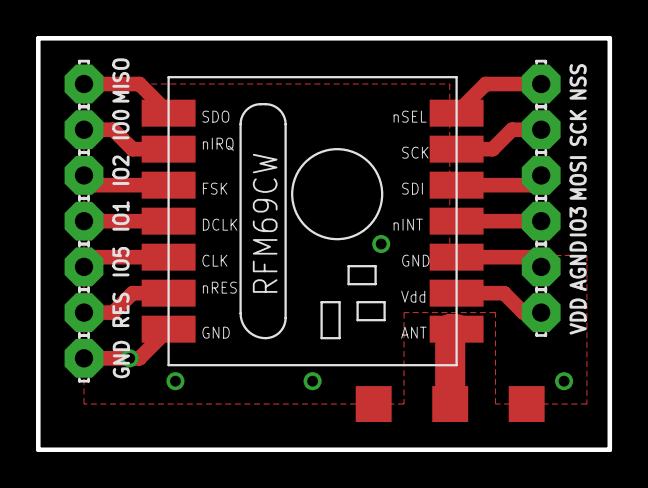
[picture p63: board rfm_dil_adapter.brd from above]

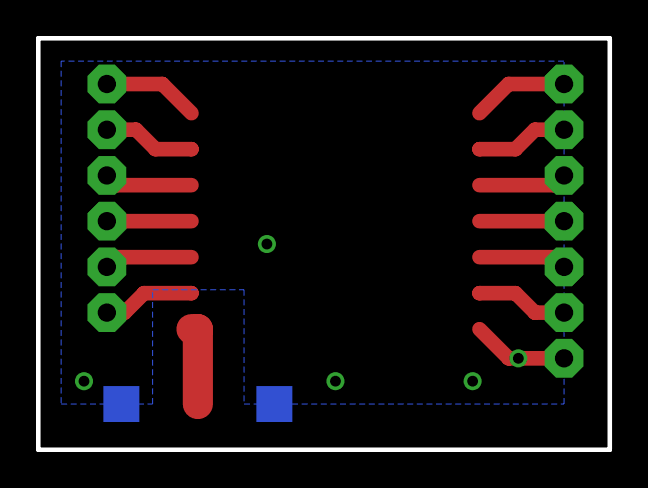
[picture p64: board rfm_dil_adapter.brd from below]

Board: 2 copper layers, 31.8 x 22.9 mm, 19 parts (2 on the bottom side), 13 nets.

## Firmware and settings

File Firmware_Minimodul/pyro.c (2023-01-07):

/*
 *           Firmware
 *         EL FUERADORO Mini Modul V1
 *
 *         Felix Pflaum
 *         Pascal Wollnitza
 *
 */

// Everything to be included is in global.h
#include "global.h"

// Global Variables
static volatile uint8_t  key_flag = 0, timer1_flags = 0, test_flag = 0, impedance_reset_ctr = 0;
static volatile int8_t   rssi_flag = 0;
static volatile uint8_t  channel_monitor = 0;
static volatile uint16_t transmit_flag   = 0;
static volatile uint32_t active_channels = 0;
static volatile uint16_t rx_timeout_ctr  = 0;


void wdt_init( void ) {
    MCUSR = 0;
    wdt_disable();
    return;
}

// Initialize Hall-Sensor
void hall_init( void ) {
    ARM_PORT |= ( 1 << ARM );
    ARM_DDR  &= ~( 1 << ARM );

    TEST_PORT |= ( 1 << TEST );
    TEST_DDR  &= ~( 1 << TEST );

    REED_PORT |= ( 1 << REED );
    REED_DDR  &= ~( 1 << REED );

    // Activate Pin-Change Interrupt
    PCICR      |= ( 1 << ARM_NUMERIC | 1 << TEST_NUMERIC | 1 << REED_NUMERIC );
    ARM_PCMSK  |= ( 1 << ARM );
    TEST_PCMSK |= ( 1 << TEST );
    REED_PCMSK |= ( 1 << REED );

    // Keep low-impedance path between ignition voltage and clamps closed
    MOSSWITCHPORT &= ~( 1 << MOSSWITCH );
    MOSSWITCHDDR  |= ( 1 << MOSSWITCH );
}

// Un-initialise Key-Switch (needed only if a device configured as ignition device gets configured as transmitter while on)
void key_deinit( void ) {
    ARM_PORT &= ~( 1 << ARM );
    ARM_DDR  &= ~( 1 << ARM );

    REED_PORT &= ~( 1 << REED );
    REED_DDR  &= ~( 1 << REED );

    TEST_PORT &= ~( 1 << TEST );
    TEST_DDR  &= ~( 1 << TEST );

    // Deactivate Pin-Change Interrupt
    PCICR     &= ~( 1 << ARM_NUMERIC );
    ARM_PCMSK &= ~( 1 << ARM );

    PCICR      &= ~( 1 << TEST_NUMERIC );
    TEST_PCMSK &= ~( 1 << TEST );

    PCICR      &= ~( 1 << REED_NUMERIC );
    REED_PCMSK &= ~( 1 << REED );
}


// ------------------------------------------------------------------------------------------------------------------------

// Talking to radio modules
uint8_t asciihex( char inp ) {
    inp |= 0x20;

    if ( ( inp >= '0' ) && ( inp <= '9' ) ) {
        return inp - '0';
    }

    if ( ( inp >= 'a' ) && ( inp <= 'f' ) ) {
        return inp - 'a' + 10;
    }

    return 255;
}

uint16_t rfmtalk( void ) {
    char          inp;
    unsigned char uinp, error;
    uint16_t      rfm_order = 0;

    error = 0;

    #if ( RFM == 69 )
        uart_puts( "\n\rKommando (16-Bit-Hex-Format, MSB zu 1 setzen für Schreibzugriff): 0x" );
    #else
        uart_puts( "\n\rKommando (16-Bit-Hex-Format): 0x" );
    #endif

    for ( uint8_t i = 4; i; i-- ) {
        rfm_order <<= 4;
        inp         = uart_getc();
        uart_putc( inp );
        uinp       = asciihex( inp );
        error     += ( uinp == 255 );
        rfm_order |= uinp;
    }

    if ( !error ) {
        return rfm_order;
    }
    else {
        return 0xFFFF;
    }
}

// ------------------------------------------------------------------------------------------------------------------------

// Temperature sensor detection
uint8_t tempident( void ) {
    uint8_t checkup = 0;

    for ( uint8_t i = 5; i; i-- ) {
        checkup += w1_reset();                         // In case of sensor connection w1_reset() will return 0
        checkup += !( ( W1_PIN & ( 1 << W1 ) ) && 1 ); // In case of sensor connection the right side will end up as 0
    }

    // Type of temp. sensor is detected by return value
    if ( !checkup ) {
        return DS18B20;
    }
    else {
        W1_DDR  &= ~( 1 << W1 );
        W1_PORT |= ( 1 << W1 );
        return 0;
    }
}

// Temperature measurement
int8_t tempmeas( uint8_t type ) {
    if ( !type ) {
        return -128;
    }
    else {
        int16_t  temperature;
        uint16_t temp_hex;

        w1_temp_conf( 125, -40, 9 );
        w1_command( CONVERT_T, NULL );

        uint32_t utimer = F_CPU / 128;

        while ( --utimer && !w1_bit_io( 1 ) );

        w1_command( READ, NULL );
        temp_hex    = w1_byte_rd();
        temp_hex   += ( w1_byte_rd() ) << 8;
        temperature = w1_tempread_to_celsius( temp_hex, 0 );

        return (int8_t)temperature;
    }
}

// ------------------------------------------------------------------------------------------------------------------------

// Check if received uart-data are a valid ignition command
uint8_t fire_command_uart_valid( const char *field ) {
    return ( field[0] == 0xFF ) && ( field[1] > 0 ) && ( field[1] <= MAX_ID ) && ( field[2] > 0 ) && ( field[2] < ( FIRE_CHANNELS + 1 ) )
           && ( field[3] == crc8( crc8( 0, field[1] ), field[2] ) );
}

// ------------------------------------------------------------------------------------------------------------------------

// Main programme
int main( void ) {

    HOLD_ON_PORT |= ( 1 << HOLD_ON );
    HOLD_ON_DDR  |= ( 1 << HOLD_ON );

    // _delay_ms(1500);

    wdt_disable();
    MOSSWITCHPORT &= ~( 1 << MOSSWITCH );
    MOSSWITCHDDR  |= ( 1 << MOSSWITCH );

    // Local Variables
    uint32_t scheme = 0, anti_scheme = 0, controlvar = 0, chPattern = 0, chIdentifier[FIRE_CHANNELS] = { 0 };
    uint8_t  iii, nr, inp, tmp;
    uint8_t  tx_length = 2, rx_length = 0;
    uint8_t  rfm_rx_error = 0, rfm_tx_error = 0;
    uint8_t  rxState = 0, rxStateOld = 0, squelch_setting;
    uint8_t  debounce_reed_ctr = 0, debounce_arm_ctr = 0, debounce_test_ctr = 0;
    uint8_t  debounce_current_state = 0;
    uint8_t  debounce_old_state = 0;
    uint8_t  debounce_active = ( 1 << DEBOUNCE_DEVS ) - 1, debounce_mask = 0;
    uint8_t  temp_sreg;
    uint8_t  slave_id = MAX_ID, unique_id = MAX_ID, rem_sid = MAX_ID, rem_uid = MAX_ID;
    uint8_t  loopcount = 5, transmission_allowed = 1;
    uint8_t  armed       = 0;
    uint8_t  changes     = 0;
    uint8_t  iderrors    = 0;
    uint8_t  rssi        = -128;
    uint8_t  ledscheme   = 0;
    int8_t   temperature = -128;
    uint8_t  ignition_time;
    uint8_t  ign_time_backup;
    uint8_t  rfm_timeoutlength_short, rfm_timeoutlength_long;
    uint8_t  squelchadjust = 1;

    uint8_t hall_arm = 0, reed_deb = 0, test_deb = 0;

    bitfeld_t flags;
    flags.complete = 0;
    uint32_t statusleds = 0;

    char        uart_field[MAX_COM_ARRAYSIZE + 2] = { 0 };
    char        rx_field[MAX_COM_ARRAYSIZE + 1]   = { 0 };
    char        tx_field[MAX_COM_ARRAYSIZE + 1]   = { 0 };
    char        quantity[MAX_ID + 1]              = { 0 };
    fireslave_t slaves[MAX_ID + 1];
    uint8_t     impedances[FIRE_CHANNELS]      = { 0 };
    uint8_t     channel_timeout[FIRE_CHANNELS] = { 0 };
    uint8_t     rf_frequency[ 3 ] = { 0, 0, 0 };

    char transmission_type;

    uint8_t          *debounce_ctr[ DEBOUNCE_DEVS ]       = { &debounce_reed_ctr,   &debounce_arm_ctr,   &debounce_test_ctr };
    volatile uint8_t *debounce_pin[ DEBOUNCE_DEVS ]       = { &REED_PIN, &ARM_PIN, &TEST_PIN };
    const uint8_t     debounce_num[ DEBOUNCE_DEVS ]       = { 1 << REED, 1 << ARM, 1 << TEST };
    const uint8_t     debounce_minCycles[ DEBOUNCE_DEVS ] = { 50, 100, 30 };
    uint8_t          *debounce_results[ DEBOUNCE_DEVS ]   = { &reed_deb, &hall_arm, &test_deb };


    /* For security reasons the shift registers are initialized right at the beginning to guarantee a low level at the
     * gate pins of the MOSFETs and beware them from conducting directly after turning on the device.
     *
     * The SIPO-registers 74HC595 providing the 16 channels for ignition internally possess a shift register and
     * an output register. Into the latter data from the shift register are transferred by a rising edge at the RCLOCK-pin.
     * This leads to the situation that changes within the shift register are only visible at the outputs after a rising
     * edge at the RCLOCK-pin.
     *
     * As soon as the PIN /OE (Inverted output enable) is pulled low, the outputs are enabled. The problem is that the initial
     * output states are random and cannot be predicted nor controlled. The available "Master Reset" does only affect the internal
     * shift register but has no influence on the outputs unless a rising edge at RCLOCK happens.
     *
     * To guarantee a defined power-on-state the /OE-pin needs to be pulled high until all 16 channels are set to low and
     * written into the output register. Therefore an external pullup-resistor is connected to /OE which makes the outputs tri-state.
     * Additional pulldown-resistor-arrays pull the shift register outputs to "low". Only after 16 zeros have been clocked into the
     * shift register and its values have been written to the output registers /OE may be set to "low".
     *
     * Therefore it is strcitly recommended not to change sr_init() and to call sr_init() immediately as the first function right at
     * the beginning of the main-programme. sr_init() takes care of a safe start for the ignition devices and doesn't do any harm to
     * the transmitter.
     *
     */
    sr_init();
    _delay_ms( 10 );

    // Disable unused controller parts (2-wire-Interface, Timer 2, Analogue Comparator)
    PRR  |= ( 1 << PRTWI ) | ( 1 << PRTIM2 );
    ACSR |= 1 << ACD;

    // Initialise Timer
    timer1_init();
    timer1_on();

    // Initialise LEDs
    led_init();

    // Initialise ADC
    adc_init();

    // Get Slave- und Unique-ID from EEPROM for ignition devices
    update_addresses( &unique_id, &slave_id );

    // Change values and restart in case an ID is 0
    if ( !unique_id || !slave_id ) {
        if ( !unique_id ) {
            unique_id = MAX_ID;
        }

        if ( !slave_id ) {
            slave_id = MAX_ID;
        }

        addresses_save( unique_id, slave_id );
        wdt_enable( 6 );

        while ( 1 );
    }

    // Make sure, ignition time is properly defined and set ignition time
    ignition_time = eeread( FIRE_DURATION_ADDRESS );
    if ( ( ignition_time != TALON_TIME ) && ( ignition_time != FLAMER_TIME ) && ( ignition_time != EMATCH_TIME ) ) {
        eewrite( EMATCH_TIME, FIRE_DURATION_ADDRESS );
        ignition_time = EMATCH_TIME;
    }

    // Initialise arrays
    for ( uint8_t warten = 0; warten < MAX_COM_ARRAYSIZE; warten++ ) {
        uart_field[warten] = 1;
        tx_field[warten]   = 0;
        rx_field[warten]   = 0;
    }

    for ( uint8_t warten = 0; warten < MAX_ID; warten++ ) {
        slaves[warten].slave_id        = 0;
        slaves[warten].battery_voltage = 0;
        slaves[warten].sharpness       = 0;
        slaves[warten].temperature     = -128;
        slaves[warten].rssi            = -128;
        slaves[warten].squelch         = 0;
    }

    // Populate channel pattern array:
    // chIdentifier[ i ] = 1 << i
    uint32_t chMsk = 1UL << ( FIRE_CHANNELS - 1 );
    for ( uint8_t i = FIRE_CHANNELS; i; i-- ) {
        chIdentifier[ i - 1 ] = chMsk;
        chMsk               >>= 1;
    }

    // Initialise devices
    hall_init();
    leds_off();

    // Initialise UART
    uart_init( BAUD );

    // Detect temperature sensor and measure temperature if possible
    const uint8_t tempsenstype = tempident();
    temperature = tempmeas( tempsenstype );

    // Initialise radio
    const uint8_t rfm_fail = rfm_init();

    for(uint8_t ct = 0; ct < 3; ct++ ) {
        rf_frequency[ ct ] = rfm_cmd(0x0700 + 256 * ct, 0);
    }

    // Set encryption active, read and transfer AES-Key
    rfm_cmd( 0x3D00 | rfm_cmd( 0x3DFF, 0 ) | 0x01, 1 );
    for ( uint8_t i = 0; i < 16; i++ ) {
        rfm_cmd( ( 0x3E00 + i * ( 0x0100 ) ) | eeread( START_ADDRESS_AESKEY_STORAGE + i ), 1 );
    }

    rfm_timeoutlength_short = ( RFM_SHORT_LENGTH + rfm_cmd( 0x2DFF, 0 ) + ( ( ( rfm_cmd( 0x2EFF, 0 ) & 0x38 ) >> 3 ) + 1 ) + 4 ) >> 1;
    rfm_timeoutlength_long  = ( RFM_LONG_LENGTH + rfm_cmd( 0x2DFF, 0 ) + ( ( ( rfm_cmd( 0x2EFF, 0 ) & 0x38 ) >> 3 ) + 1 ) + 4 ) >> 1;

    // Display slave ID
    leds_off();
    _delay_ms( 150 );
    sr_shiftout( mask_led );
    led_yellow_on();
    _delay_ms( 150 );
    led_green_on();
    _delay_ms( 150 );
    led_orange_on();
    _delay_ms( 150 );
    led_red_on();
    _delay_ms( 150 );
    leds_off();
    _delay_ms( 250 );
    ledscheme = ( slave_id & 0xF0 ) >> 4;

    if ( ledscheme & 0x01 ) {
        led_yellow_on();
    }

    if ( ledscheme & 0x02 ) {
        led_green_on();
    }

    if ( ledscheme & 0x04 ) {
        led_orange_on();
    }

    if ( ledscheme & 0x08 ) {
        led_red_on();
    }

    _delay_ms( 2000 );
    leds_off();
    _delay_ms( 250 );
    led_red_on();
    _delay_ms( 150 );
    led_orange_on();
    _delay_ms( 150 );
    led_green_on();
    _delay_ms( 150 );
    led_yellow_on();
    _delay_ms( 150 );
    leds_off();
    _delay_ms( 250 );
    ledscheme = ( slave_id & 0x0F );

    if ( ledscheme & 0x01 ) {
        led_yellow_on();
    }

    if ( ledscheme & 0x02 ) {
        led_green_on();
    }

    if ( ledscheme & 0x04 ) {
        led_orange_on();
    }

    if ( ledscheme & 0x08 ) {
        led_red_on();
    }

    _delay_ms( 2000 );
    sr_shiftout( 0 );
    leds_off();
    _delay_ms( 200 );

    armed = !( ( ARM_PIN & ( 1 << ARM ) ) && 1 );

    if ( armed ) {
        led_red_on();
    }
    else {
        led_red_off();
    }

    flags.b.clear_list = 1;
    tx_field[0]        = PARAMETERS;
    tx_field[1]        = unique_id;
    tx_field[2]        = slave_id;
    tx_field[3]        = bat_calc( 5 );
    tx_field[4]        = armed;
    tx_field[5]        = temperature;
    tx_field[6]        = FIRE_CHANNELS;
    tx_field[7]        = rssi;
    tx_field[8]        = rfm_cmd( 0x2900, 0 ) >> 1;

    flags.b.transmit       = 1;
    flags.b.read_impedance = 1;
    test_flag              = 1;
    transmission_type      = PARAMETERS;
    key_flag               = 1;

    // Enable Interrupts
    sei();

    // Main loop

    /*
     * Within the main loop the status of all the flags is continuously monitored and upon detection of a set flag
     * the corresponding routine is executed. Before the execution of the routine the status register is written to a local
     * variable, interrupts are disabled and the flag gets cleared, after the routine interrupts are re-enabled
     *
     */
    while ( 1 ) {
        // -------------------------------------------------------------------------------------------------------

        // Control key switch (key_flag gets set via pin-change-interrupt)
        if ( key_flag ) {
            temp_sreg = SREG;
            cli();

            switch ( key_flag ) {
                case 1: {
                    // Prepare for debouncing by setting
                    for ( uint8_t i = 0; i < DEBOUNCE_DEVS; i++ ) {
                        *( debounce_ctr[ i ] ) = 0;
                    }
                    debounce_active = ( 1 << DEBOUNCE_DEVS ) - 1;
                    key_flag        = 2;
                    break;
                }
                case 2: {
                    if ( timer1_flags & TIMER_DEBOUNCE_FLAG ) {
                        timer1_flags          &= ~TIMER_DEBOUNCE_FLAG;
                        debounce_mask          = 1;
                        debounce_current_state = 0;
                        for ( uint8_t i = 0; i < DEBOUNCE_DEVS; i++ ) {

                            if ( debounce_active & debounce_mask ) {
                                // Get current state and save it at the correct bit position (debounce_mask)
                                debounce_current_state |= ( ( *( debounce_pin[ i ] ) & ( debounce_num[ i ] ) ) && 1 ) * debounce_mask;

                                // Step counter if there was no change from previous readout, otherwise reset counter
                                if ( ( debounce_current_state & debounce_mask ) ^ ( debounce_old_state & debounce_mask ) ) {
                                    *( debounce_ctr[ i ] ) = 0;
                                }
                                else {
                                    ( *( debounce_ctr[ i ] ) )++;
                                }

                                // If the predefined number of consecutive equal states is reached, set the result
                                if ( ( *( debounce_ctr[ i ] ) ) > debounce_minCycles[ i ] ) {
                                    debounce_active             &= ~debounce_mask;                                       // Declare this device finished
                                    ( *( debounce_results[i] ) ) = !( ( debounce_current_state & debounce_mask ) && 1 ); // Result = 1 if all-0, 0 if all-1
                                                                                                                         // (active low)
                                }
                            }

                            debounce_mask <<= 1;
                        }
                        debounce_old_state = debounce_current_state;

                        // Evaluate after debouncing
                        if ( !debounce_active ) {
                            key_flag = 0;

                            if ( test_deb ) {
                                flags.b.read_impedance = 1;
                            }

                            if ( hall_arm ) {
                                armed ^= 1;
                            }

                            if ( armed ) {
                                led_red_on();
                                // Turn off channel leds (if not turned off already anyway)
                                sr_shiftout( 0 );
                            }
                            else {
                                MOSSWITCHPORT &= ~( 1 << MOSSWITCH );
                                led_red_off();
                            }

                            if ( reed_deb && !armed ) {
                                flags.b.shutdown = 1;
                            }
                        }
                    }

                    break;
                }
                default: {
                    key_flag = 0;
                    break;
                }
            }

            SREG = temp_sreg;
        }

        // -------------------------------------------------------------------------------------------------------

        if ( rfm_fail ) {
            led_green_on();
            led_orange_on();
        }

        // -------------------------------------------------------------------------------------------------------

        // UART-Routine
        flags.b.uart_active = ( ( UCSR0A & ( 1 << RXC0 ) ) && 1 );

        if ( flags.b.uart_active ) {
            temp_sreg = SREG;
            cli();
            flags.b.uart_active = 0;

            led_yellow_on();

            // Receive first char
            uart_field[0] = uart_getc();

            // React according to first char (ignition command or not?)
            // Ignition command is always 4 chars long
            switch ( uart_field[0] ) {
                case 0xFF: {
                    uart_field[1] = uart_getc();
                    uart_field[2] = uart_getc();
                    uart_field[3] = uart_getc();
                    uart_field[4] = '\0';
                    break;
                }

                // Any other command is received as long as it doesn't start with enter or backspace
                case 8:
                case 10:
                case 13:
                case 127: {
                    uart_field[0] = '\0';
                    break;
                }

                default: {
                    #if !CASE_SENSITIVE
                        uart_field[0] = uart_lower_case( uart_field[0] );
                    #endif
                    uart_putc( uart_field[0] ); // Show first char so everything looks as it should

                    if ( !uart_gets( uart_field + 1 ) ) {
                        uart_puts_P( PSTR( "\033[1D" ) );
                        uart_puts_P( PSTR( " " ) );
                        uart_puts_P( PSTR( "\033[1D" ) );
                        uart_field[0] = '\0';
                    }

                    break;
                }
            }

            // Evaluate inputs
            // "conf" starts ID configuration
            if ( uart_strings_equal( uart_field, "conf" ) ) {
                flags.b.uart_config = 1;
                flags.b.transmit    = 0;
            }

            // "remote" starts remote ID configuration
            if ( uart_strings_equal( uart_field, "remote" ) ) {
                flags.b.remote   = 1;
                flags.b.transmit = 0;
            }

            // "clearlist" empties list of boxes
            if ( uart_strings_equal( uart_field, "clearlist" ) ) {
                flags.b.clear_list = 1;
            }

            // "send" allows to manually send a command
            if (  uart_strings_equal( uart_field, "send" ) || uart_strings_equal( uart_field, "fire" )
               || uart_strings_equal( uart_field, "ident" ) || uart_strings_equal( uart_field, "temp" ) ) {
                flags.b.send     = 1;
                flags.b.transmit = 0;
            }

            // "list" gives an overview over connected boxes
            if ( uart_strings_equal( uart_field, "list" ) ) {
                flags.b.list     = 1;
                flags.b.transmit = 0;
            }

            // "imp" measures and lists local impedances
            if ( uart_strings_equal( uart_field, "imp" ) ) {
                flags.b.read_impedance = 1;
                flags.b.list_impedance = 1;
            }

            // "cls" clears terminal screen
            if ( uart_strings_equal( uart_field, "cls" ) ) {
                terminal_reset();
            }

            // "kill" resets the controller
            if ( uart_strings_equal( uart_field, "kill" ) ) {
                flags.b.reset_device = 1;
            }

            // "shutdown" shuts down the device
            if ( uart_strings_equal( uart_field, "shutdown" ) ) {
                flags.b.shutdown = 1;
            }
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

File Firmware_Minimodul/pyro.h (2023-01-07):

/*
 * pyro.h
 *
 *  Created on: 10.07.2013
 *      Author: Felix
 */



#ifndef PYRO_H_
#define PYRO_H_

// Switches' location
#define ARMPORT			D
#define ARMNUM			2

#define TESTPORT		D
#define TESTNUM			4

#define REEDPORT		D
#define REEDNUM			3

#define HOLDPORT		C
#define HOLDNUM			0	

//
#define MOSSWITCH_PORT        C
#define MOSSWITCH_NUM         2

// Ignition time * 10ms
#define EMATCH_TIME           2
#define FLAMER_TIME           35
#define TALON_TIME            245

// Main clock frequency
#ifndef F_CPU
    #define F_CPU             11059200UL
#endif
// Maximum ID
#ifndef MAX_ID
    #define MAX_ID            30
#endif

#define DEBOUNCE_DEVS         3
#define T0_PRELOAD_VALUE      (256ULL - ((10ULL * F_CPU + 512000ULL) / 1024000ULL))
// Maximum Array Size for communication (UART + radio)
#define MAX_COM_ARRAYSIZE     40

// Ignition time * 10ms
#define RFM_SHORT_LENGTH      16
#define RFM_LONG_LENGTH       48

// Threshold to clear LCD (Number of counter overflows)
#define DEL_THRES             251

// Value for input timeout
#define TIMEOUTVAL            ( F_CPU >> 4 )

// Radio message types
#define   CHANGE              'c'
#define   ERROR               'e'
#define   FIRE                'f'
#define   FREQCHANGE          'h'
#define   IDENT               'i'
#define   MEASURE             'm'
#define   NEWFREQ             'n'
#define   PARAMETERS          'p'
#define   TEMPERATURE         't'
#define   RSSITHRESHOLD       'r'
#define   SQUELCHADJUST       's'
#define   IMPEDANCES          'z'
#define   IDLE                0

// Ceiled duration of byte transmission in microseconds
#define   BYTE_DURATION_US    ( 8 * ( 1000000UL + BR ) / BR )

#define   setTxCase( XX ) case XX: { loopcount = XX ## _REPEATS; tmp = XX ## _LENGTH - 1; break; }
#define   waitRx( XX )    for ( uint8_t i = rx_field[rx_length - 1] - 1; i; i-- ) _delay_us ( ( ADDITIONAL_LENGTH + ((XX ## _LENGTH)/16 + 1 * (((XX ## _LENGTH)%16) && 1))*16 ) * BYTE_DURATION_US + (500000/BR + 1) + 5005 + (5*RFM_RAMP_UP/4))

// Radio message lengths
#define   ADDITIONAL_LENGTH    12    // Preamble (4) + Passwort (2) + Length Byte (1) + CRC (2) + Spare
#define   FIRE_LENGTH          4
#define   IDENT_LENGTH         4
#define   MEASURE_LENGTH       4
#define   PARAMETERS_LENGTH    10
#define   TEMPERATURE_LENGTH   5
#define   CHANGE_LENGTH        6
#define   RSSITHRESHOLD_LENGTH 2
#define   SQUELCHADJUST_LENGTH 2
#define   FREQCHANGE_LENGTH    9
#define   NEWFREQ_LENGTH       6
#define   IMPEDANCES_LENGTH    (4+FIRE_CHANNELS)

// Number of repetitions for radio messages
#define   FIRE_REPEATS          3
#define   RSSITHRESHOLD_REPEATS 5
#define   SQUELCHADJUST_REPEATS 5
#define   IDENT_REPEATS         3
#define   CHANGE_REPEATS        3
#define   PARAMETERS_REPEATS    2
#define   TEMPERATURE_REPEATS   2
#define   MEASURE_REPEATS       2
#define   IMPEDANCES_REPEATS    2
#define   NEWFREQ_REPEATS       2
#define   FREQCHANGE_REPEATS    2

// Bitflags
typedef union {
    struct {
        unsigned uart_active    : 1;
        unsigned uart_config    : 1;
        unsigned fire           : 1;
        unsigned finish_firing  : 1;
        unsigned is_fire_active : 1;
        unsigned send           : 1;
        unsigned transmit       : 1;
        unsigned receive        : 1;
        unsigned list           : 1;
        unsigned read_impedance : 1;
        unsigned list_impedance : 1;
        unsigned reset_device   : 1;
		unsigned shutdown		: 1;
        unsigned clear_list     : 1;
        unsigned hw             : 1;
        unsigned remote         : 1;
    }        b;
    uint16_t complete;
} bitfeld_t;

typedef struct {
    uint8_t slave_id;
    uint8_t battery_voltage;
    uint8_t sharpness;
    int8_t  temperature;
    uint8_t channels;
    uint8_t rssi;
    uint8_t squelch;
} fireslave_t;

#define ARM_DDR                      DDR( ARMPORT )
#define ARM_PIN                      PIN( ARMPORT )
#define ARM_PORT                     PORT( ARMPORT )
#define ARM_NUMERIC                  NUMPORT( ARMPORT )
#define ARM                          ARMNUM
#define ARM_PCMSK					 PCMSK( ARM_NUMERIC )
#define ARM_PCINTVECT                PCINTVECT( ARM_NUMERIC )

#define TEST_DDR                      DDR( TESTPORT )
#define TEST_PIN                      PIN( TESTPORT )
#define TEST_PORT                     PORT( TESTPORT )
#define TEST_NUMERIC                  NUMPORT( TESTPORT )
#define TEST                          TESTNUM
#define TEST_PCMSK		     		  PCMSK( TEST_NUMERIC )
#define TEST_PCINTVECT                PCINTVECT( TEST_NUMERIC )

#define REED_DDR                      DDR( REEDPORT )
#define REED_PIN                      PIN( REEDPORT )
#define REED_PORT                     PORT( REEDPORT )
#define REED_NUMERIC                  NUMPORT( REEDPORT )
#define REED                          REEDNUM
#define REED_PCMSK					  PCMSK( REED_NUMERIC )
#define REED_PCINTVECT                PCINTVECT( REED_NUMERIC )

#define HOLD_ON_DDR                   DDR( HOLDPORT )
#define HOLD_ON_PIN                   PIN( HOLDPORT )
#define HOLD_ON_PORT                  PORT( HOLDPORT )
#define HOLD_ON_NUMERIC               NUMPORT( HOLDPORT )
#define HOLD_ON                       HOLDNUM


#define MOSSWITCHDDR                 DDR( MOSSWITCH_PORT )
#define MOSSWITCHPIN                 PIN( MOSSWITCH_PORT )
#define MOSSWITCHPORT                PORT( MOSSWITCH_PORT )
#define MOSSWITCH                    MOSSWITCH_NUM

// ID storage settings for EEPROM
#define START_ADDRESS_ID_STORAGE     24
#define STEP_ID_STORAGE              36
#define CRC_ID_STORAGE               16
#define ID_MESS                                                                                               \
    !( eeread( START_ADDRESS_ID_STORAGE )                                                                     \
       == eeread( START_ADDRESS_ID_STORAGE + STEP_ID_STORAGE ) )                                              \
    && ( eeread( START_ADDRESS_ID_STORAGE ) == eeread( START_ADDRESS_ID_STORAGE + 2 * STEP_ID_STORAGE ) )     \
    && ( eeread( START_ADDRESS_ID_STORAGE + 1 ) == eeread( START_ADDRESS_ID_STORAGE + 1 + STEP_ID_STORAGE ) ) \
    && ( eeread( START_ADDRESS_ID_STORAGE + 1 ) == eeread( START_ADDRESS_ID_STORAGE + 1 + 2 * STEP_ID_STORAGE ) )

// Temperature Sensors
#define DS18B20                      'o'

#define START_ADDRESS_AESKEY_STORAGE 32
#define FIRE_DURATION_ADDRESS        365

// Externally used fuctions
uint8_t asciihex( char inp );

#endif /* PYRO_H_ */

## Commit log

2014-05-15 Improved shiftout-function Kicked out look-up-table for shift-out-values (replaced by for-loop)
    [pyro.c]
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2014-05-16 Synchronized rfm-software-spi. Changed Pin-Toggle-Commands to direct assignment, removed "or". Cleaned up global.h, moved some definitions to pyro.h
2014-05-26 Removed El-Fueradoro-specific things from UART-library, shifted it to pyro.c/pyro.h Translated rfm-libraries
2014-05-26 Translated a big part of the main programme's comments. Changed type of uart_gets()-Function from void to uint8_t, it returns number of received chars now.
2014-05-27 Fixed "additional space"-error displaying voltage on LCD. Changed variables to unsigned integer in LCD-functions.
    [lcd.h, pyro.c]
2014-05-28 Made UART pins freely configurable (no soft-UART implemented yet though). Changed config-prog output on screen.
    Updated Hexfiles.
2014-05-28 Inserted optical emphasis for wrong IDs
    Updated Hexfiles
    [terminal.c]
2014-05-29 RFM12-timeouts adapted (were way too long to keep it going after accidential receive) LCD should now show all received commands
    Hexfiles updated
    [pyro.c]
2014-05-30 Added transmission after transmitter-initialisation for frequency adjustment Improved error detection for DHT22/AM2302 Reset AFC-settings for RFM69 to default
    Updated Hexfiles accordingly
    [pyro.c, rfm69.c]
2014-05-30 Fixed bug concerning permanent display during inactiveness.
    Updated Hexfiles as always
    [pyro.c]
2014-07-26 Some changes in the 1-Wire-temperature-library without impact on the actual programme.
2014-07-28 Added option to turn flow control on/off for UART-communication.
    Updated hexfiles.
2014-07-29 Added remote temperature measurement trigger. Changed building-batch to avoid error messages.
    [pyro.c, pyro.h]
2014-08-07 Changed error tracing methods in RFM-routines
    [pyro.c, rfm69.c, rfm69.h]
2014-08-07 Some fixes compared to last commit. Everything tested and working fine.
    [rfm69.c, rfm69.h]
2014-08-07 Small but important change in rfm12.c: controller now only tries to use hardware-spi if it's really available.
2014-08-28 Corrected a mistake - wrong index.
    [pyro.c]
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2014-09-25 Added option to trigger ignition device directly from the serial port, so no transmitter would be needed.
2014-09-25 Had screwed up with brackets in the last version.
2014-09-26 New feature: sole transmitter not compulsory anymore, every ignition device - as long as it's connected to COM-port can take over transmitter duties and still work as ignition device.
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2014-09-26 Some fixes concerning language - comments should be all English. Corrected LED-ports back to original setting. Optimized serial interface.
    [leds.h, pyro.c, terminal.c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]
2014-09-29 Fixed LED port assignments. Got new timer solution for answer delay working.
    [pyro.c]
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2014-10-04 Some changes after extensive testing of RFM69 ignition device.
2014-10-23 New ADC-calculation routine. Now works correctly for old and new ignition devices without the need of changing the voltage divider hardware.
    [adc.c]
2014-11-23 Fixed some RFM69-related stuff. Fixed LCD-display concerning temperature measurement Fixed box-listing-issue (no more incrementing on every listing)
    [pyro.c, pyro.h, rfm69.c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]
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2014-11-25 Some fixes in rfm69.c after some testing. Organized boxes listing themselves.
    [pyro.c, rfm69.c]
2014-11-25 Now all LEDs go on during ignition and are set to their previous status afterwards.
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2014-11-26 Changes in the manual Temperature command gets shown properly on LCD Some cosmetic stuff
2014-11-27 Cleaned up code for manual transmission. Multiple ignition of the same channel not possible any more when ignition box is connected to serial cable.
2014-12-29 Fixed Hardware-SPI-problem which was due to double usage of identical variables for RFM12 and RFM69.
    [rfm69.c, rfm69.h]
2014-12-31 Replaced HARDWARE_SPI by HARDWARE_SPI_69 and HARDWARE_SPI_12 respectively during initialization. Reduced SPI-frequency.
    [rfm69.c]
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2015-01-01 Only allowing remote reconfiguration of device numbers when device is not armed
2015-01-01 Corrected wrong ID-order and unified ID-order in other cases to unique before slave
    [pyro.c]
2015-01-02 Bugfixes and manual update
    [pyro.c]
2015-01-03 Trying to get rid of identification errors + memory usage optimization
    [pyro.c, terminal.c]
2015-01-06 Omitting AFC Fixing issue of slow restart when not connected to terminal program Setting uart-timeout to realistic value Added confirmation-dialogue to remote ID-update Further bugfixes and cosmetic 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
    [pyro.c, rfm69.c, rfm69.h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]
2015-01-06 Manual update. More efficient number display for UART.
2015-01-07 Rx-Tweak for RFM69 to avoid deadlocks
    [rfm69.c]
2015-01-08 Found and implemented a way to find out if connected device is a transmitter or a ignition box. Now it should be impossible to configure a ignition box as transmitter.
2015-01-09 Added security features and device-type-display in configuration routine.
2015-01-09 ADC-deinit added, should fix LCD problems upon restart.
    [adc.c, pyro.c]
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2015-01-12 Code cleanup and delay correction. Could be a milestone version...
    [pyro.c, pyro.h, terminal.c]
2015-01-13 RFM can now be read out via UART (especially interesting for RFM69)
2015-01-15 Big manual update! Some adjustments in update-software to avoid crashes. Reducing of screen-output messages to save memory.
    [pyro.c]
2015-01-16 Added EAGLE files!
    [El-Fueradoro_Transmitter.brd, El-Fueradoro_Transmitter.sch, El-Fueradoro_Zuendbox.brd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]
2015-01-18 Added bill of materials
    [BOM.ods, El-Fueradoro_Transmitter.brd, El-Fueradoro_Transmitter.sch]
2015-01-19 Added part numbers to BOM.ods
    [BOM.ods]
2015-01-20 Added size-information-output for Hexfiles/build_hexfiles.bat Extended manual and added BOMs BOM-Update (final one, hopefully!)
    [BOM.ods, El-Fueradoro_Transmitter.brd, El-Fueradoro_Transmitter.sch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]
2015-01-21 Huge manual update! Still layouts have to be changed due to redundant radio module pin.
2015-01-21 Layout fixes Additions to manual once again
    [El-Fueradoro_Transmitter.brd, El-Fueradoro_Transmitter.sch, El-Fueradoro_Zuendbox.brd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]
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2015-01-29 Ladies and Gentlemen, we have a GUI! To check it out, the newest firmware has to be flashed on every device first!
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2015-02-16 Added standard eeprom-file and changed bootloader-flasher accordingly. Changed board layout to ease drilling. Some manual update.
    [El-Fueradoro_Zuendbox.brd]
2015-02-21 Drill distance adjusted, layouts up to date
    [El-Fueradoro_Zuendbox.brd]
2015-04-04 Fixed errors in BOM Introducing receiver restart after erratic preamble match
    [pyro.c, pyro.h, rfm69.c]
2015-04-08 Added missing chip-selection Improved bandwidth-related settings
    [rfm69.c]
2015-04-12 Optimized RSSI-threshold for RFM69 Corrected cable lengths in the manual
    [rfm69.c]
2015-04-26 Corrected faulty LED-blinking for unarmed boxes Armed status is checked upon receiving of fire-command
    New manual structure
    New pictures for conf and list
    [pyro.c]
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2015-06-09 Added compatibility comment to rfm69.c Manual updated and a bit more error corrected
    [rfm69.c]
2015-08-07 Added first descriptions for case-modding to manual Removed rat-race-condition from 1-Wire-Library Temperature sensor detection improved Added compiler option for smaller hexfiles
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2015-11-09 1-wire-timing corrected
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2015-11-18 Sourcecode beautification Added disabling of shift-registers before reset Manual updated Updated hexfiles
    [1wire.h, adc.c]
2015-11-22 1-wire-fix in unused function, not really relevant for system Code-translation and beautification
    [pyro.c]
2015-12-01 Option to use hardware-spi with shift register added
2015-12-01 Added missing newline in manual sending routine
    [pyro.c]
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2015-12-02 Reset transmission power to 8 dBm Hexfiles updated Manual layout improved
    [rfm69.h]
2015-12-03 Created a high-power-version of the Atmega328p-RFM69-firmware, where 13 dBm is the standard output power of the radio module.
    Manual updated and reformatted
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2015-12-29 Update pyro.c
    Wrong blinking sequence fixed
    [pyro.c]
2016-03-17 Changed while-condition order to guarantee for proper timeouts (C shortcut-evaluation)
    [rfm69.c, uart.c]
2016-03-17 Added windows-update-gui to manual Some more "shortcut evaluation"-driven changes
    [pyro.c]
2016-03-17 Implemented transmit error detection
    [pyro.c]
2016-04-23 Bigger manual update: New transmitter-toner-transfer-template Hints for maximum resistance and show planning
2016-04-23 Added Gerber Files
    [El-Fueradoro_Transmitter.brd, El-Fueradoro_Transmitter.sch, El-Fueradoro_Zuendbox.brd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]
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2016-05-08 Formatting issues in terminal output fixed Transmitter now always showing Rx-RSSI Rewritten uart_shownum to avoid compiler warnings Put filenames in quotes in build_hexfiles.bat Updated hexfiles
    [pyro.c, terminal.c, uart.c]
2016-09-08 Beautified bills of material and fixed cross-references
2016-11-24 Correct transmission of transmitter's armed-status
    [pyro.c]
2016-12-01 Handling of pin in case of missing temperature sensor
    [pyro.c]
2017-05-25 Larger update: Frequency deviation adaption Bills of Material No more RFM12-support
    [El-Fueradoro_Zuendbox_v2.brd, El-Fueradoro_Zuendbox_v2.sch]
2017-07-22 Bugfix in Zündbox_v2-Gerber-Files Kompiliert mit AVR-GCC 8
    [El-Fueradoro_Zuendbox_v2.brd]
2017-10-01 BOM correction
2017-10-25 BOM fixes
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2018-01-05 Angleichung von Handbuch und Layouts
    [BOM.ods, El-Fueradoro_Zuendbox_v2.brd, El-Fueradoro_Zuendbox_v2.sch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]
2018-05-14 Workaround for string comparison
    [pyro.c, pyro.h, rfm69.h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]
2018-08-20 v3-bugfix for impedance calculator
    [adc.c]
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2018-09-08 Working and tested v3 with channel LEDs and impedance measurement
2018-09-08 Added some v3-documentation
    [Zuendbox_v3.kicad_pcb, Zuendbox_v3.sch]
2018-09-15 KiCad version
    [Zuendbox_v3.sch]
2018-09-17 Manual update
    [Zuendbox_v3.kicad_pcb]
2018-10-15 v3 impedance update now triggerable by turning key switch
2018-10-16 Static "if" replaced by preprocessor-"#if"
    [pyro.c]
2019-01-18 Repaired inconsistencies in images
    [El-Fueradoro_Zuendbox_v2.sch]
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2019-05-31 Minor fixes on transmission delays
    [pyro.c]
2019-09-29 Timestring-Fix and LED signaling bugfix
    [pyro.c, rfm69.c]
2019-09-29 Timestamp fix and LED fix for v3
    [1wire.h, adc.c, dm13a.h]
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2019-10-11 Fixed another MAX_ID/MAX_COM_ARRAYSIZE confusion Hexfiles compiled with MAX_ID=50
    [terminal.c]
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2019-12-08 Replaced hardcoded channel maximum number with define
    [pyro.c]
2020-01-03 Manual update, 32-channel-files
    [Zuendbox_v3_32.sch]
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2020-03-16 Bugfix concerning impedance measurement on armed slaves
    [pyro.c]
2020-03-28 KiCad schematic files for Raspberry Pi pcb
    [rfm_adapter_pi.kicad_pcb, rfm_adapter_pi.sch]
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2020-05-12 Changed RF parameters (smaller deviation, smaller rx bandwidth)
    [Zuendbox_v3.sch]
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2020-05-30 Bugfix and code cleanup for proper function of RFM69HCW
    [pyro.c]
2020-06-08 Corrected wrong GPIO for RFM-CS in v1/v2
    [rfm69.h]
2020-06-09 Added RFM init fail indicator (orange and green LED permanently on)
    [pyro.c, rfm69.c, rfm69.h]
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2020-11-23 Delivering RSSI value as part of parameter protocol Fixed typo in manual
    [pyro.c, pyro.h]
2021-05-01 Initial state bugfix for channel LEDs on mini module
    [pyro.c]
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2021-07-30 MiniModul-Bugfix: Channel LEDs now turning off after being triggered remotely
    [adc.c, pyro.c]
2021-08-21 Reset channel timeout counter every time a channel is triggered - making retriggering possible while channel already active
    [pyro.c]
2021-09-14 Changed output for terminal command hw to enable device identification (number of channels and RFM type)
2022-03-31 Fixed inconsistent init of RFM register
    [pyro.c, rfm69.c]
2022-04-01 Avoid timeout if other boxes send impedance lists
    [pyro.c]
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2022-12-20 Short wait after OE enable for debug purpose
    [pyro.c]
